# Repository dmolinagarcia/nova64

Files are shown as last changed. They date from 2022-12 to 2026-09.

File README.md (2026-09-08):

# noVa64 

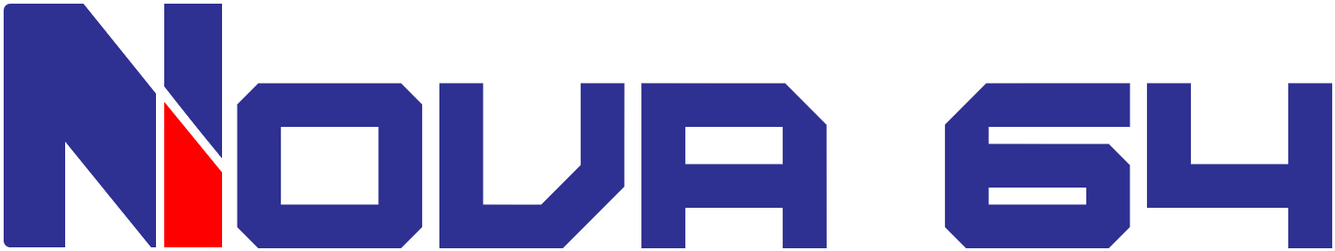
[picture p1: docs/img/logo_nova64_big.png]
noVa64 logo


**What it is noVa64?**

The noVa64 (With an uppercase V) is a new computer built around the 65816 CPU. Inspired by the age of 8-bit computers, it's envisioned as a alternate-universe succesor to the Commodore 8-bit series of computers. Instead of adquiring the Amiga, could've Commodore created a 16-bit machine around this CPU? The noVa64 is designed and built by a hobbyist (me) who will need to learn pretty much everything on the go.

**What it isn't noVa64?**

It's not a professional or commercially viable product.  It's not meant to be mass produced. It's not a recreation of any pre-existing computer, although it will be inspired by many.

**When will it be ready?**

Hopefully, at some point. That's all I can say.

## Principles

- Not here for the money. This is not meant to be a commercial product
- Hence, no restrictions on parts (Used, obsolete, questionable sources)
- Learn from scratch. No off-the-shelf solution
- Inspiration on others is encouraged though
- Give credit to all sources of information
- Everything will be open sourced, under the GNU v3 License
- Log all the steps
- No deadline. 
- Learn
- Have fun

## Requirements

### Form factor

- Computer should be a laptop, fully portable

### Power

- Single and low voltage. 5v is very obsolete. At least 3.3v, maybe even lower
- Battery powered
- USB-C Charger, allowing for fast charge if possible
- Battery pack reports to the computer. Charge status, capacity, etc
- Computer then display this

### CPU

- Based around a 65816. Real CPU, no FPGA here
- DRAM. Maximum memory at 16MB for the CPU 
- SRAM cache for the main DRAM

### Chipset

- Set of sustaining chips
- FPGA acting as MMU, handling DRAM, with potential for bigger RAM
- IO/TIMER. Could use a 6526 in FPGA maybe. TIMERs need to be driven by independent clock
- RTC. Used to keep time. Can act as TIMERS too for interrupts

### Video

- At least 640x400 (Twice a C64). 256 colors
- FPGA is allowed here
- Built in Laptop Screen
- External monitor an option (mirror, or extend if possible)
- VGA or HDMI for external monitor
- Brightness controlled via software
- Still not sure about dedicated video RAM

### Audio

- Stereo audio and built-in speakers
- FPGA is allowed here too
- External audio an option (Through audio jack, or, if possible HDMI)
- Volumen control through software

### Peripherals

- USB Support for storage, and HID
- Internal keyboard and trackpad are USB
- External ports too

### Storage

- Dual SD. One acting as internal hd, one acting as eternal storage

### Connectivity

- Is TCP/IP Possible? Wifi? Ethernet?

### Boot sequence

- Small ROM to handle booting. Then, SO from "INTERNAL" sd is loaded into meemory

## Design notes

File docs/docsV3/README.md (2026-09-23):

# docsV3 — the synthesis document, in Markdown

Same document as `docsV2`, same stylesheet, same look: only the source changed.
Each sheet is now a `.md` file under `content/`, and `index.html` turns it into
the page at load time with `md.js` (renderer) and `app.js` (shell and router).
Nothing in `docsV2` was touched — this is a parallel copy.

```
index.html          the paged edition: one sheet at a time
full.html           every sheet in one scroll, for printing
theme.js            the light/dark switch, applied before the first paint
md.js               markdown → HTML for the dialect below
hl.js               syntax highlighting for fenced code blocks — a per-language
                    scanner, not a parser, in the document's own five colours
shell.js            figure inlining and the failure state, shared by both pages
app.js              sidebar, masthead, sheet index, pager, title block, routing
full.js             the same pieces, assembled as one continuous document
manifest.json       the parts registry, and the sheet list: letter, part, area, nav
                    and index titles, figure
tools/prerender.js  assembles the printable edition ahead of time, for a PDF
                    formatter — page numbers live there, see Printing
tools/links.js      the cross-reference listing: source sheet -> linked section,
                    per sheet or whole-document, and the broken links, see Routes
tools/numbers.js    assigns the figure and table numbers across the reading order
                    and writes numbering.json — see Figure and table numbers
numbering.json      those numbers, the one derived thing this document stores
                    because a single sheet cannot work it out; committed
style.css           docsV2's stylesheet, plus the few rules these two pages add
content/*.md        the prose — one file per sheet
figures/*.svg       the diagrams, one file each
```

## Parts, areas, sheets

Three levels, and only `manifest.json` knows about any of them.

**A part** comes from the `parts` array, which is a *registry* rather than a run:
it fixes the order of the parts and their display names, and it is why a part
holding no sheets still appears in the sidebar and the index. Each sheet names
one with a `part` field.

```json
"parts": [
  { "id": "hardware", "num": "2", "name": "Hardware", "note": "" }
],
"sheets": [
  { "file": "sec_c", "letter": "C", "part": "ai", "area": "Power", … }
]
```

**An area** is still a run: consecutive sheets *within a part* carrying the same
`area` get one heading in the sidebar, one band in the sheet index, and one rule
across the page on `full.html`. A part gets the same treatment one level up — a
framed bar, and its own page in print, with its first area following on it.

**The order is: parts as the registry lists them, sheets as the array lists them
within each part.** So moving a sheet to another part is a **one-field edit** —
change its `part`, and the sidebar, the index, the numbering and the printed
page breaks all follow. Moving a sheet within its part still means moving its
row. A sheet naming a part that is not in the registry is not dropped: it lands
in a trailing "Unassigned" group that says so.

**Positions are derived, never stored.** There is no `num` field: `NovaShell.prepare`
resolves parts and areas into one reading order and numbers the sheets from it,
so inserting a sheet anywhere renumbers the rest by itself.

**So is the masthead's reference line.** `footer.referenceIndex` may contain
`{parts}`, `{areas}` and `{sheets}`, and `prepare` fills them from what it has
just resolved — the registry, the named area runs inside it, and the reading
order. It used to spell the sheet letters out, which left it a little further
from the truth after every split.

**The title block's revisions are a list.** `footer.revs` holds one entry per
area — `"POWER REV C"` — and `shell.js` sets each on a line of its own, so the
cell stays readable as the areas multiply. Under them, ruled off, `footer.version`
and `footer.date` close the block.

**The letters follow neither, and are never reissued.** A letter is a sheet's
identity — the file name (`sec_r.md`), the route (`#/sec_r`), and every
cross-reference in the prose — while its number is only its position. The two
stopped agreeing when the areas were introduced, and that is the point:
reordering the document costs a manifest edit instead of several hundred link
rewrites.

**Everything currently sits in the `ai` part**, which is where a sheet lives
until a human has read it; it moves to its real part when it has been reviewed.
Six of the seven parts are therefore empty, and that is the state of the review
rather than a hole in the design.

## Running it

The sheets are read with `fetch()`, which browsers refuse over `file://`, so
open it through a server — any server:

```
python3 -m http.server -d docs/docsV3
```

then <http://localhost:8000/>. On GitHub Pages it works as-is: the `.md` files
carry no YAML front matter, so Jekyll copies them through untouched.

## Printing

`full.html` is the same content with the sheets chained one after another —
masthead, sheet index, then the parts and their areas in order — and it is what
to send to the printer or save as PDF. It prints in sections: the masthead is
the cover and has the first page to itself, page two is left blank behind it,
the sheet index takes page three, and every part and every area opens on a fresh
page, while within an area the sheets run on rather than each claiming one. The
cover's drop — how far down the page the title block sits — is
`body.full .main{ padding-top }` in the print block, in millimetres. The print
stylesheet drops the sidebar and the navigation the way it always did. The sheet
index becomes a working table of contents, because on that page every
cross-reference is an in-page jump: ids are prefixed with their sheet
(`#sec_p-e2`, `#sec_ai_f-f-memmap`) so that E.2 in sheet E and E2 in sheet P stop
colliding, and so that two sheets may each anchor a figure of their own. The
sidebar of the paged edition links to it at the bottom of the sheet list.

### Figure and table numbers

A caption declares an identifier and never a number:

```markdown
![F.memmap.Memory structure. The SRAM hangs off the CPU's own nets.](figures/fig-4-memory-map.svg)

![T.banks.The sixteen banks and what each holds]

| Bank | Holds |
|---|---|
```

and the prose points at that identifier — `![F.memmap]`, `![T.banks]` — which
renders as `Figure 7` or `Table 3`, linked. **No number is ever written by
hand**, so inserting a figure renumbers the set and leaves every cross-reference
already correct. An identifier is `[A-Za-z0-9_-]+` and **may not contain a
dot**, which is what lets the first dot after `F.`/`T.` close it. A table with
no caption above it is not numbered and does not reach the list of tables —
most tables are a paragraph's worth of detail, not a numbered exhibit.

The numbering runs across the whole document in the reading order `prepare`
resolves, figures and tables in separate sequences. That is the one thing a
single sheet cannot work out for itself: `index.html` renders one sheet at a
time, and the number of a figure in sheet F depends on how many stand ahead of
it everywhere else. So it is worked out once, ahead of time:

```
node tools/numbers.js            assign the numbers, write numbering.json
node tools/numbers.js --check    verify it is current — exit 1 if not
```

`numbering.json` **is committed**, unlike `print.html` and `pdfs/`: GitHub Pages
serves `docs/` verbatim with no build step, so an artefact left out of the
commit is a 404 in production. Run `--check` before committing and before a PDF,
alongside `tools/links.js --broken`; it also catches a duplicate identifier, a
reference that resolves to nothing, a caption with no table under it, and a
missing SVG. Without the file the pages still render — every number shows as
`?` and every reference as `⟨F.memmap⟩` — because the markdown may well land in
a checkout before the artefact is regenerated, and a document that refused to
render would be the worse failure.

`FIGURES` and `TABLES` put the generated lists in a sheet ([Z2](content/sec_ai_z2.md)),
which is why those appendices hold no table of their own.

### Page numbers

Two things the browser cannot do: a running page number in the bottom margin,
and the page a sheet opens on beside its row in the index. Both are CSS paged
media — `@page` margin boxes and `target-counter()` — and **no browser
implements either**, so Chrome and Firefox drop those rules and print exactly
what they printed before. They need a formatter, and a formatter needs a static
file, because `full.html` assembles itself in JavaScript and WeasyPrint and
Prince do not run any.

```
node tools/prerender.js          # -> print.html, beside index.html
weasyprint print.html nova64.pdf
```

`tools/prerender.js` does not reimplement anything: it runs the real `md.js`,
`hl.js`, `shell.js` and `full.js` under Node against the real manifest and markdown,
captures what they would have written into the page, inlines the figures the way
`shell.js` does in the browser, and writes one static file that links the same
stylesheet. Change a sheet or the manifest and it follows. `print.html` is a
build artefact and is not committed.

Any formatter that implements paged media will do — `npx @vivliostyle/cli build
print.html -o nova64.pdf` is the other open one, and Prince is the best output if
its licence suits. WeasyPrint prints a column of warnings about screen-only rules
it cannot parse (`::-webkit-scrollbar`, `position:sticky`, `fill` inside the SVG
rules); all of them are screen or SVG presentation and none affects the PDF.

**Only the sheet rows carry a number.** A part or an area opens on the sheet
immediately below it, so numbering those rows would print the same number twice.
The cover and the blank verso behind it carry none either, which keeps every
printed folio equal to the page number a PDF reader shows.

## Light and dark

The button above the masthead switches themes; the choice is remembered in
`localStorage`, and until one is made the page follows the system setting. The
palette is six custom properties on `:root` — ground, ink, panel, mint, gold, and
`warn` for the warning box alone — and the light theme only redefines those, so
nothing else in the stylesheet knows a theme exists. The first five are the
document's look and every rule draws on them; the sixth is deliberately spent on
one construct, because a warning wearing the gold would be read as a milestone.

**It stops at the screen.** The light theme lives inside `@media screen`, and
the print block restates every colour itself, as it already did for docsV2's
dark ground. Printing from either theme gives the same black-on-white page.
The one thing a new colour needs is care in two places: shapes inside the
figures that carry their colour as an attribute rather than a class are listed
explicitly in both the print block and the light theme.

## Routes

`#/` is the sheet index, `#/sec_e` a sheet, `#/sec_e/e4` a sheet scrolled to one
of its items. Inside the markdown you write the target the way docsV2 wrote
filenames — `[sheet E](sec_e)`, `[F.4](sec_f#f4)`, `[Sheet index](index)` — and
the renderer turns it into the route.

`tools/links.js` lists them. It reads every sheet the way `md.js` does, resolves
each target against `manifest.json` and the items the target sheet actually
defines, and prints one line per link — source file, then the section it points
at:

```
node tools/links.js              # the listing, grouped by source sheet
node tools/links.js --reverse    # the same links, grouped by target
node tools/links.js --broken     # only the ones that resolve to nothing
node tools/links.js --csv        # source,line,text,target,anchor,item,status
node tools/links.js --summary    # links out and in per sheet, and the orphans
```

Name a sheet — as `sec_q` or as `content/sec_q.md` — and the listing narrows to
it: what it links out to, then what links in, with the item on each end. That is
what to run before moving a sheet or rewriting one of its items, since the IN
list is exactly what would have to be corrected.

```
node tools/links.js sec_q             # both directions for sheet Q
node tools/links.js sec_q --broken    # only the broken ones, either way
node tools/links.js sec_q --csv       # the same rows, as CSV
```

A link to a sheet that does not exist, or to an item id no sheet defines, is
reported as broken and the exit status is 1, so it also stands as a check.

## The dialect

A sheet file opens with its title and its aim, and everything after that is
content:

```markdown
# Vision and philosophy
> what it is · what for · under what rules

Project framework: what is being built, and what principles govern it.
```

`#` becomes the sheet heading, `>` the small uppercase aim beside it. The sheet
letter and number are not repeated here — they live in `manifest.json`.

### Blocks

| You write | You get |
|---|---|
| a plain paragraph | `p.lead` — the standing text of a sheet |
| `## Register map — base block $FF:0000` | sub-heading: bold up to the ` — `, plain after it |
| `### Hardening door B` | the same, one level down and a little tighter |
| `- A.1 — text` | a numbered item: `A.1` in bold at the head, text beside it, anchored at `#a1` |
| `1. text` | the same row, its number where the id would be, and no anchor |
| `  1. text` indented under an item | a numbered list inside the item: the written number hung in the margin, one line per entry |
| `- [ ] E0.1 — text` | the same, with a build checkbox in front |
| `!!! APPLE II MILESTONE — …` | the milestone banner — a framed band with a `■` at its head |
| `!! AVISO — …` + the lines under it | the warning box — see below |
| `\| Term \| Meaning \|` + `\|---\|---\|` | `table.simple` |
| `![F.id.Description](figures/f.svg)` | the figure, its SVG inlined so the stylesheet reaches it — captioned `Figure 7.` and anchored at `#f-id` |
| `![T.id.Description]` above a `\|`-table | the table's caption, `Table 3.`, anchored at `#t-id` |
| `LEGEND: …` after a figure | the small trace legend under the caption |
| ` ```c ` … ` ``` ` | a code listing, highlighted for that language — see below |
| ` ~~~bash ` … ` ~~~ ` | the same, for a listing that itself contains a line of backticks |
| `---` on its own line | nothing — a rule, dropped, since the sheets space themselves |
| `<!-- file: srv/dev/bin/dev -->` + a fence | a file of the kit: the listing under a caption naming it — see below |
| `INDEX` | the sheet-index table, built from `manifest.json` |
| `FIGURES` · `TABLES` | the list of figures, or of tables, built from `numbering.json` |
| `TAGS:` + `- [g] …` list | the masthead tag row (index page only) |

Checkbox states: `[ ]` pending · `[x]` done · `[~]` in progress · `[?]` optional.
The item id is free text — `A.1`, `E0.1`, `D07`, `+` — and its anchor is that id
lowercased with the dots dropped, which is what every cross-reference points at.

### The warning box

`!!!` is a milestone and `NOTE:` is an aside; neither is a warning, and the one
the sheets actually need — the step that can cost the reader money — was coming
out as the dimmest line on the page. `!!` is the third thing: a framed box on a
tinted ground with a thick rule down its left edge, in a red-amber that belongs
to it alone.

```markdown
!! AVISO — this step can cost you money.
Free-tier limits change, and a mistyped shape can leave a billable instance
running. Check the shape before you confirm it.
  A second paragraph inside the box, indented like any continuation line.
```

The `!!` line is the box's heading — bold up to the ` — `, plain after it, the
way a `##` sub-heading reads — and the lines under it are its body, **through
the next blank line**. Unindented lines run together into one paragraph; an
indented line opens another, exactly as it does under an item — with no blank
line before it, since a blank line is what closes the box. The inline pass
applies throughout, so links, `code` and chips work inside. A `!!` line on its
own, with no body under it, is a legal one-line warning.

On paper the ground goes and the left rule stays, darkened — the same treatment
the chips and the figure traces get. No mark in the document is told apart by
its colour alone, which is the rule sheet A states as A.17: the box is known by
its rule, a blocking chip by its fill against an open one's frame, and a trace
by its pattern and its weight. Colour repeats those on screen and adds nothing
the paper edition loses.

### Code listings

A fenced block, with the language after the opening fence. It may sit at the
margin or hang off an item like a `NOTE:`, and the fence's own indentation is
stripped either way, so both read the same. `~~~` opens and closes one too, and
is closed only by `~~~` — which is what a listing containing a line of backticks
needs, and the reason sheet EM0 can carry the script that extracts sheet EM0. The content is verbatim — no inline
pass, so `**` and `[link]()` inside a listing stay as typed.

`hl.js` highlights it while the page is built, not in the browser, because
`tools/prerender.js` runs the same renderer to make the printable edition:
highlighting at render time is what puts colour in the PDF. Six token classes,
because the palette has five colours and no more — comment, string, number,
keyword, type, directive — and they resolve to gold for literals, mint for
names, dimmed italic for comments, in every theme and on paper.

It knows `c`, `asm` (ca65 65816), `js`, `json`, `python`, `sh` and `make`.
**An unknown or absent language is escaped and left plain**, which is the right
answer for a register bit-layout or a vector table, and the reason to leave the
fence bare when a listing is not code.

### Files the document carries

A listing under a `<!-- file: path -->` marker is not an illustration: it is one
of the files the document *is*, and the marker is what the extractor at the top
of sheet EM0 reads to write it out. The renderer reads the same marker and draws
one distinction from it, which is what keeps the printed edition a book rather
than a program listing.

The listing gets a caption naming the file and giving its size, as lines and
bytes — checkable at the other end with `wc -lc`, which is the reason it is a
size rather than a hash. **Past `LONG` lines in `md.js`, the block also folds on
screen and prints as its caption alone**, since the document tells the reader
never to retype these files and paper is the one medium they cannot be copied
from. Below that threshold a file prints whole, so the configuration a reader
wants in front of them stays in the book while the long shell scripts do not.

Sheet EM0 is the case this exists for: eleven files, of which four are long
enough to fold, and the rest of its fenced blocks are ordinary listings that
carry no marker and are unaffected.

It is a scanner, not a parser: it recognises comments, strings, numbers and
words, and nothing about grammar. A label sharing a name with a mnemonic will be
coloured as one. That is the deliberate ceiling — a real tokeniser is not worth
carrying into the PDF build for a document whose listings are illustrations.

### Lines that attach to the block above

```markdown
- E1.2 — **Cross-review before layout.**
  TEST: clean ERC, plus a manual pin-by-pin pass of every TQFP.
- E0.6 — **Freeze the block diagram** as the schematic's reference.
  NOTE: Currently at REV B and well behind this document (→ [A.7](sec_a#a7)).
```

`TEST:` renders as the *TEST ▸* line, `NOTE:` as the dimmed aside. Both
also work under a paragraph or a `##` sub-heading.

Any other indented line attaches the same way, but as a further paragraph of the
block at full weight — one line, one paragraph — so an item that needs to run on
does so without leaving its number:

```markdown
- A1.1 — v0.2 of this documentation is the result of a very long dialogue…
  noVa64 is an amateur project. There will be lots of errors…
```

### Inline

| You write | You get |
|---|---|
| `**bold**` · `*italic*` · `` `code` `` | `<b>` · `<i>` · `<code>` |
| `[text](sec_q#q8)` | a link, rewritten to the route `#/sec_q/q8` |
| `[[open]]` | an outline chip |
| `[[!blocking]]` | a filled chip |
| `((an aside))` | an inline `.note`, for when it sits mid-sentence |
| `![F.id]` · `![T.id]` | `Figure 7` · `Table 3`, linked to it — never a number written by hand |
| raw HTML | passed through — the escape hatch, used by the figure legends for their line samples |

## Adding a sheet

Write `content/sec_s.md`, add its row to `manifest.json` (`file`, `letter`,
`part`, `area`, `nav` for the sidebar, `index` for the index table). Sidebar,
index, pager, numbering and title block follow from that; no HTML to edit.

Put its row next to the other sheets of the same area **inside its part** — the
array's order is what the reader sees within a part. There is nothing to
renumber: positions are derived from the resolved order.

A new sheet starts in the `ai` part unless it was written by a human, in which
case it goes straight to the part it belongs to.

The appendix is deliberately the **last** thing in the document and deliberately
lettered **Z**, and it is two sheets: the glossary in `content/sec_z1.md` and the
index of figures in `content/sec_z2.md`. Content sheets run A, B, C… and a new
one takes the next free letter of that run, without the appendix having to move
or any letter having to be reissued — which is also why splitting the appendix
took a suffix rather than the next free letter. Letters and file names are kept
in step — sheet R lives in `sec_r.md`, appendix sheet Z2 in `sec_z2.md` —
because every cross-reference in the prose points at the file name.

**A numeric suffix means one subject too large for one sheet**, and there are
three such runs. `Z1`/`Z2` is the appendix. `Y1`/`Y2`/`Y3` is the filesystem
stack — the VFS layer, NVFS and ext2 — which is one subject three ways rather
than three subjects, and which took a suffix for the same reason the appendix did
rather than because the alphabet had run short. `P1`/`P2`/`P3`/`P4` is the build,
one sheet per phase. Item ids inside a suffixed sheet carry the whole letter:
`Y2.15` anchors at `#y215`, and cross-references are written
`[Y2.15](sec_y2#y215)`.

**The build sheets are the one place where item ids and stage ids sit side by
side, and they are different things.** A dotted id is a discussion item and takes
the sheet's letter — `P2.11a` on sheet P2, `P4.3` on sheet P4. An undotted id is
a build stage and takes its *series* letter, which is independent of the sheet it
is printed on: the S-series on P1, the P-series on P2, the E-series on P3, the L
and F series on P4. So `P3.d` is a substep of prototype stage P3 and lives on
sheet P2, while sheet P3 holds `E0.1` through `E8.1`. Series ids never move when
a sheet is split; that is what kept the split from rewriting several hundred
references.

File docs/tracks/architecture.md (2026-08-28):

---
layout: track
track: architecture
title: "Track · Architecture"
permalink: /tracks/architecture/
redirect_from: /categories/architecture
---

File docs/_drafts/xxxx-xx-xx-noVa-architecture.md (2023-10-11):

---
categories: architecture
---

Necesito un diagrama de bloques... que hay en la fpga?

cpu fpga
        uart
        hid
                keyboard
                console in
                mouse
        console out
        storage
        video
        cache
        powermanagement
        audio
        network
        6526 or equivalent?
        rtc? rtc será externo por consumo

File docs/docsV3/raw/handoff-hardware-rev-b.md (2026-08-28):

# DANI-65816 — Hardware Handoff (REV B)

**Date:** August 2026
**Scope:** Board-level architecture, memory hierarchy, pin budget, PTE format.
**Status:** Hardware frozen at block level. Ready for pin assignment and schematic capture.

---

## 1. Purpose of this document

This handoff captures the state of the DANI-65816 hardware design after the REV B
consolidation pass. It supersedes earlier notes where they conflict — in particular,
several components present in REV A have been **removed**, and the memory hierarchy has
been substantially simplified. Section 7 lists those removals explicitly so that no
obsolete part is carried forward into schematic capture.

The machine is an original portable computer built around the Western Design Center
W65C816S, a 16-bit CPU with a 24-bit address bus. It is not compatible with, and not
derived from, any existing 65816-based system. The design goal is a self-built portable
with virtual memory, memory protection, and a preemptive multitasking OS.

Two success milestones govern the project:

- **"Hito Apple II"** — the machine boots autonomously to a prompt.
- **"Hito Amiga"** — preemptive multitasking with a windowed GUI.

---

## 2. Global constraints

These constraints are non-negotiable and have driven most of the decisions below.

| Constraint | Consequence |
|---|---|
| All parts hand-solderable (TQFP / PLCC / TSOP, ≥0.5 mm pitch) | BGA packages excluded; iCE40 in TQ144 chosen over ECP5 in BGA256 |
| Single 3.3 V I/O rail | DDR3 excluded (1.35/1.5 V); SDR SDRAM and asynchronous SRAM retained |
| Fully open toolchain | Lattice iCE40 with Yosys / nextpnr / IceStorm |
| Portable form factor | Battery, charger, fuel gauge, integrated panel |

---

## 3. Board block architecture

```
   USB-C ──┬── MCP73871 (charge + power path) ── LiPo 1S ── MAX17048 (fuel gauge)
           │        │
           │        └── TPS63020 ── 3.3 V system rail ── LDO 1.2 V (3× FPGA cores)
           │
           └── RP2040 (embedded controller)
                 ├── config SPI ──────► FPGA-A, FPGA-B, FPGA-C
                 ├── SPI ─────────────► microSD (muxed with FPGA-A)
                 ├── PIO-USB host ────► USB-A (keyboard / mouse HID)
                 ├── I2C ─────────────► MAX17048, GT911 touch
                 └── USB-CDC ─────────► debug console

   W65C816S (PLCC-44 socket) ──┐
                               ├── shared 65816 bus ──► FPGA-A
   FPGA-C (softcore, optional)─┘

   FPGA-A (iCE40HX4K TQ144) — MMU, cache controller, peripherals
       ├── shared 16-bit parallel bus ──► SRAM 2 MB + SDRAM 32 MB
       └── VRAM_SEL / IRQ VSync ────────► FPGA-B

   FPGA-B (iCE40HX4K TQ144) — video and audio
       ├── local PSRAM 8 MB (chip RAM: framebuffer + audio buffers)
       ├── RGB-TTL ──► 10.1" 1024×600 panel (ER-TFT101-1, HX8282)
       └── I2S ─────► PCM5102A DAC
```

---

## 4. Component decisions

### 4.1 CPU

- **W65C816S in a PLCC-44 socket.** Socketed rather than soldered so the part can be
  swapped or removed during bring-up.
- **PHI2 is generated by FPGA-A**, not by an external oscillator. This allows clock
  stretching on cache miss, variable clock for power saving, and exact CPU/MMU
  synchronisation.
- **Bus arbitration via BE (Bus Enable).** Driving BE low tri-states the real CPU, which
  allows the optional softcore in FPGA-C to drive the *same* physical traces. No second
  footprint and no desoldering: the real CPU can remain in its socket permanently.
- The bank address (A16–A23) is multiplexed onto the data bus during PHI2 low and is
  latched **inside FPGA-A**. No external '573 latch is required.

### 4.2 FPGAs

Three iCE40HX4K devices in TQ144 packages. All three are configured by the RP2040 over
slave SPI at power-up.

| Device | Role | Populated |
|---|---|---|
| FPGA-A | MMU, cache controller, memory arbitration, peripherals | Always |
| FPGA-B | Video and audio | Always |
| FPGA-C | Softcore 65816 | Optional, unpopulated initially |

Moving the softcore out of FPGA-A into its own device returns block RAM and routing
resources to the memory subsystem, and lets the softcore's clock be optimised
independently of MMU timing.

**Known iCE40 limitation:** block RAM is approximately 16 KB per device. This is far too
small for flat page tables and is the direct cause of the memory layout in section 5.

### 4.3 Memory (FPGA-A)

| Part | Size | Interface | Role |
|---|---|---|---|
| IS61WV102416 | 2 MB | 16-bit async, 10 ns | Cache + page tables + pinned region |
| W9825G6KH | 32 MB | SDR SDRAM, 16-bit, 3.3 V | Main memory (physical frame pool) |
| microSD | — | SPI | Boot, filesystem, swap |

Both memories **share the same 16-bit parallel data bus and low address lines.** The
SDRAM requires only 7 additional control signals (CLK, CKE, CS, RAS, CAS, DQML, DQMH)
beyond what the SRAM already needs.

**Trade-off accepted:** because the bus is shared, a cache line fill serialises —
SDRAM burst into the FPGA, then FPGA out to SRAM, rather than overlapping. Miss latency
rises accordingly, but remains in the 200–300 ns range, far better than the QSPI PSRAM
path it replaced.

### 4.4 Video and audio (FPGA-B)

- **Panel:** ER-TFT101-1, 10.1", 1024×600 IPS, HX8282 controller, FPC-50, driven
  directly by RGB-TTL from the FPGA. Timing is generated natively; there is no scaler.
- **Pixel doubling:** the internal framebuffer is 512×300 and is doubled to 1024×600 on
  output. This keeps memory bandwidth within budget.
- **Local PSRAM (APS6404L, 8 MB)** serves as chip RAM for double-buffered framebuffer
  plus audio buffers. This is the one PSRAM that survives in the design — FPGA-B needs
  local memory with its own access path and cannot share FPGA-A's bus.
- **Bus topology is Amiga-style:** FPGA-B taps the CPU bus directly. The CPU writes VRAM
  through a 64 KB aperture at bank `$FE`, gated by a VRAM_SEL signal from the MMU. There
  is no dedicated inter-FPGA link.
- **Audio:** PCM5102A I2S DAC driven by FPGA-B. Backlight brightness is PWM from FPGA-B
  into a boost converter.
- **Touch:** GT911 capacitive controller on I2C, handled by the RP2040.

### 4.5 Embedded controller (RP2040)

The RP2040 fills the role of the small management microcontroller, and additionally
provides native USB. Responsibilities:

- Power sequencing and rail control; battery management via MAX17048 over I2C.
- Configuration of all three FPGAs over slave SPI (CRESET_B / CDONE handshake).
- BIOS preload: reads the BIOS image from microSD and writes it into system RAM before
  releasing CPU reset.
- USB-CDC debug console.
- USB HID host via PIO-USB, feeding keyboard and mouse events to FPGA-A.
- Its own firmware lives in a W25Q16 SPI flash and is updated over USB (UF2).

### 4.6 Power

```
USB-C ─► MCP73871 (charge + power path) ─► VSYS ─► TPS63020 buck-boost ─► 3.3 V
                                                       ├─► LDO 1.2 V (3× FPGA cores)
                                                       ├─► TPS61023 boost 5 V (USB VBUS)
                                                       └─► PT4110 boost (backlight)
LiPo 1S 3.7 V ── MAX17048 fuel gauge (I2C: state of charge, voltage, alerts)
```

The MCP73871 power-path topology allows the machine to run from USB with a fully
depleted battery. FPGA VPP (2.5 V) is derived through BAT54 diodes.

---

## 5. SRAM partitioning

The 2 MB SRAM is divided by address range in FPGA-A gateware. It is a single physical
chip; the partitioning exists only in the memory controller's decode logic.

| Range | Size | Contents |
|---|---|---|
| `$000000–$0FFFFF` | 1 MB | Cache: 4096 lines × 256 B |
| `$100000–$17FFFF` | 512 KB | Page tables: 16 contexts × 32 KB |
| `$180000–$1FFFFF` | 512 KB | Pinned region: kernel and per-process bank `$00` |

Three consequences worth carrying forward:

1. **The pinned region is a physical address range, not cache lines marked
   non-evictable.** Accesses to bank `$00` bypass tag lookup entirely and complete in a
   single cycle with fixed latency. This is both simpler and faster than the previous
   scheme.
2. **The hardware page-table walker becomes trivial.** With tables in 10 ns SRAM, a walk
   is one add and one read: `$100000 + context×32K + VPN×4`, two 16-bit accesses,
   roughly 4 cycles. A software TLB-miss trap is unnecessary; the OS only ever
   manipulates tables, never the TLB directly.
3. **Block RAM is freed for its proper use:** the TLB, cache tags (4096 tags fit in
   about 6 KB), and FIFOs.

---

## 6. Page table entry format

```
 31                            16 15 14 13 12 11 10  9  8  7        0
┌────────────────────────────────┬──┬──┬──┬──┬──┬──┬──┬──┬──────────┐
│         FRAME[15:0]            │P │W │X │U │D │A │NC│PIN│ SW[7:0] │
└────────────────────────────────┴──┴──┴──┴──┴──┴──┴──┴──┴──────────┘
```

Page size is 2 KB, giving 8192 pages per process and a **32 KB flat page table per
process** (8192 entries × 4 bytes). Sixteen contexts therefore occupy exactly the 512 KB
table region defined in section 5.

Note that this supersedes an earlier estimate of ~16 KB per table, which assumed 2-byte
entries. The 32-bit PTE is what makes the 16-bit frame field — and the 128 MB ceiling —
possible.

**FRAME[15:0]** — physical frame number. Physical address = FRAME × 2048 + offset(11
bits) = 27 bits, giving a **128 MB physical ceiling**. Current frame map:

- `$0000–$3FFF` — SDRAM, 32 MB
- `$FF00–$FFFF` — the 512 KB pinned SRAM region (256 frames)
- Intermediate range reserved for future expansion

**Hardware-checked flags:**

| Bit | Name | Behaviour |
|---|---|---|
| P | Present | P=0 on any access → ABORT. When P=0, bits 31–16 are free for the OS to store the swap slot on SD |
| W | Writable | Write with W=0 → ABORT. Also provides copy-on-write |
| X | Executable | Fetch with X=0 → ABORT. The 65816 **VPA** signal identifies instruction fetch cycles, so the check is a simple AND |
| U | User-accessible | User-mode access with U=0 → ABORT |
| D | Dirty | Set by hardware via read-modify-write to the PTE in SRAM |
| A | Accessed | Set by hardware; OS reads and clears to select swap victims |
| NC | Non-cacheable | Frame bypasses the cache |

**Software-only bits:** PIN (do not evict — ignored by the walker) and SW[7:0], free for
the OS (age counter for replacement, COW marker, and so on).

**Privilege mode.** The 65816 has no privilege bit, but it does assert **VPB** (vector
pull) when reading an interrupt or COP vector. The MMU uses VPB to switch to supervisor
mode automatically. Returning to user mode is a write to a register in bank `$FF`, which
is itself only writable in supervisor mode — the self-protecting keystone of the
protection scheme.

**TLB entry:** `VPN(13) + ASID(4) + FRAME(16) + W, X, U, NC` ≈ 37 bits. Including the
ASID (the context number) avoids flushing the TLB on every context switch; switching
processes remains a single register write with no collateral cost. 64–128 entries in
block RAM are sufficient for a 65816 working set.

**Fault registers in bank `$FF`** required by the ABORT handler:

- `FAULT_ADDR` — faulting virtual address, 24 bits
- `FAULT_CAUSE` — ¬P / ¬W / ¬X / ¬U, plus a fetch/data bit
- `CONTEXT` — active ASID
- `MODE` — supervisor/user, writable only in supervisor mode

---

## 7. Removed from the design

These parts appeared in earlier revisions and must **not** be carried into schematic
capture.

| Removed | Reason |
|---|---|
| ECP5 FPGAs (BGA256) | Not hand-solderable; replaced by iCE40 TQ144 |
| Dedicated page-table SRAM | Needs ~35 pins; impossible in TQ144. Tables moved into the main 2 MB SRAM |
| 2× APS6404L PSRAM on FPGA-A | Superseded by SDRAM. Frees 12 pins and removes the QSPI controller — the most timing-sensitive gateware block in the design |
| W25Q128 BIOS flash | Pin budget conflict with SDRAM. Boot is SD-only; the RP2040's own flash is the silicon fallback |
| ANX6345 eDP bridge | Panel is driven directly by RGB-TTL. Deferred to a later build stage |
| VGA output and R-2R DAC | Integrated panel is the primary display |
| 8×8 keyboard matrix | Replaced by USB HID via the RP2040's PIO-USB host |
| HDMI/DVI output | Deferred; differential pairs may be routed but not populated |

---

## 8. Pin budget — FPGA-A (iCE40HX4K TQ144)

107 usable I/O. CRESET_B and CDONE are separate; the four config SPI pins are
dual-purpose and reusable after configuration.

| Group | Signals | Pins |
|---|---|---|
| 65816 bus | D/BA0-7, A0-15, PHI2, RWB, VDA, VPA, RDY, ABORTB, IRQB, NMIB, RESB, BE, E | 35 |
| SRAM 2 MB | A0-19, D0-15, OE, WE, UB, LB (CE tied low) | 40 |
| SDRAM (incremental) | CLK, CKE, CS, RAS, CAS, DQML, DQMH — data and low address shared with SRAM | 7 |
| microSD | SPI ×4 (mux select driven by RP2040) | 4 |
| I2C | SDA, SCL | 2 |
| RP2040 link | config SPI reused post-config, plus UART | 2 |
| Inter-FPGA | VRAM_SEL, IRQ VSync, handshake | 3 |
| **Total used** | | **93** |
| **Free** | | **14** |

Suggested use of spares: activity LED, debug test points. During bring-up these are
worth more than any additional peripheral.

---

## 9. Layout notes

- SRAM and SDRAM must be placed physically adjacent and close to FPGA-A. The shared bus
  runs at approximately 100 MHz toward the SDRAM and will not tolerate long stubs.
- Data and address lines should be routed as a short comb between the two memories.
- 4-layer stackup (signal / GND / 3V3 / signal).
- JTAG accessible on each FPGA, or chained.
- Populate the first board in stages: power → RP2040 → FPGA-A → CPU → memories → FPGA-B.

---

## 10. Open items

**Immediate design decisions:**

- Context switch implementation: saving and restoring full CPU state, and notifying
  FPGA-A of the active process change to swap permission tables.
- Hardware watchdog converting a hung fill into NMI or ABORT.
- SDRAM auto-refresh interleaving during cache line fills.
- Glitch-free PHI2 gating, with correct minimum pulse widths on restart.
- BE arbitration protocol: who initiates the handover, what happens to PHI2 and RDY
  during the switch, and whether FPGA-C may run at its own higher clock against the same
  MMU.

**Blocking KiCad work:**

- ER-TFT101-1 datasheet needed for backlight current and voltage, and to confirm the
  capacitive touch variant. The panel must be ordered in the capacitive variant.

**Next documents to produce:**

- Physical pin assignment for FPGA-A TQ144, ensuring the SRAM/SDRAM bus falls in
  contiguous banks and the panel interface is grouped on FPGA-B.
- Kernel ABORT handler state machine: classify via FAULT_CAUSE, decide between allocate
  frame / fetch from swap / kill process, and return via RTI.

---

## 11. Reference artifacts

| File | Contents |
|---|---|
| `placa-65816.html` | REV B block diagram, PCB silkscreen styling |
| `resumen-dani-65816.html` | Project summary |
| `conceptos-memoria-virtual.md` | Virtual memory concepts |

**Toolchain:** KiCad (EDA) · Yosys, nextpnr, IceStorm (FPGA) · pico-sdk (RP2040) ·
Calypsi C, target WDC65816 · ca65 or 64tass (assembler).

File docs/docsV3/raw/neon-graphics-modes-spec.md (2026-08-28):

# Neon GPU — Graphics Modes and Command Engine

**Project:** DANI-65816
**Subsystem:** Neon (FPGA-B)
**Document:** Modes 1 and 2, Blitter, Command Processor
**Date:** 2026-08-14
**Status:** Draft — depends on unresolved items in the Text Mode Specification

---

## 1. Scope

Specifies **Mode 1 (hires monochrome)** and **Mode 2 (multicolour)**, the drawing engine that fills their framebuffers, and the command interface through which the 65816 drives that engine.

The governing requirement is the user's: *Neon must be able to generate the framebuffer without CPU intervention.* Everything below is arranged around that. Mode 0 (text) is specified separately and is unaffected.

---

## 2. Terminology

| Term | Definition |
|---|---|
| **Blitter** | Block image transferrer — a hardware engine that fills, copies, and combines rectangular regions of memory without CPU involvement. |
| **Command list** | A sequence of drawing commands stored in memory and executed autonomously by the graphics processor. |
| **Bank (SDRAM)** | One of four independently-addressable arrays inside the SDRAM device. Accesses to different banks can be interleaved without paying row-activation delay. |
| **Row activation** | The delay incurred when SDRAM must open a new row before data in it can be accessed (~60 ns). |
| **Colour key** | A palette index designated as transparent; pixels of that value are not written during a copy. |
| **Page flip** | Displaying one framebuffer while drawing into another, then exchanging them. |
| **Barrel shifter** | Combinational logic that shifts a word by any amount in one cycle; required to place 1-bpp images at arbitrary horizontal positions. |
| **Clock enable** | A signal that gates a register's update without gating its clock, used here to derive a slower rate inside one clock domain. |

---

## 3. Clocking — Revision to Earlier Assumption

The Text Mode Specification allocated both PLLs: one at 51 MHz for pixels, one at ~100 MHz for SDRAM. **This is unnecessary and should be changed.**

Choose the SDRAM clock as exactly **twice** the pixel clock:

```
DIVR = 0, DIVF = 33, DIVQ = 2  →  12 MHz × 34 / 4 = 102.000 MHz
```

Note this is the same `DIVF` as the 51 MHz setting; only `DIVQ` changes.

The entire design then runs in **one clock domain at 102 MHz**, with the pixel stage advancing on a clock enable asserted every second cycle. `PCLK` is emitted through a DDR output register, producing a clean 51 MHz panel clock with no combinational clock path.

Three consequences, all favourable:

1. **No clock-domain crossing.** No synchroniser FIFOs between scanout and memory. This removes an entire class of intermittent, hard-to-diagnose failures.
2. **The second PLL is freed** — available for audio, or held in reserve.
3. Refresh rate is unchanged at 59.76 Hz; the Text Mode Specification requires no other amendment.

> **Risk R-1.** 102 MHz is demanding for an iCE40 HX. SDRAM controllers at 100–133 MHz on this family are documented, but timing closure is not guaranteed until synthesis. **Fallback:** run the whole design at 51 MHz single-rate, halving peak SDRAM bandwidth to 102 MB/s. Every performance figure below would halve — and would still exceed CPU-driven rendering by more than an order of magnitude. The architecture does not depend on 102 MHz; only the margins do.

---

## 4. Memory Bandwidth Budget

Neon's dedicated W9825G6KH (32 MB, 16-bit) at 102 MHz gives **204 MB/s peak**.

Overheads: row activation costs ~20 clocks per 512-word row (~4% on sequential access); auto-refresh costs ~0.2%. Sequential throughput is therefore ~185 MB/s. For a mixed workload with bank switching, budget **~150 MB/s effective**.

| Consumer | Mode 2a | Mode 1 |
|---|---|---|
| Scanout | 3.8 MB/s | 4.6 MB/s |
| Hardware cursor | 0.1 MB/s | 0.1 MB/s |
| Audio DMA | 0.7 MB/s | 0.7 MB/s |
| CPU aperture writes | 1.6 MB/s (worst case) | 1.6 MB/s |
| **Remaining for the drawing engine** | **~144 MB/s** | **~143 MB/s** |

Scanout consumes under 3% of the memory system. **Bandwidth is no longer a design constraint for Neon.** The binding constraints are FPGA logic (§11) and EBR (§10).

---

## 5. Mode 1 — Hires Monochrome

| Parameter | Value |
|---|---|
| Resolution | **1024 × 600** — native, no replication, square pixels |
| Depth | 1 bpp |
| Framebuffer | 128 B/line × 600 = **76,800 B (75 KB)** |
| Bit order | MSB = leftmost pixel |
| Colours | Two palette indices, from `MONO_FG` / `MONO_BG` registers |
| Border | None — full panel |
| Aperture | 2 pages of 64 KB (`VRAM_PAGE` required) |
| Scanout | 4.6 MB/s |

This is the GUI mode. Full panel resolution with 1:1 pixels is what makes readable text and precise window furniture possible.

**The expensive part of Mode 1 is not the framebuffer — it is arbitrary-alignment blitting.** Placing an image at any horizontal pixel position in a packed 1-bpp buffer requires shifting each source word by 0–15 bits and merging across word boundaries, with edge masks at both ends. This is the classic Amiga blitter problem. Estimated cost: **~400 LUT** for the barrel shifter and mask generator. It is not optional — a GUI that can only draw at 16-pixel horizontal boundaries is not a GUI.

---

## 6. Mode 2 — Multicolour

Two sub-modes, differing only in the replication factor and buffer size. Both are 8 bpp with a 256-entry palette.

| | **Mode 2a** | **Mode 2b** |
|---|---|---|
| Logical resolution | 320 × 200 | 512 × 300 |
| Replication | 3 × 3 | 2 × 2 |
| Displayed area | 960 × 600 | **1024 × 600 — exact** |
| Horizontal border | 32 px each side | none |
| Vertical border | none | none |
| Framebuffer | **64,000 B** | 153,600 B |
| Aperture pages | **1** | 3 |
| Scanout | 3.8 MB/s | 9.2 MB/s |
| Double-buffered total | 128 KB | 300 KB |

**Mode 2a** is the recommended default for games: it is the familiar 320×200 geometry, its framebuffer fits inside a single aperture window with 1,536 bytes to spare, and its pixels are exactly square because the panel's are.

**Mode 2b** fills the panel with no border and costs only memory and bandwidth, both of which are abundant. It is the better choice for anything where the black side bars would be objectionable.

Both are supported by identical logic; the sub-mode is a register field controlling the replication counters and the line stride. Adding 2b costs approximately nothing.

Palette: 256 entries × 18-bit RGB666, held in EBR.

---

## 7. Hardware Tile Mode — Recommended Against

The C64's VIC-II synthesised its display from a character matrix because it had no framebuffer and no bandwidth for one. Neither constraint applies here. The relevant comparison:

**Redrawing a full 320×200 tilemap with the blitter:** 20 × 13 tiles of 16×16 px = 260 tiles × 256 B = 66,560 B of opaque copy. At ~100 MB/s for read+write, this is **~1.3 ms** — under 8% of a 16.7 ms frame.

The blitter can therefore rebuild the entire tiled background **every frame**, from scratch, and still leave 92% of the frame for everything else. Pixel-smooth scrolling comes free by offsetting the destination coordinates.

| | Hardware tile engine | Blitter redraw |
|---|---|---|
| Logic cost | ~800 LUT | 0 (blitter already required) |
| Scroll | Register write | Offset in the draw loop |
| Full-screen tile change | 2,000 B of tilemap | 1.3 ms of blitting |
| Composability with drawn graphics | Poor — separate layer | Native, same buffer |
| Tile size / shape | Fixed at synthesis | Arbitrary |

**Recommendation: do not implement a hardware tile mode.** It costs ~800 LUT on a device where logic is the binding constraint, to accelerate something the blitter already does in 8% of a frame, and it fragments the rendering model into two incompatible paths.

### 7.1 The same argument applies to hardware sprites

A full 32-sprite engine was estimated at ~1,000 LUT. Blitting 32 masked 16×16 sprites costs 32 × 256 B ≈ 8 KB of masked transfer — **~0.12 ms**, or 0.7% of a frame.

Hardware sprites exist to avoid the save/restore-background problem in systems that cannot afford to redraw. With double buffering and 32 MB of SDRAM, that problem does not exist: each frame is drawn fresh into the back buffer.

**Recommendation: no general sprite engine.** Retain only the **hardware cursor**, extended from Mode 0 to the graphics modes (16×16 or 32×32, 2 bpp, ~150 LUT). A GUI pointer must track the mouse independently of the rendering loop, so this one case is genuinely worth hardware.

Combined saving: **~1,650 LUT**, roughly 21% of the device — which is what makes §11 close.

> This is a recommendation with a real trade-off, not a settled decision. What is given up: sprites that composite at scanout cost no framebuffer bandwidth and cannot be "erased" by drawing, which simplifies certain effects. What is gained: a single rendering model, and the logic budget to fit the blitter, command processor, and audio on one device.

---

## 8. Drawing Engine

### 8.1 Operations

| Operation | Description |
|---|---|
| `FILL_RECT` | Solid colour fill |
| `FILL_PATTERN` | Fill with an 8×8 pattern from the pattern register |
| `COPY_RECT` | Opaque rectangular copy, overlap-safe (direction selected automatically) |
| `COPY_KEYED` | Copy, skipping pixels equal to the colour key |
| `COPY_TILED` | Copy with the source wrapped modulo its dimensions — texture fill |
| `COPY_EXPAND` | 1-bpp source expanded to two colours — glyph and icon rendering into Mode 2 |
| `DRAW_LINE` | Bresenham, arbitrary endpoints |
| `DRAW_HLINE` / `DRAW_VLINE` | Optimised axis-aligned cases |

All operations respect a clip rectangle set by `SET_CLIP`.

> **`COPY_TILED` is the interpretation of "apply texture" carried forward from discussion.** It fills a region by repeating a source bitmap — the QuickDraw / Amiga-blitter sense of texturing. **Perspective-correct 3D texture mapping is out of scope and not implementable on this device**: it requires a per-pixel divide, and the iCE40 has neither hardware multipliers nor the logic budget for them.

### 8.2 Measured cost per full-screen operation (Mode 2a, 64,000 B)

| Operation | Traffic | Time | vs. 65816 |
|---|---|---|---|
| `FILL_RECT` | 64 KB write | **0.31 ms** | 129× |
| `COPY_RECT` | 64 KB read + 64 KB write | **~1.0 ms** | 40× |
| `COPY_KEYED` | read src + read dst + write dst | **~1.5 ms** | 27× |
| `DRAW_LINE` | ~1 px/clock | 1024 px in 10 µs | — |

The 65816 reference is ~40 ms for a full-screen rewrite through the aperture at 8 MHz.

Source and destination should be placed in **different SDRAM banks** where possible; the controller interleaves them, avoiding row-activation stalls on every alternation. The command processor does not enforce this — it is a memory-layout convention for the kernel and for asset loaders.

### 8.3 Frame budget

At 60 Hz, one frame is 16.7 ms. After scanout, cursor, audio, and CPU aperture traffic, approximately **15.5 ms** is available to the drawing engine per frame. That is roughly:

- 50 full-screen fills, or
- 15 full-screen opaque copies, or
- 10 full-screen keyed copies, or
- a full tilemap rebuild (1.3 ms) plus ~100 masked 16×16 sprites plus ~200 UI rectangles, with time left over.

---

## 9. Command Interface

Three layers, each usable independently. Layer 3 is the one that satisfies "without CPU intervention"; layers 1 and 2 exist because they are needed first during bring-up.

### 9.1 Layer 1 — Register-driven (bring-up only)

Parameters written to registers, execution triggered by a `GO` bit, completion detected by polling `BUSY`. Simple, verifiable, and requires no FIFO or command decoder. It is how the blitter gets tested in isolation. It is not intended for production use — the CPU is occupied for the duration of every operation.

### 9.2 Layer 2 — Command FIFO

The CPU writes 32-bit command words to `CMD_PORT` (a single aperture address). Neon buffers them in a 128-entry EBR FIFO and executes them in order, asynchronously.

The CPU checks `CMD_FIFO_FREE` before writing a command's worth of words. Because the CPU produces roughly 1.6 MB/s and the engine consumes commands far faster than that, the FIFO does not fill under any realistic drawing load — a full-screen fill is 5 words in and 0.31 ms of work.

This alone decouples the CPU from drawing. It is sufficient for a GUI.

### 9.3 Layer 3 — Command lists in SDRAM

The `EXEC_LIST` command redirects the command processor to fetch its instruction stream from an address in SDRAM instead of from the FIFO. The list may contain any drawing command plus flow control:

| Command | Effect |
|---|---|
| `JUMP addr` | Continue at `addr` |
| `CALL addr` / `RET` | One level of subroutine nesting |
| `WAIT_VBLANK` | Suspend until the next vertical blanking interval |
| `WAIT_LINE n` | Suspend until panel line `n` — raster-synchronised effects |
| `SWAP_BUFFERS` | Exchange front and back buffers at the next vblank |
| `SET_PALETTE i, rgb` | Palette write, may be mid-frame after `WAIT_LINE` |
| `SIGNAL n` | Raise an interrupt to the CPU with tag `n` |
| `END` | Return to FIFO execution |

**This is the mode the user asked for.** A game builds its display list once, terminates it with `SWAP_BUFFERS` and `JUMP` back to the start, and the CPU is then free: Neon renders every frame autonomously, forever, until the list is modified. The CPU's per-frame work reduces to patching coordinates inside an existing list — a handful of 16-bit stores.

The model is the ANTIC display list and the Amiga Copper, generalised to include the blitter.

**Self-modifying lists are the intended usage pattern.** Because the CPU can write into a list while Neon executes it, moving an object is a store to the parameter word of an existing `COPY_KEYED` command. A `LIST_LOCK` bit is provided so the kernel can guarantee the engine will not read a partially-updated command; the engine finishes its current command and stalls at the lock.

### 9.4 Command word format

Word 0:

```
bits 31:24  opcode
bits 23:16  flags (clip enable, colour-key enable, direction, ...)
bits 15:0   word count of following parameters
```

Parameters follow as 32-bit words, packed as two 16-bit coordinates each where applicable. `FILL_RECT` is 5 words total; `COPY_KEYED` is 7.

Fixed-length-per-opcode encoding was rejected in favour of an explicit word count so that unknown opcodes can be skipped rather than desynchronising the stream — this matters when gateware and kernel versions drift during development.

---

## 10. EBR Budget

iCE40 HX8K: 32 blocks × 512 B = 16 KB total.

| Structure | Size | Blocks |
|---|---|---|
| Text buffer (Mode 0) | 8 KB | 16 |
| Font (Mode 0) | 4 KB | 8 |
| 256-entry palette | 1 KB | 2 |
| Scanout line buffer, double | 1 KB | 2 |
| Blitter source/destination burst buffers | 1 KB | 2 |
| Command FIFO (128 × 32-bit) | 512 B | 1 |
| Cursor pattern | 512 B | 1 |
| **Total** | **16 KB** | **32** |

**Exactly full, with zero margin.** This closes only because §7 removed the sprite pattern cache and tile store.

> **Open item O-3 (revised, now urgent).** The 8 KB text buffer and 4 KB font are idle in graphics modes. Multiplexing the text buffer's 16 blocks into graphics use would provide 8 KB of slack, at the cost of address multiplexers and of destroying screen contents on a mode switch — acceptable, since returning to text mode implies a redraw anyway. **The font must not be reclaimed**: its bitstream initialisation is what allows printing before any software exists, and reusing those blocks would destroy it. Decide once the blitter's real EBR demand is known from synthesis.

---

## 11. Logic Budget

| Block | LUT (est.) |
|---|---|
| Mode 0 (text) — from prior specification | 900 |
| SDRAM controller and 4-way arbiter | 1,200 |
| Graphics scanout (Modes 1, 2a, 2b, replication) | 400 |
| Blitter — 8-bpp path | 700 |
| Blitter — 1-bpp barrel shifter and edge masking | 400 |
| Line drawing | 250 |
| Command processor (FIFO, list fetch, decode, flow control) | 800 |
| Hardware cursor, graphics modes | 150 |
| Audio (reserved) | 800 |
| **Total** | **~5,600** |

Against 7,680 LUT: **73%**, leaving ~2,000 LUT of margin.

For comparison, the configuration including a tile engine and a 32-sprite unit came to ~7,300 LUT — 95% — which is not a routable design once the audio subsystem grows. The recommendation in §7 is what converts this from marginal to comfortable.

---

## 12. CPU Access to the Framebuffer — A Real Constraint

In graphics modes the framebuffer is in SDRAM, and SDRAM reads carry row-activation latency. Neon cannot stretch PHI2 to cover it, because doing so requires a wait line to FPGA-A and the architecture has eliminated the inter-FPGA link.

**Therefore: the graphics-mode aperture is write-only.** Writes are absorbed by a 32-entry FIFO and retired to SDRAM by the arbiter; the CPU never waits. Reads return `$FF` and set `STATUS.READ_FAULT`.

This is less restrictive than it sounds. Asset flow is one-way — microSD → system RAM → aperture → VRAM — and once the command engine is drawing, the CPU has no reason to read the framebuffer at all. Where a read is genuinely needed (screen capture, debugging), a `PEEK` mechanism is provided: write an address to `PEEK_ADDR`, poll `STATUS.PEEK_READY`, read `PEEK_DATA`. It is slow and intended for diagnostics only.

Mode 0 is unaffected: its buffers are in dual-port EBR and remain fully readable with zero wait states.

> **Open item O-4 (revised).** If a signal line from FPGA-B to FPGA-A is added for interrupts, one additional line would permit PHI2 stretching and make the aperture fully readable. This is worth weighing as a pair rather than deciding the interrupt line in isolation.

---

## 13. Staging

Each stage is a usable machine. If work stops at any stage, nothing is stranded.

| Stage | Content | Acceptance |
|---|---|---|
| **N0** | Mode 0 text (prior specification) | Console at power-on, RP2040 only |
| **N1** | SDRAM controller; Mode 1 scanout; register-driven fill and copy | Bitmap displayed; blitter fills a rectangle |
| **N2** | Mode 2a/2b; palette; 8-bpp blitter; `COPY_KEYED`; double buffering | Animated multicolour scene at 60 Hz |
| **N3** | 1-bpp barrel-shift blitter; `COPY_EXPAND`; graphics cursor | GUI primitives — *Amiga milestone reachable here* |
| **N4** | Command FIFO | CPU no longer polls `BUSY` |
| **N5** | SDRAM command lists, flow control, `WAIT_LINE`, `SWAP_BUFFERS` | Autonomous frame rendering — *games target* |
| **N6** | Line drawing, `FILL_PATTERN`, `COPY_TILED` | — |

Note that **N3 delivers the primary milestone and N5 delivers the games capability.** They are separable, and N3 comes first.

---

## 14. Open Items

| ID | Item | Blocks |
|---|---|---|
| **R-1** | Confirm 102 MHz timing closure on HX8K; fallback to 51 MHz | N1 |
| **O-3** | EBR reuse of the text buffer in graphics modes | N2 |
| **O-4** | FPGA-B → FPGA-A signalling: interrupt line, and whether to add a wait line with it | Pin assignment |
| **O-7** | Ratify or reject the §7 recommendation against tile mode and sprites | N2 logic budget |
| **O-8** | SDRAM bank-allocation convention for source/destination separation | Kernel memory manager |
| **O-9** | Whether Mode 2b (512×300) is built at all, or 2a only | N2 |
| **O-10** | Command list revision/versioning between gateware and kernel | N5 |

Items O-1, O-2, O-5, O-6 from the Text Mode Specification remain open and are not repeated here.

---

## 15. Decisions Superseded by This Document

| Superseded | Replaced by |
|---|---|
| Two PLLs — 51 MHz pixel, 100 MHz SDRAM, separate clock domains | Single 102 MHz domain, pixel clock enable; second PLL freed |
| Hardware tile mode as stage N4 | Blitter tilemap redraw; hardware tile mode not implemented |
| 32-sprite hardware engine | Blitted sprites; hardware cursor retained |
| "PSRAM bandwidth ~40 MB/s is the graphics budget" | Dedicated SDRAM, ~150 MB/s effective |
| Estimated ~7,300 LUT total for Neon | ~5,600 LUT after removing tile and sprite engines |

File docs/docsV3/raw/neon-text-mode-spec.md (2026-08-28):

# Neon GPU — Text Mode Specification

**Project:** DANI-65816
**Subsystem:** Neon (FPGA-B) — Graphics Processing Unit
**Document:** Text Mode (Mode 0)
**Date:** 2026-08-14
**Status:** Draft — provisional pending panel datasheet

---

## 1. Scope

This document specifies **Mode 0 (Text)** of the Neon graphics processor, implemented in FPGA-B. It defines display geometry, pixel timing, the text buffer and font storage model, the character attribute format, the CPU-visible register map, and the resource budget.

Graphics modes (framebuffer, blitter, sprites, tiles) are **out of scope** and are specified separately. Where a decision in this document constrains those modes, it is called out explicitly.

**Design intent:** Text mode is the *first* Neon deliverable and must be operational before any other Neon subsystem exists. It is therefore specified so that it depends on **no SDRAM controller, no arbiter, no FIFO, and no inter-FPGA link**. A working console is the debugging instrument for everything that follows.

---

## 2. Terminology

Terms are defined at first use. This section is a convenience index, not a substitute.

| Term | Definition |
|---|---|
| **Neon** | The combined graphics and audio processor implemented in FPGA-B. |
| **Cell** | One character position on screen: a glyph code plus an attribute byte. |
| **Glyph** | The pixel pattern for one character code, stored in the font. |
| **EBR** | Embedded Block RAM — dedicated dual-port memory blocks inside the iCE40 FPGA, distinct from logic (LUT) resources. |
| **Aperture** | The 64 KB window in CPU bank `$FE` through which the 65816 accesses Neon. |
| **Scanout** | The process of reading display data and emitting pixels to the panel in real time. |
| **RGB-TTL** | A parallel digital video interface: separate colour bit lines plus pixel clock and sync signals, driven at logic levels (3.3 V here). |
| **Active area** | The region of the panel that displays image data, as opposed to blanking intervals. |
| **Border** | Panel active area not occupied by the text grid, filled with a solid colour. |
| **Ring buffer** | A buffer addressed modulo its size, so that advancing a start pointer rotates the visible contents without moving data. |

---

## 3. Target Hardware

| Item | Value | Confidence |
|---|---|---|
| Panel | 10.1", 1024×600 | Confirmed by user |
| Panel interface | RGB-TTL, 40-pin, 3.3 V | **Assumed — must be verified** |
| Colour depth to panel | RGB666 (18-bit) | Decided (pin-limited) |
| FPGA-B device | iCE40 **HX8K**, TQ144 | Decided |
| FPGA-B local memory | Dedicated W9825G6KH SDRAM, 16-bit | Decided — **not used in Mode 0** |
| Reference clock | 12 MHz crystal | Existing |

> **Open item O-1.** If the selected panel is eDP rather than RGB-TTL, the ANX6345 bridge and its init sequence return, and §4 pin counts change. This specification assumes RGB-TTL.

---

## 4. Display Timing

### 4.1 Pixel clock

Target: 1344 × 635 total × 60 Hz = **51.20 MHz**.

Achievable from the 12 MHz reference using one iCE40 PLL in SIMPLE mode:

```
DIVR = 0, DIVF = 33, DIVQ = 3
Fout = 12 MHz × (33+1) / ((0+1) × 2^3) = 51.000 MHz
```

Resulting refresh rate: **59.76 Hz**. This is within the tolerance of every 1024×600 panel surveyed and requires no fractional synthesis.

The second PLL is reserved for the SDRAM clock (~100 MHz) used by graphics modes. **Both PLLs are then committed; no third clock domain is available.**

### 4.2 Timing parameters — PROVISIONAL

| | Active | Front porch | Sync | Back porch | Total |
|---|---|---|---|---|---|
| Horizontal (px) | 1024 | 24 | 136 | 160 | **1344** |
| Vertical (lines) | 600 | 3 | 6 | 26 | **635** |

Sync polarity: both negative (typical for this panel class).

> **Open item O-2.** These blanking values are a plausible set consistent with the 51.2 MHz target, **not** values taken from a datasheet. Panel vendors differ substantially. They must be replaced with the figures for the selected part before schematic capture. The pixel clock and the active geometry will not change; only the porches will.

### 4.3 Panel signals

`R[5:0]`, `G[5:0]`, `B[5:0]`, `PCLK`, `HSYNC`, `VSYNC`, `DE` — 22 pins, plus backlight enable and PWM.

---

## 5. Display Geometry

### 5.1 Grid

| Parameter | Value | Derivation |
|---|---|---|
| Cell size | **8 × 16 px** | 1024 / 8 = 128 exactly |
| Columns | **128** | |
| Rows | **32** | 32 × 16 = 512 lines |
| Total cells | **4096** | = 2^12, exactly addressable in 12 bits |
| Text area | 1024 × 512 px | |
| Vertical border | **44 lines top, 44 lines bottom** | (600 − 512) / 2 |
| Horizontal border | none | |

The 8×16 cell is deliberate. It is the standard VGA text cell, which means:

- Any existing 8×16 VGA font is usable without modification.
- Glyph row lookup is a 4-bit shift, not a multiply by 15.
- **Descenders are not truncated.** A 15-line cell would clip the lower row of `g j p q y`, forcing a bespoke font.

The 4096-cell total being an exact power of two is what makes the ring-buffer scroll of §8.2 free — the address wrap is a bit mask, not a comparator.

### 5.2 Vertical centring

Text rows occupy panel active lines 44 through 555 inclusive. Lines 0–43 and 556–599 display `BORDER_COLOR`.

---

## 6. Memory Model

### 6.1 Rationale — why EBR, not SDRAM

The text buffer and font are held entirely in FPGA-B block RAM. This is the central architectural decision of Mode 0 and it buys four things:

1. **CPU reads work with zero wait states.** EBR is genuinely dual-port: port A serves scanout, port B serves the CPU aperture. A 51 MHz fabric against an 8 MHz PHI2 means every CPU access — read *or* write — completes within its bus cycle. No write FIFO, no shadow copy in system SRAM, no `VRAM_WAIT` stall line back to FPGA-A.
2. **No SDRAM controller is required.** The console is available before the most defect-prone block in Neon has been written.
3. **No arbiter is required.** Scanout and CPU never contend.
4. **Glyph fetch latency is one cycle.** Font lookup is random access with no burst locality; in SDRAM it would pay a row-activate penalty (~60 ns) per fetch for no benefit.

### 6.2 Allocation

| Structure | Size | EBR blocks | Notes |
|---|---|---|---|
| Text buffer | 8192 B | 16 | 4096 cells × 2 B |
| Font | 4096 B | 8 | 256 glyphs × 16 B |
| Palette | 288 bits | 0 | Flip-flops, not EBR |
| Line buffer | — | 0 | **Not required** (see §7) |
| **Mode 0 total** | **12 KB** | **24** | of 32 available (HX8K) |
| **Free for graphics** | **4 KB** | **8** | |

> **Open item O-3.** EBR is allocated at synthesis time, not switched per mode. The 8 KB text buffer is dead weight while a graphics mode is running, and 4 KB is a thin allowance for blitter and sprite line buffers. Two escape valves exist: reduce the font to 128 glyphs (2 KB — full ASCII plus box-drawing), or multiplex the text buffer EBR into graphics-mode structures at the cost of address muxes. **Do not decide this now.** Make the glyph count a synthesis parameter and resolve it once the blitter has been synthesised and its real EBR demand is known.

### 6.3 Aperture map (bank `$FE`)

Mode 0 fits within a single 64 KB window. The `VRAM_PAGE` register defined for graphics modes is ignored in text mode.

| Range | Size | Contents | CPU access |
|---|---|---|---|
| `$FE:0000` – `$FE:1FFF` | 8 KB | Text buffer | R/W |
| `$FE:2000` – `$FE:2FFF` | 4 KB | Font | R/W |
| `$FE:3000` – `$FE:303F` | 64 B | Palette | R/W |
| `$FE:3040` – `$FE:FEFF` | — | Unmapped (reads return `$00`) | — |
| `$FE:FF00` – `$FE:FFFF` | 256 B | Register file | see §9 |

Access to bank `$FE` remains subject to the MMU's `VRAM_SEL` protection in FPGA-A; this specification does not alter the protection model.

---

## 7. Character Generation

No line buffer is needed. Character generation is fully real-time.

Per cell, the pipeline requires one text-buffer read and one font read every 8 pixel clocks. At 51 MHz with single-cycle EBR, this is a factor of 8 of slack.

For panel active line `L` where 44 ≤ L ≤ 555:

```
text_row  = (L - 44) >> 4
glyph_row = (L - 44) & 15

cell_index = (TEXT_START + text_row * 128 + column) & 0x0FFF
cell_addr  = cell_index << 1

code       = text_buffer[cell_addr]
attribute  = text_buffer[cell_addr + 1]

glyph_bits = font[(code << 4) | glyph_row]
```

Each of the 8 bits of `glyph_bits` selects between the foreground and background palette entries, MSB first (leftmost pixel).

The pipeline is 3 stages deep (cell fetch → font fetch → shift/palette). Horizontal timing must therefore begin cell fetch 3 clocks before the first active pixel; this is absorbed in the back porch.

For lines outside the text area, and for the horizontal blanking intervals, the output is `BORDER_COLOR`.

---

## 8. Text Buffer

### 8.1 Cell format

Two bytes per cell, little-endian, naturally aligned:

```
Byte 0 (even):  code[7:0]        — glyph index into font
Byte 1 (odd):   bg[3:0] fg[3:0]  — bits 7..4 background, bits 3..0 foreground
```

Both are palette indices into the 16-entry palette.

A 65816 in 16-bit accumulator mode (`M=0`) writes a complete cell with a single `STA` instruction. Note that this is **one instruction but two bus cycles** — the 65816 data bus is 8 bits wide. The saving is in instruction overhead, not bus traffic.

Full-screen fill: 4096 cells = 8192 bytes ≈ **5 ms** at 8 MHz with an unrolled 16-bit store loop.

> **Deferred.** There is no per-character blink attribute. The classic VGA approach reallocates attribute bit 7, which would cut the background palette to 8 entries. Retaining full 16/16 colour is judged more valuable. If blink is wanted later it should be added as a global mode bit that reinterprets bit 7, not as a silent change to the format.

### 8.2 Scrolling — `TEXT_START`

The text buffer is addressed as a ring of 4096 cells. `TEXT_START` is the cell index displayed at the top-left corner.

To scroll up one line, add 128 to `TEXT_START` (modulo 4096) and clear the 128 cells of the newly exposed bottom row.

| | Bytes moved | Time @ 8 MHz |
|---|---|---|
| Naive block move | 8192 | ~5 ms |
| `TEXT_START` + clear one row | 256 | **~160 µs** |

A factor of 32. For a terminal-style console this is the difference between scrolling being a visible cost and being free.

Because the ring wraps at exactly 4096 cells, no wrap-around special case exists in software — the hardware masks the index.

---

## 9. Register File

Base `$FE:FF00`. All registers are byte-wide. Reserved bits read as zero and must be written as zero.

| Offset | Name | Access | Description |
|---|---|---|---|
| `$00` | `NEON_ID` | R | Magic value `$4E` (`'N'`) |
| `$01` | `NEON_VER` | R | Gateware version, BCD |
| `$02` | `NEON_MODE` | R/W | `0` = text. Other values reserved. |
| `$03` | `TEXT_CTRL` | R/W | b0 `DISPLAY_EN` (0 = border colour over whole screen) |
| `$04` | `TEXT_START_L` | R/W | Cell index bits [7:0] |
| `$05` | `TEXT_START_H` | R/W | Cell index bits [11:8] |
| `$06` | `CURSOR_POS_L` | R/W | Cell index bits [7:0] |
| `$07` | `CURSOR_POS_H` | R/W | Cell index bits [11:8] |
| `$08` | `CURSOR_CTRL` | R/W | see §10 |
| `$09` | `BORDER_COLOR` | R/W | b3:0 palette index |
| `$0A` | `STATUS` | R | b0 `VBLANK`, b1 `HBLANK` |
| `$0B` | `RASTER_L` | R | Current panel line [7:0] |
| `$0C` | `RASTER_H` | R | Current panel line [9:8] |
| `$0D` | `RASTER_CMP_L` | R/W | Compare line [7:0] |
| `$0E` | `RASTER_CMP_H` | R/W | Compare line [9:8] |
| `$0F` | `IRQ_EN` | R/W | b0 vblank, b1 raster compare |
| `$10` | `IRQ_STATUS` | R/W1C | Same bit assignment; write 1 to clear |

`TEXT_START` and `CURSOR_POS` are latched on write to the high byte, so the low/high pair is applied atomically. **Software must write low then high.**

---

## 10. Hardware Cursor

`CURSOR_CTRL` (`$FE:FF08`):

| Bits | Field | Values |
|---|---|---|
| 1:0 | `SHAPE` | 0 = full block, 1 = underline (rows 14–15), 2 = half block (rows 8–15), 3 = vertical bar (column 0) |
| 3:2 | `BLINK` | 0 = steady, 1 = 1 Hz, 2 = 2 Hz, 3 = reserved |
| 4 | `ENABLE` | 1 = visible |

The cursor is rendered by **swapping foreground and background palette indices** for the affected pixels of the cell at `CURSOR_POS`. It consumes no text buffer storage and requires no save/restore of the underlying cell by software — a persistent source of complexity in software-drawn consoles.

Blink is derived from the vertical sync counter.

`CURSOR_POS` is a **buffer-absolute** cell index, not a screen-relative one. It therefore scrolls with the text when `TEXT_START` advances, which is the correct behaviour for the cell the cursor is attached to. A terminal that wants the cursor to remain on the last visible row must update `CURSOR_POS` when it scrolls — one register write.

Estimated cost: ~60 LUT.

---

## 11. Palette

16 entries, 18-bit RGB666, held in flip-flops (288 FF).

Four bytes per entry at `$FE:3000 + (index × 4)`:

| Byte | Contents |
|---|---|
| 0 | `R[5:0]` in bits 5:0 |
| 1 | `G[5:0]` in bits 5:0 |
| 2 | `B[5:0]` in bits 5:0 |
| 3 | Reserved, write zero |

The four-byte stride wastes 16 bytes but makes the address arithmetic a shift. The full 18-bit value reaches the panel unmodified — 262,144 selectable colours per entry.

**Default palette** is initialised in the bitstream to the standard 16-colour CGA/EGA set, so the display is usable at reset with no software involvement.

---

## 12. Font

### 12.1 Format

256 glyphs × 16 bytes = 4096 bytes. Byte `n` of a glyph is the pixel row `n`, MSB = leftmost pixel, `1` = foreground.

Address of glyph row: `(code << 4) | row`.

### 12.2 Two-tier residency

**Default font — initialised in the bitstream.** The system can print from the instant FPGA-B configuration completes, before the RP2040 has mounted the microSD card, before the kernel exists, and before the 65816 has been released from reset. This is not a convenience; it is the only way to get boot and bring-up diagnostics onto the screen.

**Replaceable at runtime.** The kernel may overwrite any part of `$FE:2000`–`$FE:2FFF` from a font file on the microSD card. Writes go to EBR port B while scanout reads port A.

> Writing the font outside of vertical blanking may produce a single-frame artefact on the glyph row being fetched at that instant. This is harmless, but a kernel loading a full font should do so during vblank (`STATUS.VBLANK`) or accept one frame of tearing.

### 12.3 Bitstream initialisation of the text buffer

The text buffer EBR is likewise initialised at synthesis: every cell set to code `$20` (space) with attribute `$0F` (light grey on black). The screen is therefore blank and correctly coloured at power-on rather than displaying random EBR contents.

---

## 13. Resource Estimate

Provisional, pending synthesis. iCE40 HX8K provides 7680 LUT and 32 EBR.

| Block | LUT (est.) |
|---|---|
| Timing generator | 120 |
| Character generator pipeline | 200 |
| Hardware cursor | 60 |
| Palette and output stage | 150 |
| Aperture / CPU bus interface | 250 |
| Register file, IRQ logic | 120 |
| **Mode 0 total** | **~900** |

Roughly 12% of the device. The remainder is available for the SDRAM controller, blitter, sprites, and audio — the blocks whose combined estimate (~7300 LUT) was previously identified as the binding constraint on Neon. **LUT, not bandwidth, remains the limiting resource for Neon as a whole**, but Mode 0 is not where the pressure is.

---

## 14. CPU Interface Summary

| Property | Value |
|---|---|
| Location | Bank `$FE`, 64 KB aperture |
| Read access | **Supported, zero wait states** |
| Write access | Supported, zero wait states |
| Wait-state mechanism | None required |
| Inter-FPGA signalling | None required |
| Bank capture | Latched from D[7:0] during PHI2 low |

The bank byte is captured by FPGA-B from the CPU data bus during the low phase of PHI2, as the 65816 emits it there. This avoids eight dedicated bank lines and is what keeps the FPGA-B pin count inside the TQ144 budget.

> **Open item O-4.** An interrupt line from FPGA-B to the 65816 `IRQB` is required for the vblank and raster-compare interrupts of §9. This was not included in the earlier FPGA-B pin budget (~99 of ~107 usable I/O). It adds one pin. Confirm whether this line goes directly to the CPU or is routed through FPGA-A for masking; the latter reintroduces an inter-FPGA signal, which the architecture has otherwise eliminated.

---

## 15. Verification Criteria (stage N0)

Mode 0 is accepted when all of the following hold:

1. Panel syncs and displays a stable image at 59.76 Hz with no visible tearing or jitter.
2. At power-on, before any CPU activity, the screen shows a blank field in the default background colour with correct borders.
3. RP2040 (or a test harness) writing to the aperture produces correct glyphs at correct positions.
4. Reading back the text buffer through the aperture returns exactly what was written.
5. Advancing `TEXT_START` by 128 scrolls the display by exactly one row with no artefacts.
6. The hardware cursor appears at `CURSOR_POS`, in the selected shape, blinking at the selected rate.
7. A font written through the aperture takes effect on the following frame.
8. `RASTER_L/H` read back plausible values that track the display; the vblank interrupt fires once per frame.

Criteria 1–2 are achievable **before the 65816 is populated**, using the RP2040 alone. This is the intended E0 bring-up path.

---

## 16. Open Items

| ID | Item | Blocks |
|---|---|---|
| **O-1** | Confirm panel is RGB-TTL, not eDP. Obtain part number. | Schematic capture |
| **O-2** | Replace provisional blanking values with datasheet figures. | Schematic capture |
| **O-3** | Font glyph count (256 vs 128) and EBR reuse across modes. | Blitter design |
| **O-4** | IRQ line routing: FPGA-B → CPU direct, or via FPGA-A. | Pin assignment |
| **O-5** | Backlight PWM: driven by FPGA-B or RP2040? | Power design |
| **O-6** | Reset and configuration order — FPGA-B must be configured and displaying before the 65816 leaves reset. | RP2040 firmware |

---

## 17. Decisions Superseded by This Document

Recorded so that earlier notes are not applied by mistake.

| Superseded | Replaced by |
|---|---|
| APS6404L PSRAM as Neon local memory | Dedicated W9825G6KH SDRAM (and Mode 0 uses neither) |
| ANX6345 eDP bridge, ≥14" panel | 10.1" 1024×600, RGB-TTL direct drive (pending O-1) |
| 128×40 grid, 8×15 cell | 128×32 grid, 8×16 cell |
| Text buffer of 10 KB in video memory | 8 KB in EBR |
| "A 16-bit cell write is a single bus access" | One instruction, **two** bus cycles |
| Framebuffer larger than 64 KB in one aperture window | `VRAM_PAGE` register (graphics modes only) |

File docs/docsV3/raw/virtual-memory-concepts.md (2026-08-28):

# Virtual Memory Concepts — DANI-65816

Conceptual reference document. Explains how a paged virtual memory system works
at a low level and fixes the vocabulary used throughout the rest of the project
documentation.

REV A

---

## 1. The problem it solves

Without virtual memory, every program sees real physical addresses. That creates
three problems:

1. **Relocation** — the program has to know what address it will be loaded at, or
   always be loaded at the same one.
2. **Protection** — any program can read or write another process's memory, or
   the kernel's.
3. **Fragmentation** — free memory breaks into holes and nothing fits any more
   even when the total free space would be enough.

Virtual memory solves all three by introducing **a translation layer between the
address the CPU generates and the address that reaches the memory chips**. The
process lives in a fiction: it believes it has the full 16 MB to itself, starting
at zero.

---

## 2. The core idea: paging

The address space is cut into fixed-size chunks. The chunks on the virtual side
are called **pages**; those on the physical side, **frames**. Both are the same
size — in DANI-65816, **2 KB**.

Translation amounts to answering a single question:

> which physical frame holds virtual page N?

The displacement within the page is never translated: the low bits pass through
unchanged from the virtual address to the physical one. This is why the virtual
address is read as two fields, which have standard names: the high field is the
**VPN** (Virtual Page Number) and the low one the **offset**.

```
Virtual address — 24 bits (W65C816S limit)

   23                       11 10                    0
  +---------------------------+-----------------------+
  |        VPN (13 bits)      |    offset (11 bits)   |
  +---------------------------+-----------------------+
      which page                   which byte inside
```

With 13 bits of VPN there are **8,192 pages per process**. Each one needs an entry
stating which frame it maps to and with what permissions: the **page table**.

Each entry in that table is called a **PTE** (Page Table Entry). It is a word —
32 bits in this design — holding the number of the frame where the page lives
plus a handful of status and permission bits. The table is nothing more than an
array of PTEs indexed by VPN.

```
8,192 entries x 4 bytes = 16 KB of table per process
```

---

## 3. The path of a translation

Translation is performed by the **MMU** (Memory Management Unit): the hardware
block that receives the virtual address and delivers the physical one. In many
architectures it is integrated into the CPU; in DANI-65816 no such block exists
inside the 65816, so FPGA-A implements it.

If every memory access required reading the PTE from the table first, every
access would cost twice as much. The universal solution is to cache recent
translations inside the MMU itself, in a small, very fast associative memory
called the **TLB** (Translation Lookaside Buffer). In DANI-65816 this is 32-64
entries held in **EBR** (Embedded Block RAM), the iCE40's internal RAM blocks.

```
              Virtual address
              VPN 13 b + offset 11 b
                      |
                      v
                 +---------+
                 |   TLB   |   looks up ASID + VPN
                 +---------+
                   /     \
                 hit      miss
                  |         |
        frame available   the walker reads
          immediately     the PTE in SRAM (~4 cycles)
                  \        /
                   \      /
                      v
              Physical address
              FRAME 16 b + offset 11 b
```

Two new terms appear in the diagram:

- **ASID** (Address Space IDentifier) — a tag marking which process each TLB entry
  belongs to. The lookup compares ASID and VPN together, so entries belonging to
  other processes can never produce a false hit. Without ASID the whole TLB would
  have to be flushed on every process switch.
- **Walker** (page-table walker) — the logic that goes to the table in memory and
  extracts the PTE when the TLB misses. In some architectures it is a kernel
  routine; in DANI-65816 it is hardware inside FPGA-A, which is why the cost is
  only ~4 cycles.

A TLB miss is **not an error**: it merely costs one table walk.

---

## 4. When translation genuinely fails

Besides the frame number, the PTE carries **flags**: individual bits describing
the state of the page and what may be done with it. The ones that matter here are
`P` (present — the page is in physical memory), `W` (write — it may be written),
`X` (execute — it may be executed) and `U` (user — accessible from user code and
not only from the kernel). The full list is in the glossary.

The walker reads the PTE, checks those bits, and can run into two anomalous
situations:

### 4.1 Bit P = 0 — page not present

The page is not in physical memory. Either it has never been touched, or it was
evicted to storage. The MMU aborts the access and notifies the kernel, which:

1. allocates a free frame,
2. brings in the contents if required,
3. writes the PTE,
4. retries the instruction.

This is the **page fault**, the basis of demand paging. In v1 loading is eager, so
this case is deferred.

### 4.2 Incorrect permissions

A write to a page with `W=0`, execution of a page with `X=0`, a user access to a
page with `U=0`. There is no retry here: it is a program error and the kernel
terminates it.

### 4.3 Mechanism on the 65816

Both cases use the **ABORTB** pin. FPGA-A detects the problem *during* the cycle
and aborts the instruction before it modifies any state, leaving the CPU in a
position to retry cleanly. The **VPA** pin distinguishes an instruction-fetch
cycle from a data cycle, and therefore allows the `X` flag to be checked.

Fault information is exposed to the kernel through FPGA-A registers:
`FAULT_ADDR`, `FAULT_CAUSE`, `CONTEXT`, `MODE`.

---

## 5. Why FRAME is 16 bits against VPN's 13

The two fields measure different things:

| Field | Measures | Set by |
|---|---|---|
| VPN | how much memory **one process** sees | the CPU |
| FRAME | how much memory **the machine** has | the MMU design |

There is no reason for them to match, and in DANI-65816 they deliberately do not.

### 5.1 The virtual side is capped by the CPU

The 65816 emits 24-bit addresses and that is that: 16 MB. It is a limit of the
silicon, not a design decision.

```
16 MB / 2 KB           = 8,192 pages -> 13 bits
24 bits - 11 of offset = 13 bits of VPN
```

The 13 bits are not selectable: they fall out of a subtraction.

### 5.2 The physical side is not

The physical address is not emitted by the 65816: it is assembled by FPGA-A after
translation. The FPGA drives the memory bus and can address whatever it likes.
The ceiling is set by the width of the FRAME field:

```
16 bits of FRAME x 2 KB = 65,536 frames = 128 MB
```

The machine can therefore hold 128 MB of RAM even though no process ever sees
more than 16 MB. **The MMU breaks the 65816's architectural barrier at system
level without breaking it at process level.**

The 3-bit difference means up to **8 complete virtual address spaces** can be
resident simultaneously in physical memory — exactly what preemptive multitasking
with resident processes requires.

### 5.3 Why 16 and not 15

The planned pool is 48 MB = 24,576 frames, which fits in 15 bits (15 bits reach
64 MB). The sixteenth bit is free:

```
32-bit PTE
+- FRAME[15:0]                    16 bits
+- P W X U D A NC PIN + SW[7:0]   16 bits
```

The flags occupy exactly 8 + 8 = 16 bits, so the other half-word was going
unused. Rounding FRAME up to 16 costs nothing and leaves the ceiling at 128 MB in
case the SDRAM is expanded.

The split into exact halves also simplifies the walker: FRAME is the low
half-word and the flags the high one. The FPGA reads 32 bits from SRAM, takes the
lower 16 for the address bus and the upper ones for the permission logic, in
parallel and with no extra shifting or masking cycles.

### 5.4 The relationship also works in reverse

The sum of all virtual address spaces across all processes can comfortably exceed
the 128 MB of physical memory. That is not a problem: it is the second purpose of
virtual memory. With demand paging, the pages that do not fit live on the SD
card.

---

## 6. Glossary

**Virtual memory** — a layer of indirection between the addresses the CPU
generates and those that reach the RAM.

**Virtual (or logical) address** — the address the CPU emits. What the program
"believes". 24 bits in DANI-65816.

**Physical address** — the address that reaches the SRAM/SDRAM chips. 27 bits in
DANI-65816.

**Page** — a fixed-size block of the virtual space. 2 KB.

**Frame** — a block of the same size in physical memory. To translate is to pair
a page with a frame.

**VPN** (Virtual Page Number) — high bits of the virtual address; identifies the
page. 13 bits.

**Offset** — low bits; the byte within the page. Never translated. 11 bits.

**MMU** (Memory Management Unit) — the hardware that translates. In DANI-65816 it
is not in the CPU: FPGA-A implements it.

**Page table** — an array indexed by VPN holding the PTEs. One per process, 16 KB.

**PTE** (Page Table Entry) — one entry of that table. 32 bits: frame number plus
flags.

**PTE flags** — `P` present in RAM, `W` writable, `X` executable, `U` accessible
from user mode, `D` dirty (modified since it was loaded), `A` accessed (used
recently), `NC` non-cacheable, `PIN` non-evictable, `SW` bits free for the
kernel's own use.

**TLB** (Translation Lookaside Buffer) — cache of VPN-to-frame translations inside
the MMU. Avoids re-reading the table on every access.

**TLB hit / miss** — success or failure in that cache. A miss costs one table
walk; it is not an error.

**Page walk / walker** — the traversal of the page table to resolve a miss. It can
be done by hardware (the DANI-65816 case, ~4 cycles) or by software through an
exception.

**ASID** (Address Space IDentifier) — tag identifying which process each TLB entry
belongs to. Without it the whole TLB would have to be flushed on every context
switch.

**Page fault** — exception raised on access to a page with `P=0`. Recoverable.

**Demand paging** — loading pages only when they are touched, rather than all of
them up front. Deferred to post-v1.

**Swapping** — evicting rarely used pages to storage in order to free frames.

**Pinning** — marking a page as non-evictable. Required for the kernel, the
interrupt vectors and the bank $00 stack.

**Context switch** — switching process; entails pointing the MMU at a different
page table.

**Memory protection** — preventing a process from reading or writing outside its
own space. Achieved through the PTE flags, not through translation itself.

**ABORTB** — W65C816S pin that cancels the instruction in progress without side
effects. The system's fault mechanism.

**VPA / VDA** — pins indicating whether the cycle is an instruction fetch or a
data access. They make checking the `X` flag possible.

**EBR** (Embedded Block RAM) — RAM blocks inside the iCE40. Not a virtual memory
concept: it appears here because its 128 Kbit are the reason only the TLB fits
inside the FPGA while the page table lives in external SRAM.

---

## 7. Summary of figures

| Parameter | Value |
|---|---|
| Page size | 2 KB |
| Virtual address | 24 bits (16 MB per process) |
| VPN | 13 bits (8,192 pages) |
| Offset | 11 bits |
| PTE | 32 bits |
| FRAME field | 16 bits |
| Physical address | 27 bits (128 MB ceiling) |
| Page table | 16 KB per process |
| Planned physical pool | 48 MB = 24,576 frames |
| TLB entries | 32-64, in FPGA-A EBR |
| Page walk cost | ~4 cycles (10 ns SRAM) |

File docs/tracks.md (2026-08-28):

---
layout: page
title: Tracks
permalink: /tracks/
redirect_from: /categories/
menu: main
---

The diary runs on two axes. A **track** says which part of the machine an entry
is about — one per entry, and they are meant to be few enough, and separate
enough, that filing an entry is never a judgement call. A
[series]({{ '/series/' | relative_url }}) says in what order a run of entries
is read. Most entries have a track and no series.

<div class="idx" markdown="0">
  <div class="cap">BY TRACK</div>
  <table>
    {%- for t in site.data.tracks -%}
    {%- assign entries = site.categories[t.id] -%}
    <tr>
      <td class="de">{{ t.de }}</td>
      <td>
        <a href="{{ '/tracks/' | append: t.id | append: '/' | relative_url }}">{{ t.name }}</a>
        <div class="ex">{{ t.blurb }}</div>
      </td>
      <td class="fg">{{ entries | size }}</td>
    </tr>
    {%- endfor -%}
  </table>
</div>

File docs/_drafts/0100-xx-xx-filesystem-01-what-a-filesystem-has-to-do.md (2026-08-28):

---
categories: storage
tags: [filesystem]
series: filesystem
part: 1
---

## What a filesystem has to do

Notes to self on the shape of a post in a series:

- `categories:` is the track — one, always. Here, storage.
- `series:` and `part:` are what put it in reading order. Parts are ordered by
  `part`, not by date, so a part can be slotted in between two published ones
  later. Gaps are fine, duplicates are not.
- `tags:` is the fine-grained axis — fat32, allocator, sd — and is free-form.

Delete all of the above before publishing.

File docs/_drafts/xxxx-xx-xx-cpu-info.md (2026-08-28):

---
categories: cpu
---

http://forum.6502.org/viewtopic.php?f=4&t=3404

http://sbc.bcstechnology.net/65c816interrupts.html#toc:interrupt_abort

http://sbc.bcstechnology.net/page007.html

http://forum.6502.org/viewtopic.php?f=4&t=3404&start=15#p40104

http://sbc.bcstechnology.net/

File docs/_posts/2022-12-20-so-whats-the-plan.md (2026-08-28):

---
categories: general
redirect_from: /general/2022/12/20/so-whats-the-plan.html
---

## So.. what's the plan?

Awesome, another very legit question! So far, there's none, I'm afraid. I'm only gathering some random thoughts for now. The **feature creep madness** phase seems to be wearing off, as I've barely added anything new to the requirements for a few days.

I'm very much aware of the need for a plan. A complex project like this is bound to fail without one. So, let's draft one!

The first step is to call the **feature creep madness** complete. That's something I'm ready to do right now. Sure, some small new features will pop up at some point, but I'm very much satisfied with my current list.

Except for one **small** thing. As DRAM may not be fast enough to respond to the CPU within a single cycle, I will implement some sort of cache. A smaller SRAM IC, handled again by the MMU, will accomplish this. 

There's a whole new set of skills I need to learn. 

- 65816
- Verilog / VHDL
- DRAM
- Memory Cache
- Video generation
- Screen Controller
- Audio generation
- SD card / Filesystem management
- USB (Storage and HID)
- RTC
- Battery Management

Not bad! In parallel, as I progress with the above list, work on a first prototype will proceed as follows:

- Core block diagram. Extend [these random thoughts](/nova64/architecture/2022/12/16/some-random-thoughts.html) into a proper block diagram for the system core
- Prototype schematic. Will have to include CPU, FPGA, SRAM and DRAM footprints. Video will also have a place. SPI bus from the MMU should be exposed, to use it in the peripherals phase
- Preliminary boot sequence (No SD support yet)
- First run. FPGA will forward all writes to SRAM. DRAM doesn't even need to be present
- Test memory accesses, clock stretching and bus disconnect 
- Add DRAM. No cache, all writes go to DRAM
- Implement cache
- Add video by mirroring upper memory bank
- Implement video DMA

Then, time to work on the peripherals. It's very likely all of them can use a SPI bus, of which the MMU should be the master. 

- Simple serial
- Keyboard support
- Mouse support
- SD and filesystem
- USB Storage
- RTC
- Network
- Battery

OS development will be done in parallel with all the above. As I move on, more and more features will be made available. However, by the time the hardware is complete, I will need to fully focus on the software. This is still too far into the future, so I won't think too much about it. I will probably start with a simple, text-only console, running some kind of BASIC. A fully graphical OS is right now beyond my knowledge. We'll talk about it in a few years.

It seems I now have a plan.

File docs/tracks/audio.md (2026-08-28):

---
layout: track
track: audio
title: "Track · Audio"
permalink: /tracks/audio/
redirect_from: /categories/audio
---

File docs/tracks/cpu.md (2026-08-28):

---
layout: track
track: cpu
title: "Track · CPU"
permalink: /tracks/cpu/
redirect_from: /categories/cpu
---

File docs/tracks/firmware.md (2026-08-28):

---
layout: track
track: firmware
title: "Track · Firmware"
permalink: /tracks/firmware/
redirect_from: /categories/firmware
---

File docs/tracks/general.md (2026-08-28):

---
layout: track
track: general
title: "Track · General"
permalink: /tracks/general/
redirect_from: /categories/general
---

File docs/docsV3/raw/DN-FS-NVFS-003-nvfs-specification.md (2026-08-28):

# DN-FS-NVFS-003 — NVFS On-Disk Format and Behaviour Specification

**Project:** noVa64 (DANI-65816)
**Document:** Specification, Draft 3
**Status:** For review — **not frozen**
**Supersedes:** NVFS specification draft 2 (format-incompatible — see §0.2 and §25)
**Scope:** Complete on-disk format, mount/unmount procedure, crash-consistency
model, and normative behaviour of the noVa64 native file system.

---

## 0. Reader's guide

### 0.1 What this document is

This is a from-scratch redesign of NVFS. It is written to be implementable
twice — once as a host-side C99 reference library (`libnvfs`) and once as a
65816 kernel driver under Calypsi — from this document alone, with no reference
to draft 2 and no reference to any existing implementation.

Everything in §3–§19 is normative. §20–§24 are informative but binding as
acceptance criteria. §25–§26 are project management, not format.

### 0.2 THIS IS A FORMAT BREAK — read before implementing

Draft 3 is **not** compatible with draft 2, in either direction. There is no
migration path in the file system itself. The following existing assets are
affected:

| Asset | Impact |
|---|---|
| NVFS specification draft 2 | Superseded, retained only as history |
| `libnvfs` (C99 reference) | Structure layer rewritten; API surface largely survivable (§21.6) |
| `mkfs.nvfs` | Rewritten — layout is different |
| `nvfsck` | Rewritten — invariants are different, journal recovery is new |
| `nv` CLI | Front-end mostly survives; anything format-aware moves to `libnvfs` |
| 65816 read-path driver | Rewritten — extents replace whatever draft 2 used |
| 65816 assembly CRC-32 | **Reusable unchanged** (§Appendix A pins the same polynomial) |
| Conformance suite (2,350 checks) | Test *harness* reusable; expected values and many checks are format-specific and must be regenerated |
| Crash-injection harness | **Reusable and more valuable than before** — it now has a journal to attack |
| Cross-implementation agreement harness (488 checks) | Harness reusable; corpus regenerated |

Existing draft 2 volumes must be evacuated by copying files out with the old
tooling before reformatting. Draft 3 refuses to mount a draft 2 volume: the
superblock is at a different block, and the magic/version check fails cleanly.

**This cost is real and it is the main argument against draft 3.** The main
argument *for* draft 3 is §0.3.

### 0.3 What draft 3 changes, and why

Five decisions differ from draft 2. Each is justified in the section named.

1. **A metadata journal replaces write-ordering discipline.** (§13, §14)
   Draft 2 obtained crash consistency purely from write ordering, which is why
   the crash-injection harness found ordering bugs. Ordering rules are a
   correctness argument spread across every mutating operation; a journal is a
   correctness argument in one place. On a machine with no on-target `fsck`,
   bounded, idempotent, single-pass recovery is worth its cost.

2. **Fixed 2048-byte block size, equal to the MMU page size.** (§4)
   A file system block is exactly one virtual-memory page and exactly four SD
   sectors. Demand paging an executable becomes one block read. Every
   block-number-to-index conversion in the driver becomes a shift, which matters
   on a CPU with no divide and a 16-bit ALU.

3. **Extents replace indirect block trees.** (§10)
   At roughly 2–2.5 ms per block transfer at 8 MHz, an indirect block read is a
   visible cost. Extents remove it for the common case of a file laid down in
   one or a few runs.

4. **Fixed-size 64-byte directory slots replace variable-length records.** (§11)
   Variable-length records with an in-band length field are the single largest
   source of directory corruption bugs in ext2-class file systems. Fixed slots
   make insert and delete trivially reversible and trivially checkable.

5. **`i_mode` and `de_type` are bit-identical to POSIX.** (§9.2, §11.3)
   The FUSE binding and the eventual noVa64 VFS pass these through with no
   conversion table.

### 0.4 Relationship to other project documents

- **DN-FS-VFS-001** (not yet written) will define the `fsops` vtable shared by
  NVFS and ext2. §21.6 of this document proposes a provisional surface; it is
  expected to change and this specification does not depend on it.
- **DN-FS-EXT2-001** defines the ext2 interoperability layer. NVFS remains the
  native read/write file system; ext2 remains a transfer medium.
- The Helium SD block register map is **not yet frozen**. §20.4 states what this
  specification needs from it. This is on the critical path.

---

## 1. Purpose and design goals

NVFS is the native file system of noVa64. It is the volume the machine boots
from, stores its kernel and applications on, and pages from. It is designed for
one specific machine and makes no attempt at generality.

**Goals, in priority order:**

1. **Recoverable without human intervention.** After any power loss, mount must
   either succeed with a consistent volume or fail with a specific reason. It
   must never succeed with a silently corrupt volume.
2. **Implementable on a 65816.** Every hot-path index computation must be a
   shift or a mask. Steady-state RAM must fit in single-digit kilobytes.
3. **Cheap in block transfers.** Transfers dominate cost; algorithmic elegance
   that costs an extra block read is a bad trade.
4. **Verifiable.** Every metadata block carries a checksum, or is protected by
   one that does. Every structural invariant must be checkable by a host-side
   `nvfsck` in a single pass over the volume.
5. **Faithful to POSIX where it is free.** Match POSIX encodings when matching
   costs nothing, so that the FUSE binding and the VFS are thin.

**Explicit non-goals:** compression, encryption, snapshots, quotas, extended
attributes, access control lists, multi-device volumes, online resize, block
sizes other than 2048, big-endian hosts.

---

## 2. Scope

### 2.1 In scope

- The complete on-disk byte layout of an NVFS volume.
- Mount, unmount, and journal recovery procedures.
- The crash-consistency model and its normative ordering rules.
- Semantics of every file and directory operation.
- Feature-flag mechanism and acceptance policy.
- Conformance obligations for any implementation.
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

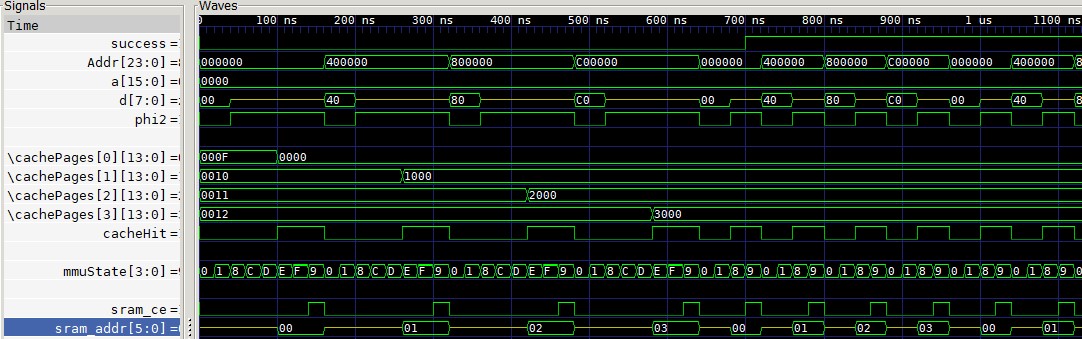
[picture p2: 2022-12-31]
docs/img/cacheMMU.jpg

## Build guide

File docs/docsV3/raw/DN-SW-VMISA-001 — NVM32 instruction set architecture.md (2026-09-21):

# DN-SW-VMISA-001 — NVM32 instruction set architecture

*noVa64 · Rev B (draft for discussion)* · 2026-09-20 · @Someone

## Revision history

| Rev | Date | Change |
| --- | --- | --- |
| A | 2026-09-17 | Initial draft. 16 registers, 16-bit code units, flagless compare-and-branch, 32-bit-clean pointers, RISC-V division conventions. |
| B | 2026-09-20 | Three corrections to Rev A (below). VM work deferred with a written reopening condition. Encoding candidates added as open, measurement-gated items. ISA freeze moved from "now" to toolchain gate T4. |
| B.1 | 2026-09-21 | "Settle now" list extended with the three noVa128 portability requirements and the emulator's `WDM` rule. |

**Corrections to Rev A**, recorded as errors rather than open questions:

1. **The PIC strategy in Rev A §1.7 was wrong.** It relied on a global pointer the ABI table never reserves, and a 16-bit PC-relative displacement cannot reach the data region from the text region in this memory map. Corrected in "Executable format": executables are linked at fixed addresses and never relocated.
2. **QBE was wrongly described as a strong second choice for the compiler.** It targets 64-bit architectures only. Corrected in DN-SW-VMCC-001; the second choice is LLVM or lcc.
3. **The freeze order was wrong.** Rev A said "ratify the ISA now". The ISA freezes at gate T4, once the compiler produces real code and the reference interpreter has produced an opcode histogram. Freezing before the first backend existed is how the change requests in DN-SW-VMCC-001 appendix A would have become permanent.

*Review cycle: reviewers, dates and decisions to be recorded here before this note leaves draft status.*

## Status and scope

**Status: deferred.** noVa64 continues with the original plan — native 65816 code compiled by Calypsi. NVM32 becomes the application development model once the OS and a minimal kernel exist; Calypsi stays the kernel compiler.

Rationale for deferring: the dependency runs one way. The VM needs a process model, page tables, a loader, a scheduler and a service table from the kernel; the kernel needs nothing from the VM. Building the VM first means guessing interfaces that do not exist yet. The headline argument for NVM32 — one binary on interpreter and softcore — also depends on FPGA-C, which is itself deferred.

**Reopening condition: the kernel executes its first user process, with page faults and syscalls working.** At that point Stage 1 (the C11 reference interpreter inside DN-SW-EMU-001) begins; it is PC-side software and competes for no hardware time.

Seven things must be settled before then, because they cost nothing now and are expensive later. The last three come from DN-HW-ARGON-001: they are what keeps the noVa64 kernel binary-compatible with noVa128.

| Decision | Owner | Why now |
| --- | --- | --- |
| Kernel services reached through a numbered service table, not `COP` signatures scattered through the code | Kernel | The VM must never call native code directly; this is also better hygiene for the kernel itself |
| Banks `$00`–`$01` reserved in the process memory map from the first loader, plus one shared read-only page for the system information block | Kernel / loader | Reclaiming that region later is a migration |
| Memory-mapped registers idempotent on read (NEON, Helium) | NEON, Helium | Required by Argon's 65816 modes; discovering it late means redesigning the command port |
| The PC emulator can host a reference interpreter, and treats `WDM` as a two-byte no-op | DN-SW-EMU-001 | Nothing to write yet; the `WDM` rule keeps the CPU probe honest |
| No cycle counting for time; the fixed frequency reference is the only clock | Kernel, drivers | Already implied by PHI2 stretching; stating it makes it binding |
| No self-modifying code in project code | Kernel, BIOS | Avoids depending on Argon's instruction-cache snooping |
| Software-visible Helium and NEON register map kept stable, versioned through the system information block if it ever changes | Helium, NEON, BIOS | The 16-bit inter-FPGA path of noVa128 must not leak into the programmer's model |

Accepted risk: the kernel ABI will be shaped around Calypsi's 16-bit `int`. The marshalling layer specified here exists for exactly that reason.

This note specifies the ISA. The interpreter is DN-SW-VMINTERP-001, the coprocessor DN-HW-VMCORE-001, the toolchain DN-SW-VMCC-001, the measurement harness DN-SW-VMBENCH-001, and the noVa128 tri-mode core DN-HW-ARGON-001.

## Programmer's model

- **16 general-purpose 32-bit registers, R0–R15.** Eight is too few for a C ABI without spills, which are expensive in the interpreter. Sixteen fits a 4-bit nibble field and costs 64 bytes of direct page in the interpreter and a small EBR register file in hardware. Thirty-two would need 5-bit fields, which breaks clean nibble decode — the single most load-bearing constraint in this encoding.
- **No hardwired zero register.** It aids RISC hardware but wastes a register in the interpreter and complicates the 16-registers-in-64-DP-bytes mapping. `MOVIZ rd,#0` covers it.
- **Register roles are ABI conventions, not hardware.** R13 = SP, R14 = LR, R15 = FP, R0–R3 = arguments and returns. Both implementations treat all 16 uniformly.
- **PC: 24-bit, byte-addressed, instructions 16-bit aligned.** Always points into the 24-bit guest virtual space.
- **Flagless.** Comparisons fold into branches (`Bcc rs,rt,disp`) or `SETcc rd,rs,rt`. There is no architectural status word. A flags register would force the interpreter to compute and store N/Z/V/C after every ALU operation — dead work most of the time — and would force flag-forwarding hazards on the core.
- **Architectural state is {R0–R15, PC} and nothing else.** A single non-architectural trap-cause latch exists, used only when halted for a fault or syscall.

That last line is the invariant the whole design rests on. It is what makes a process migratable mid-execution between interpreter and softcore, and what makes preemption cheap. Any proposal that adds architectural state — a flags register, a window pointer, an implicit accumulator — is paying against it and must say so explicitly (see "Encoding candidates pending measurement").

## Memory model

**Little-endian**, matching the 65816.

**Pointers are 32-bit values; only the low 24 bits are address, and bits \[31:24\] must be zero.** Any load, store or branch whose effective pointer has non-zero high bits raises `ADDR_FAULT`, enforced identically on both implementations.

This is the 68000 lesson applied deliberately. Classic Mac OS and AmigaOS stored flags in the high byte of pointers because the hardware ignored it; the resulting "32-bit dirty" software broke when full 32-bit addressing arrived. ARM's Top-Byte-Ignore shows tagging can be clean when defined from day one, so TBI-style semantics stay reserved behind a feature bit — but the default is check and trap.

**Guest memory map** (per-process 24-bit virtual space):

| Range | Size | Use |
| --- | --- | --- |
| `$00_0000`–`$00_FFFF` | 64 KB | Reserved host region: 65816 direct pages, 65816 stack, interpreter scratch, VM state window, trap mailbox. Guest may not touch it |
| `$01_0000`–`$01_FFFF` | 64 KB | Interpreter code and dispatch table, read-only, shared, mapped identically in every process |
| `$02_0000`–`$0F_FFFF` | \~896 KB | Guest code, read-execute |
| `$10_0000`–`$EF_FFFF` | \~14 MB | Guest data, BSS and heap, read-write |
| `$F0_0000`–`$FF_FFFF` | 1 MB | Guest stack, growing down from `$FF_FFFF`, guard page at the bottom |

The loader refuses to map guest segments over banks `$00`–`$01`, and the MMU marks them no-access for guest pointers. On the softcore those banks are never generated as guest effective addresses; the region stays reserved only so one binary's memory map is valid on both executors.

**Alignment:** 16- and 32-bit accesses require natural alignment; misalignment raises `ADDR_FAULT`. Unaligned access costs extra cycles and bank-carry handling on the 65816 and forces byte assembly in hardware.

**Faults:** unmapped page → `PAGE_FAULT`; permission or copy-on-write → `PROT_FAULT`. Both restartable, per the commit rules in DN-SW-VMINTERP-001.

## Instruction encoding

Every instruction is one, two or three 16-bit little-endian code units. **The opcode byte alone determines length**, via a 256-entry table in the interpreter or a small combinational map in hardware.

This is the Dalvik pattern, chosen because it suits both targets. On the 65816 a single 16-bit fetch yields an 8-bit opcode plus two 4-bit register fields — exactly what the dispatcher needs. In hardware the first byte gives length and format with no multi-way logic.

| Format | Layout (unit0 \[unit1\] \[unit2\]) | Example |
| --- | --- | --- |
| F1 | `op:8 \| 00:8` | `HALT`, `RET`, `NOP`, `YIELD` |
| F2 | `op:8 \| rd:4 rs:4` | two-address `ADD rd,rs`, `MOV`, `NEG` |
| F3 | `op:8 \| rd:4 rs:4` + `rt:4 z:4 :8` | three-address `ADD rd,rs,rt` |
| F4 | `op:8 \| rd:4 z:4` + `imm:16` | `MOVIZ`/`MOVIS rd,#imm16` |
| F5 | `op:8 \| rd:4 z:4` + `imm:32` | `MOVI32 rd,#imm32` |
| F6 | `op:8 \| rd:4 rs:4` + `disp:16` | load/store `[rs+disp]`, PC-relative |
| F7 | `op:8 \| rs:4 rt:4` + `disp:16` | compare-and-branch `Bcc rs,rt,disp` |

Three rules exist for the 65816 and must not be relaxed:

1. Register fields are always the two nibbles of unit0's second byte, so one load plus a mask extracts them, pre-doubled to index 4-byte DP slots.
2. Immediates and displacements are always whole 16- or 32-bit little-endian words at a unit boundary — never bitfields spanning bytes. This is why RV32I was rejected as the native format.
3. Sign extension is decided by opcode (`MOVIZ` zero-extends, `MOVIS` sign-extends), never by a mode bit, so both implementations stay branch-free on extension.

**Opcode map**, 8-bit primary opcode:

| Range | Class |
| --- | --- |
| `$00–$0F` | System and flow: NOP, HALT, YIELD, BKPT, SYSCALL, RET, CALL, CALLR, JMP, JMPR |
| `$10–$2F` | ALU register-register, two- and three-address: ADD, SUB, AND, OR, XOR, NOT, NEG, MUL, MULH, MULHU, DIV, DIVU, REM, REMU |
| `$30–$3F` | Shifts and rotates: SHL, SHR, SAR, ROL, ROR, register and immediate count |
| `$40–$5F` | ALU register-immediate: ADDI, SUBI, ANDI, ORI, XORI, MOVIZ, MOVIS, MOVI32 |
| `$60–$7F` | Loads and stores: LDB, LDBU, LDH, LDHU, LDW, STB, STH, STW, base+disp16 |
| `$80–$9F` | Compare-and-branch: BEQ, BNE, BLT, BLTU, BGE, BGEU, BRA, SETcc |
| `$A0–$AF` | Stack and frame fast paths: PUSH, POP, FP-relative load/store, ENTER, LEAVE |
| `$B0–$BF` | Block operations: MEMCPY, MEMSET |
| `$C0–$EF` | Reserved for extensions, feature-bit gated |
| `$F0–$FE` | Reserved for the privileged extension (standalone mode) |
| `$FF` | Guaranteed illegal on both implementations — canary |

Reserved and illegal opcodes trap identically as `ILLEGAL_OP`.

## Operation semantics

These are the tables both implementations must match exactly. They follow eBPF and RISC-V where those are already precise and hardware-friendly, because the goal is boring semantics that a retargeted C compiler and a small FSM both like.

- **Arithmetic** wraps modulo 2³² in two's complement; no overflow trap. `ADD`, `SUB` and `MUL` are identical for signed and unsigned in the low word.
- **MULH / MULHU:** the high 32 bits of the signed or unsigned 64-bit product.
- **Shifts:** the shift amount is **masked to 5 bits** (`count & 31`) for every shift and rotate. This settles "shift count ≥ 32" identically on both sides. `SAR` is arithmetic, replicating the sign.
- **Loads:** `LDB` and `LDH` sign-extend; `LDBU` and `LDHU` zero-extend; `LDW` is full width.
- **Compares and branches:** signed (`BLT`, `BGE`) and unsigned (`BLTU`, `BGEU`) provided explicitly; no flags consulted.

**Division and remainder** are fully defined, with no trap — deliberately branchless and bit-identical:

| Case | DIV / DIVU | REM / REMU |
| --- | --- | --- |
| divisor = 0 | `0xFFFFFFFF` | dividend, unchanged |
| signed `INT_MIN / −1` | `INT_MIN` (`0x80000000`) | `0` |

These are the RISC-V conventions, chosen because they are what both an iterative divider FSM and the C reference implement most naturally. **This diverges from eBPF, which zeroes the destination on divide-by-zero.** The divergence is deliberate and must stay recorded here so no one "fixes" it later. Because division is defined, `DIV0` is reserved and unused in the trap causes.

**Block operations are restartable.** `MEMCPY` and `MEMSET` keep progress in registers (R0 = destination, R1 = source or value, R2 = remaining count), operate one element at a time from low to high, and decrement R2. Re-executing with the current register values resumes correctly. This is what makes both the ABORTB path and the softcore fault path precise.

**Trap causes:** `ILLEGAL_OP`, `ADDR_FAULT` (misalignment or non-zero pointer high byte), `PAGE_FAULT`, `PROT_FAULT`, `BKPT`, `SYSCALL`.

**Commit point.** An instruction commits register and PC writes only at its end: compute the effective address, perform the access, and only then write the destination register and advance the PC. On the 65816 this is nearly free because ABORTB already restarts the host instruction without modifying registers. On the softcore it is the real work — the FSM must not update the register file or PC until the memory stage succeeds.

## ABI

**C ABI, "ILP32-24":** `char` 1, `short` 2, `int` 4, `long` 4, `long long` 8, pointers 4 bytes stored with 24 bits effective, `maxalign` 4, `char` signed. Deliberately divergent from Calypsi's 16-bit `int`: the VM has 32-bit registers, so a 16-bit `int` would cause constant widen and narrow churn.

| Register | Role | Saver |
| --- | --- | --- |
| R0–R3 | Arguments and returns (R0:R1 for 64-bit) | Caller |
| R4–R7 | Temporaries | Caller |
| R8–R10 | Temporaries | Callee |
| R11–R12 | Code-generator temporaries, not allocatable | Caller |
| R13 | SP, full descending, 4-byte aligned | Callee |
| R14 | LR | Callee, via `ENTER` |
| R15 | FP | Callee |

R11 and R12 are reserved because NVM32 has no memory-to-memory operations, so the code generator needs scratch of its own (DN-SW-VMCC-001). Variadic arguments always go on the stack. Structs use natural alignment, members in declaration order, size rounded to 4.

**Stack frame:** `CALL` places the return address in LR; `ENTER n` pushes LR and the old FP and reserves n bytes; `LEAVE` and `RET` reverse it. Stack arguments are pushed right to left.

**Syscall ABI:** `SYSCALL` carries an 8-bit service number in unit0's low byte, with an optional 16-bit extended number in unit1. Arguments in R0–R5, result in R0 and R1, errors as a negative R0 in errno style — never a flag. `SYSCALL` halts the VM with cause `SYSCALL`, leaving the number and arguments visible in the state window.

**Marshalling onto the native kernel.** The handler (1) validates the service number against the table; (2) validates every pointer argument — high byte zero, inside the guest data or stack regions, correct permission, and not naming the reserved host region; no address translation is needed because the guest virtual space *is* the process virtual space; (3) converts 32-bit NVM32 arguments to the widths the Calypsi kernel entry expects, then issues `COP #sig`; (4) packs the result into R0 and R1 and resumes. This marshalling layer is the single place that knows both ABIs.

**Guest code never calls 65816 machine code directly.** Only this portable trap crosses the boundary, which is what lets the same binary run on the softcore. A controlled native extension mechanism is provided as **data**, not code: a per-process service table mapping small integers to kernel handlers. Because it is a number space resolved by the host, it is implementation-independent. Any "call native address" mechanism would be fatal on the softcore and is excluded.

## Executable format (NVX)

Header: magic `"NVX1"`, ISA major and minor, a **feature-bit vector** (bit 0 base, bit 1 MUL/DIV present, bit 2 block operations, bit 3 reserved for TBI-style tagging), 24-bit entry PC, section table for `.text`, `.rodata`, `.data` and `.bss`, requested stack size.

**Fixed-address linking, no PIC.** Every process owns its whole 24-bit space, so `.text` always starts at `$02_0000` and `.data` at `$10_0000`, the same in every process. Executables are linked there and never relocated at load. This replaces the PC-relative PIC strategy in Rev A, which was unworkable: a 16-bit displacement cannot reach the data region from the text region. Position independence is deferred to a future shared-library mechanism, if one is ever needed.

A consequence worth stating: `.text` stays shareable read-only across processes and across both executors, because it is identical, not because it is relocatable.

**Feature discovery.** The loader checks the header's feature bits against the current executor and refuses or down-selects. Version 1 mandates the same feature set on both implementations, so one binary always runs on both; the mechanism exists for later divergence, not for present-day optionality.

## Encoding candidates pending measurement

Four ideas raised after Rev A. **None is adopted; all are decided by the T3 histogram** (DN-SW-VMBENCH-001), which is the reason the freeze moved to T4.

The motivation is one number: in the `ADD rd,rs,rt` handler, roughly 55 of \~70 cycles are fixed overhead — 18 dispatch, 25 nibble extraction, 12 PC advance — and only \~20 are the actual addition. Useful work is 25–30% of the cycles. Anything that amortises those 55 cycles over more work wins, which is why historically interpreted VMs (Z-machine, Dis) are CISC while JIT-oriented ones are RISC. This project is the former case.

| Candidate | Estimated gain | Risk | Notes |
| --- | --- | --- | --- |
| Fixed-form memory operands | 30–40% | Medium | The largest prize |
| Two-address forms (`ADD rd,rs`) | 15–20% | **None** | Already reserved in `$10–$2F` |
| `WITH` / RP prefix register | 5–10% | Medium | Adds architectural state |
| Register windows | 5–15% | High | Conflicts with 16 visible registers |

**Fixed-form memory operands.** What kills CISC interpreters is mode bytes: per-operand mode specifiers need a dispatch per operand. The winning shape is fixed-form CISC — the opcode still determines length, format and every field position, but the instruction does the work of three. `a[i] = b[i] + c` goes from \~270 cycles in three instructions to \~165 in one. Costs: the restart contract must be specified per opcode when an instruction has several faulting accesses, and it pushes the softcore toward microcode, against the hardwired-control preference. Note also that vbcc's intermediate code is quadruples whose operands may be memory directly, so a memory-to-memory VM maps onto it almost one to one — this candidate is *more* toolchain-friendly, not less. Rev A rejected Inferno Dis for having "general memory operands"; that reasoning holds for general operands with mode bytes and does not hold for fixed-form ones. The middle ground was never evaluated.

**`WITH` / RP.** A prefix register naming an implicit destination: `WITH r4` then `ADD.RP r5`, `SHL.RP #2`. Explicit `WITH` is much better than "last register accessed", which is unanalysable and diverges silently between implementations. With `WITH` the value is readable by working backwards, the backend generates it as a local peephole over runs sharing a destination, and RP updates only in its own instruction, so restart stays simple. Rules that must be fixed if adopted: **RP is undefined after any call and at every branch target** (caller-saved, runs never cross basic blocks). It is a prefix register in the Thumb-2 family, not an exotic idea. Decision criterion: runs of three or more instructions sharing a destination must be common enough; two-instruction runs are cancelled out by the `WITH` itself.

**Register windows.** SPARC-style sliding windows suit this machine better than silicon — sliding is just moving D in the interpreter, so non-call instructions pay nothing, and depth is free in EBR since a 32-bit-wide block needs 2 EBR whether it holds 16 registers or 256. Backing store fits in bank `$00` (\~500 frames of 64 bytes per process), and overflow can be caught by a guard page through ABORTB rather than an explicit check per `CALL`. **But SPARC has 32 visible registers and NVM32 has 16.** Splitting 16 into globals, in, local and out leaves four of each, and vbcc would spill constantly at \~100 cycles a spill. Raising the count breaks the 4-bit nibble, which is priority #1. Worth stealing regardless: SPARC's overlap trick where the caller's SP becomes the callee's FP, and keeping the return address inside the window so `CALL` need not save LR.

**Stack machine — rejected outright, not pending.** A stack VM does *less* work per dispatch, which is the wrong direction: `a + b` is one dispatch in registers and four on a stack, so \~220 cycles of overhead instead of \~55. Published comparisons of the two models on the same VM put the register form at about half the executed instructions, \~25% more bytes, and \~30% less time — and dispatch weighs far more here than on a modern host. C does not favour a stack either: real C code is dominated by local-variable access, and locals in a stack VM are accessed through indexed load-local/store-local, which is a register file reinvented at one dispatch per access. The empirical answer already exists: Google moved from a stack to registers when building Dalvik to interpret Java on constrained devices. The historical argument for stack VMs — no register allocator needed in the compiler — does not apply, because this project reuses a mature compiler. What is worth taking from stack machines is the frame idioms, which are already in the opcode map.

## Abandonment conditions and open questions

- If measured interpreter throughput is below \~100,000 VM-instructions per second on representative code, after the adopted optimizations and the Helium multiply/divide helper, reconsider either load-time pre-decode or switching the native format to RV32IM — buying a free toolchain and existing softcores at the cost of worse 65816 decode.
- If no encoding candidate clears its T3 criterion, freeze the ISA as specified here and stop revisiting the encoding.
- If FPGA-C and noVa128 are both abandoned, the one-binary argument disappears and the VM should be re-justified on its own merits (portability, isolation, development speed) or dropped.
- If a hot opcode is found to cost more than 150 interpreter cycles, add a superinstruction before changing the encoding.

Open questions:

- [ ] Does floating point get opcodes in the reserved space, or stay soft float? Blocks the T4 freeze.
- [ ] Which encoding candidates are adopted? Decided by the T3 histogram.
- [ ] Are the interpreter's instruction-boundary semantics for `MEMCPY` across banks identical to the softcore's flat 24-bit datapath, in write order and restart behaviour? This is the one instruction whose implementation differs most between targets; verify explicitly in the conformance suite.
- [ ] Instruction-cache coherence: if the softcore caches guest `.text`, the cache must be flushed on the relevant TLB and ASID events. Specify in DN-HW-VMCORE-001 before implementation.
- [ ] Does the kernel stay 65816-native, move to NVM32, or split? Argon makes all three possible; the coprocessor model does not.

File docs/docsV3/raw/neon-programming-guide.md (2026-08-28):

# Neon — Programming Guide

**Project:** DANI-65816
**Companion to:** *Neon — GPU Specification*, rev 1.0
**Date:** 2026-08-14
**Status:** Draft. Section 8 lists changes this guide forces back into the specification.

---

## 1. Purpose and Assumptions

Three worked examples — a text console, a windowed GUI, and a side-scrolling platformer — written as the software would actually be structured, not as pseudocode.

**Assumptions, all of which should be verified before this code is trusted:**

| Assumption | Status |
|---|---|
| Calypsi C, C99, large code model, 24-bit data pointers | Established for the project |
| `(volatile uint8_t *)0xFE0000` compiles to absolute-long addressing | **Unverified** — see O-13 |
| Bank `$FE` mapped and accessible to the calling code (kernel context) | Per existing protection model |
| Calypsi direct-page pseudo-register usage | **Audit outstanding** — a known project blocker |
| 65816 at 8 MHz | Established |

Code is written for clarity. The two loops that matter for performance — the console glyph store and the per-frame list patch — are marked as assembly candidates.

---

## 2. Layer 0 — Register and Aperture Access

```c
#include <stdint.h>

#define NEON_APERTURE   ((volatile uint8_t *)0xFE0000)
#define NEON_TEXT       ((volatile uint16_t *)0xFE0000)  /* mode 0 */
#define NEON_FONT       ((volatile uint8_t *)0xFE2000)   /* mode 0 */
#define NEON_PALETTE    ((volatile uint8_t *)0xFE8000)
#define NEON_REG        ((volatile uint8_t *)0xFEFF00)

/* Register offsets — see specification §17 */
enum {
    R_ID = 0x00, R_VER = 0x01, R_MODE = 0x02, R_CTRL = 0x03,
    R_STATUS = 0x04, R_BORDER = 0x05,
    R_RASTER = 0x06, R_RASTER_CMP = 0x08,
    R_IRQ_EN = 0x0A, R_IRQ_STATUS = 0x0B, R_IRQ_TAG = 0x0C,
    R_TEXT_START = 0x10, R_CURSOR_POS = 0x12, R_CURSOR_CTRL = 0x14,
    R_DISPLAY_BASE = 0x18, R_DRAW_BASE = 0x1B,
    R_MONO_FG = 0x1E, R_MONO_BG = 0x1F,
    R_VRAM_PAGE = 0x20, R_LINE_STRIDE = 0x21,
    R_CMD_PORT = 0x50, R_CMD_FIFO_FREE = 0x54, R_CMD_CTRL = 0x55,
    R_LIST_BASE = 0x56, R_LIST_PC = 0x59,
    R_PEEK_ADDR = 0x70, R_PEEK_DATA = 0x73
};

#define ST_VBLANK       0x01
#define ST_BLIT_BUSY    0x04
#define ST_CMD_BUSY     0x08
#define ST_PEEK_READY   0x10

#define MODE_TEXT       0
#define MODE_HIRES      1
#define MODE_320        2
#define MODE_512        3
```

Two access patterns recur and are worth isolating, because both depend on hardware latching behaviour:

```c
/* 16-bit registers latch on the HIGH byte write. A 16-bit store writes
   low then high, so the update is atomic with no explicit sequencing. */
static inline void neon_reg16(uint8_t off, uint16_t v) {
    *(volatile uint16_t *)(NEON_REG + off) = v;
}

/* 24-bit address registers: three byte writes, low to high.
   The register takes effect on the write to the high byte. */
static inline void neon_reg24(uint8_t off, uint32_t v) {
    NEON_REG[off]     = (uint8_t)(v);
    NEON_REG[off + 1] = (uint8_t)(v >> 8);
    NEON_REG[off + 2] = (uint8_t)(v >> 16);
}
```

Detecting Neon at all:

```c
int neon_present(void) { return NEON_REG[R_ID] == 0x4E; }
```

---

## 3. Command Encoding

### 3.1 Revision: commands take coordinates, not addresses

An earlier draft of the specification had blitter commands carry 24-bit source and destination *addresses*. In writing the game example it became clear this is the wrong interface. Computing `dst = base + y * stride + x` on the 65816 costs a shift-and-add sequence per sprite per frame — the CPU has no multiplier — and it has to happen for every object every frame, which is precisely the cost this architecture exists to eliminate.

**Commands now carry `(x, y)` in pixels.** Neon computes the address using `DRAW_BASE` and `LINE_STRIDE`. The `y × stride` multiply is one sequential multiply per command in the command processor, roughly 16 clocks at 102 MHz — about 160 ns against a command that takes tens of microseconds. It costs Neon nothing and removes real work from every frame of every program.

A second, larger consequence follows: because the destination is a coordinate pair packed into one 32-bit word, **moving an object is a single 32-bit patch to one word of a display list**. This is what makes §7 cost 140 µs per frame instead of several milliseconds.

### 3.2 Word layouts

```c
enum {
    OP_NOP = 0x00, OP_SET_CLIP = 0x01,
    OP_FILL_RECT = 0x10, OP_FILL_PATTERN = 0x11,
    OP_COPY_RECT = 0x20, OP_COPY_KEYED = 0x21,
    OP_COPY_TILED = 0x22, OP_COPY_EXPAND = 0x23,
    OP_DRAW_LINE = 0x30, OP_DRAW_HLINE = 0x31, OP_DRAW_VLINE = 0x32,
    OP_WAIT_VBLANK = 0xF0, OP_WAIT_LINE = 0xF1, OP_SWAP = 0xF2,
    OP_SET_PALETTE = 0xF3, OP_SIGNAL = 0xF8,
    OP_JUMP = 0xFC, OP_CALL = 0xFD, OP_RET = 0xFE, OP_END = 0xFF
};

#define CMD_HDR(op, flags, n)  \
    (((uint32_t)(op) << 24) | ((uint32_t)(flags) << 16) | (uint16_t)(n))

#define XY(x, y)  (((uint32_t)(uint16_t)(y) << 16) | (uint16_t)(x))
#define WH(w, h)  (((uint32_t)(uint16_t)(h) << 16) | (uint16_t)(w))
```

`FILL_RECT` — 4 words:

```
w0  header, count = 3
w1  XY(x, y)
w2  WH(w, h)
w3  colour in bits 7:0
```

`COPY_KEYED` — 6 words. `COPY_RECT` is identical with the key field ignored:

```
w0  header, count = 5
w1  XY(src_x, src_y)        <- patch offset +4
w2  XY(dst_x, dst_y)        <- patch offset +8
w3  WH(w, h)
w4  src_base, 24-bit        (the atlas or level buffer)
w5  bits 31:24 key, bits 15:0 src_stride
```

Destination base and stride come from `DRAW_BASE` and `LINE_STRIDE`. Source base and stride are explicit, because atlases and level buffers have their own geometry.

`COPY_EXPAND` — 6 words, source 1-bpp, with foreground and background colours in w5.

### 3.3 Emitting to the FIFO

`CMD_PORT` latches on the write to offset `$53`. Two 16-bit stores in ascending order produce that naturally:

```c
static void cmd_push(uint32_t w) {
    *(volatile uint16_t *)(NEON_REG + R_CMD_PORT)     = (uint16_t)w;
    *(volatile uint16_t *)(NEON_REG + R_CMD_PORT + 2) = (uint16_t)(w >> 16);
}

/* Reserve space for a whole command before emitting any of it, so the
   engine never stalls part-way through decoding one. */
static void cmd_reserve(uint8_t words) {
    while (NEON_REG[R_CMD_FIFO_FREE] < words) { }
}

void neon_fill_rect(int16_t x, int16_t y, uint16_t w, uint16_t h, uint8_t c) {
    cmd_reserve(4);
    cmd_push(CMD_HDR(OP_FILL_RECT, 0, 3));
    cmd_push(XY(x, y));
    cmd_push(WH(w, h));
    cmd_push(c);
}

void neon_copy_keyed(uint32_t src_base, uint16_t src_stride,
                     int16_t sx, int16_t sy, int16_t dx, int16_t dy,
                     uint16_t w, uint16_t h, uint8_t key) {
    cmd_reserve(6);
    cmd_push(CMD_HDR(OP_COPY_KEYED, 0x01, 5));   /* flag 0x01 = key enable */
    cmd_push(XY(sx, sy));
    cmd_push(XY(dx, dy));
    cmd_push(WH(w, h));
    cmd_push(src_base);
    cmd_push(((uint32_t)key << 24) | src_stride);
}
```

---

## 4. Example 1 — Text Console

Mode 0 needs no initialisation. Neon is already displaying when the first line of C runs. The console is a ring pointer, a cursor, and a current attribute.

```c
typedef struct {
    uint16_t cursor;   /* buffer-absolute cell index, 0..4095 */
    uint16_t top;      /* shadow of TEXT_START                */
    uint8_t  col;      /* 0..127                              */
    uint8_t  attr;     /* bg<<4 | fg                          */
} console_t;

static console_t con;

#define COLS 128
#define ROWS 32
#define CELLS (COLS * ROWS)     /* 4096, a power of two */

void con_init(uint8_t attr) {
    con.cursor = 0; con.top = 0; con.col = 0; con.attr = attr;
    for (uint16_t i = 0; i < CELLS; i++)
        NEON_TEXT[i] = ((uint16_t)attr << 8) | ' ';
    neon_reg16(R_TEXT_START, 0);
    neon_reg16(R_CURSOR_POS, 0);
    NEON_REG[R_CURSOR_CTRL] = 0x14;      /* underline, 1 Hz, enabled */
}
```

### 4.1 Scrolling is a pointer move

```c
static void con_scroll(void) {
    con.top = (con.top + COLS) & (CELLS - 1);
    neon_reg16(R_TEXT_START, con.top);

    /* Clear the row that just became the bottom line. */
    uint16_t i = (con.top + (ROWS - 1) * COLS) & (CELLS - 1);
    uint16_t fill = ((uint16_t)con.attr << 8) | ' ';
    for (uint8_t n = 0; n < COLS; n++) {
        NEON_TEXT[i] = fill;
        i = (i + 1) & (CELLS - 1);
    }
    con.cursor = (con.top + (ROWS - 1) * COLS) & (CELLS - 1);
    con.col = 0;
}
```

256 bytes written instead of 8,192 moved: **~160 µs instead of ~5 ms**. On a console that scrolls continuously during boot, this is the difference between visible lag and none.

### 4.2 Character output

```c
void con_putc(char c) {
    if (c == '\n') { con_newline(); return; }
    if (c == '\r') { con.cursor -= con.col; con.col = 0; return; }

    NEON_TEXT[con.cursor] = ((uint16_t)con.attr << 8) | (uint8_t)c;
    con.cursor = (con.cursor + 1) & (CELLS - 1);
    if (++con.col >= COLS) con_newline();
    else neon_reg16(R_CURSOR_POS, con.cursor);
}

static void con_newline(void) {
    con.cursor = (con.cursor + (COLS - con.col)) & (CELLS - 1);
    con.col = 0;
    uint16_t row = ((con.cursor - con.top) & (CELLS - 1)) / COLS;
    if (row >= ROWS) con_scroll();
    neon_reg16(R_CURSOR_POS, con.cursor);
}

void con_puts(const char *s) { while (*s) con_putc(*s++); }
```

> **Assembly candidate.** `con_putc` is called once per character during boot and once per character of every kernel message. A hand-written version storing directly with absolute-long indexed addressing avoids the pointer arithmetic Calypsi will generate around `NEON_TEXT[con.cursor]`. The C version is correct; the assembly version is perhaps 3× faster and worth writing once the direct-page convention audit is complete.

### 4.3 Loading a font

```c
void con_load_font(const uint8_t *font4k) {
    while (!(NEON_REG[R_STATUS] & ST_VBLANK)) { }   /* avoid a torn frame */
    for (uint16_t i = 0; i < 4096; i++) NEON_FONT[i] = font4k[i];
}
```

### 4.4 What the OS adds

The hardware path is identical for BIOS and kernel. The kernel wraps it:

```c
/* Kernel driver, five-function interface, reached via /dev/tty */
static int tty_init(void)  { con_init(0x0F); return 0; }
static int tty_write(const void *buf, size_t n) {
    const char *p = buf;
    for (size_t i = 0; i < n; i++) con_putc(p[i]);
    return (int)n;
}
static int tty_ioctl(int req, void *arg);   /* colour, cursor shape, font */
```

**One constraint must be designed in from the start.** The text buffer occupies EBR that graphics modes may reclaim (specification O-3). The tty driver must therefore keep its own scrollback in system memory and be able to repaint the screen from it, because switching to a graphics mode and back can destroy the buffer contents. This is normal for a virtual-console design, but it cannot be retrofitted cheaply.

---

## 5. Example 2 — Windowed GUI

Mode 1: 1024 × 600, 1 bpp, 75 KB per buffer.

### 5.1 VRAM layout

```c
#define VRAM_FB0        0x000000UL      /*  76,800 B  front buffer   */
#define VRAM_FB1        0x013000UL      /*  76,800 B  back buffer    */
#define VRAM_GLYPHS     0x026000UL      /* 1-bpp font atlas          */
#define VRAM_ICONS      0x030000UL      /* 1-bpp icon atlas          */
#define VRAM_SAVEUNDER  0x040000UL      /* scratch for occlusion     */

#define FB_STRIDE 128                   /* 1024 px / 8 px per byte   */

void gui_init(void) {
    NEON_REG[R_MODE] = MODE_HIRES;
    neon_reg24(R_DISPLAY_BASE, VRAM_FB0);
    neon_reg24(R_DRAW_BASE,    VRAM_FB0);   /* single-buffered: GUI is
                                               event-driven, not animated */
    neon_reg16(R_LINE_STRIDE,  FB_STRIDE);
    NEON_REG[R_MONO_FG] = 0x0F;
    NEON_REG[R_MONO_BG] = 0x00;
    NEON_REG[R_CTRL]    = 0x03;             /* display + backlight    */
}
```

A GUI is repaint-on-event, not redraw-per-frame, so single buffering is correct here and halves the memory. Double buffering would add tearing-free full-screen transitions; it is available if wanted and costs 75 KB.

### 5.2 Text in graphics mode

The EBR font of Mode 0 does not exist here. UI text comes from a 1-bpp glyph atlas in VRAM, drawn with `COPY_EXPAND`, with a width table in system memory so the font can be proportional.

```c
extern const uint8_t glyph_w[96];     /* widths for ' '..'~'         */
extern const uint16_t glyph_x[96];    /* x offset into the atlas     */
#define GLYPH_H 14
#define GLYPH_ATLAS_STRIDE 256

int gui_text(int16_t x, int16_t y, const char *s, uint8_t fg, uint8_t bg) {
    while (*s) {
        uint8_t g = (uint8_t)*s++ - ' ';
        if (g < 96) {
            cmd_reserve(6);
            cmd_push(CMD_HDR(OP_COPY_EXPAND, 0, 5));
            cmd_push(XY(glyph_x[g], 0));
            cmd_push(XY(x, y));
            cmd_push(WH(glyph_w[g], GLYPH_H));
            cmd_push(VRAM_GLYPHS);
            cmd_push(((uint32_t)bg << 24) | ((uint32_t)fg << 16)
                     | GLYPH_ATLAS_STRIDE);
            x += glyph_w[g];
        }
    }
    return x;
}
```

One command per glyph — six words, 24 bytes. A 40-character window title is 960 bytes through the aperture, about **600 µs of CPU**. For a title drawn on window creation this is fine. For a text editor repainting a full screen of text it is not, and such a program should build a display list once and patch it, exactly as the game in §7 does.

### 5.3 Windows

```c
typedef struct window {
    int16_t x, y;
    uint16_t w, h;
    const char *title;
    struct window *next;      /* front to back */
} window_t;

static window_t *z_top;

#define C_FACE   0
#define C_EDGE   1
#define C_TITLE  1
#define TITLE_H  18

void win_paint(const window_t *win) {
    cmd_reserve(4);
    cmd_push(CMD_HDR(OP_SET_CLIP, 0, 3));
    cmd_push(XY(win->x, win->y));
    cmd_push(XY(win->x + win->w - 1, win->y + win->h - 1));
    cmd_push(0);

    neon_fill_rect(win->x, win->y, win->w, win->h, C_FACE);
    neon_fill_rect(win->x, win->y, win->w, TITLE_H, C_TITLE);
    neon_hline(win->x, win->y, win->w, C_EDGE);
    neon_hline(win->x, win->y + win->h - 1, win->w, C_EDGE);
    neon_vline(win->x, win->y, win->h, C_EDGE);
    neon_vline(win->x + win->w - 1, win->y, win->h, C_EDGE);

    neon_copy_keyed(VRAM_ICONS, 64, 0, 0,
                    win->x + 3, win->y + 2, 16, 16, 0);
    gui_text(win->x + 24, win->y + 3, win->title, C_FACE, C_TITLE);
}
```

Roughly a dozen commands plus one per title character. **The CPU never writes a pixel.** It emits perhaps 1.2 KB of command words; the blitter does the drawing while the CPU returns to the event loop.

### 5.4 Moving a window without repainting it

```c
void win_move(window_t *win, int16_t nx, int16_t ny) {
    int16_t ox = win->x, oy = win->y;

    cmd_reserve(6);
    cmd_push(CMD_HDR(OP_COPY_RECT, 0, 5));
    cmd_push(XY(ox, oy));
    cmd_push(XY(nx, ny));
    cmd_push(WH(win->w, win->h));
    cmd_push(VRAM_FB0);            /* source is the screen itself */
    cmd_push(FB_STRIDE);

    win->x = nx; win->y = ny;
    desktop_repaint_exposed(ox, oy, win->w, win->h, win);
}
```

A 400 × 300 window at 1 bpp is 15,000 bytes; read plus write is **~0.3 ms**. Dragging at 60 Hz is comfortable.

`COPY_RECT` is overlap-safe: the engine selects the traversal direction from the sign of the displacement, so a small drag that overlaps source and destination is correct without software intervention.

### 5.5 Save-under, despite the write-only aperture

The specification forbids the CPU reading VRAM. It does **not** forbid the blitter reading VRAM. Save-under therefore works normally, as long as the saved pixels never travel through the CPU:

```c
void menu_open(int16_t x, int16_t y, uint16_t w, uint16_t h) {
    cmd_reserve(6);
    cmd_push(CMD_HDR(OP_COPY_RECT, 0, 5));
    cmd_push(XY(x, y));
    cmd_push(XY(0, 0));                 /* into the save-under buffer  */
    cmd_push(WH(w, h));
    cmd_push(VRAM_FB0);
    cmd_push(FB_STRIDE);
    /* draw the menu over the top */
}

void menu_close(int16_t x, int16_t y, uint16_t w, uint16_t h) {
    cmd_reserve(6);
    cmd_push(CMD_HDR(OP_COPY_RECT, 0, 5));
    cmd_push(XY(0, 0));
    cmd_push(XY(x, y));
    cmd_push(WH(w, h));
    cmd_push(VRAM_SAVEUNDER);
    cmd_push(w > 1024 ? w : 1024);
}
```

The only genuinely unavailable operation is the CPU *inspecting* pixels — screen capture and a colour-picker tool. Both can use `PEEK` and tolerate roughly 20 cycles per byte.

### 5.6 Mouse pointer

The hardware cursor moves independently of everything above. No repaint, no save-under, no interaction with the command stream:

```c
static inline void gui_pointer(uint16_t x, uint16_t y) {
    neon_reg16(0x60, x);
    neon_reg16(0x62, y);
}
```

This is the one case where dedicated hardware beat the blitter, and it is why the cursor survived when the sprite engine did not.

---

## 6. Example 3 — Side-Scrolling Platformer

Mode 2a: 320 × 200, 256 colours, double buffered.

### 6.1 The approach that does not work

The obvious method is a tilemap in system memory redrawn each frame, one `COPY_RECT` per tile. The blitter manages it easily — 260 tiles of 16 × 16 in about 1.3 ms.

**The CPU cannot feed it.** 260 commands × 6 words × 4 bytes = 6,240 bytes through the aperture at ~1.3 MB/s = **4.8 ms per frame**, nearly a third of the budget spent emitting commands rather than drawing. The bottleneck moves from the blitter to the command stream.

This is the trap the display list exists to avoid, and it is worth understanding before reading the alternative.

### 6.2 The approach that works: pre-rendered level, one command

SDRAM is 32 MB. Spend it.

At level load, render the whole level background once into a wide SDRAM buffer. A level 8,192 px wide by 200 high at 8 bpp is **1.64 MB** — five percent of memory. The tile-by-tile rendering happens once, during a load screen, where its cost is irrelevant.

```c
#define VRAM_FB0      0x000000UL     /*  64,000 B */
#define VRAM_FB1      0x010000UL     /*  64,000 B */
#define VRAM_LEVEL    0x020000UL     /* 8192 x 200 = 1,638,400 B */
#define VRAM_SKY      0x1C0000UL     /* 2048 x 200 parallax layer */
#define VRAM_SPRITES  0x200000UL     /* sprite atlas */
#define VRAM_LIST     0x280000UL     /* display list */

#define LEVEL_STRIDE  8192
#define SKY_STRIDE    2048
#define ATLAS_STRIDE  512
#define SCREEN_W      320
#define SCREEN_H      200
#define MAX_SPRITES   24
```

Per frame, the entire scrolling background is **one command**:

```
COPY_RECT  src = (scroll_x, 0)  in VRAM_LEVEL, stride 8192
           dst = (0, 0)         in the back buffer, stride 320
           w = 320, h = 200
```

A source stride of 8,192 windows a 320-pixel viewport out of the level. Scrolling is a change to `scroll_x` — **one 16-bit store**. Cost: ~1.0 ms of blitter time, six command words emitted once and never again.

### 6.3 Building the display list

The list is written through the aperture at load time. Each command's byte offset is retained so its parameters can be patched later.

```c
typedef uint16_t ref_t;      /* byte offset into the list */

static uint16_t list_off;    /* write cursor within the list */

static void list_word(uint32_t w) {
    *(volatile uint32_t *)(NEON_APERTURE + list_off) = w;
    list_off += 4;
}

static void list_begin(void) {
    NEON_REG[R_VRAM_PAGE] = (uint8_t)(VRAM_LIST >> 15);
    list_off = (uint16_t)(VRAM_LIST & 0x7FFF);
}
```

The whole list is well under 32 KB, so `VRAM_PAGE` is set once at build time and again once before the first patch, then never touched. This matters: if patching required a page switch it would cost a register write per sprite.

```c
static ref_t emit_copy(uint8_t op, uint8_t flags, uint32_t base,
                       uint16_t stride, uint16_t sx, uint16_t sy,
                       uint16_t dx, uint16_t dy,
                       uint16_t w, uint16_t h, uint8_t key) {
    ref_t r = list_off;
    list_word(CMD_HDR(op, flags, 5));
    list_word(XY(sx, sy));            /* r + 4  */
    list_word(XY(dx, dy));            /* r + 8  */
    list_word(WH(w, h));              /* r + 12 */
    list_word(base);
    list_word(((uint32_t)key << 24) | stride);
    return r;
}

static ref_t r_sky, r_bg;
static ref_t r_spr[MAX_SPRITES];

void build_frame_list(void) {
    list_begin();
    uint16_t start = list_off;

    list_word(CMD_HDR(OP_WAIT_VBLANK, 0, 0));
    list_word(CMD_HDR(OP_SWAP, 0, 0));

    r_sky = emit_copy(OP_COPY_RECT, 0, VRAM_SKY, SKY_STRIDE,
                      0, 0, 0, 0, SCREEN_W, SCREEN_H, 0);
    r_bg  = emit_copy(OP_COPY_KEYED, 0x01, VRAM_LEVEL, LEVEL_STRIDE,
                      0, 0, 0, 0, SCREEN_W, SCREEN_H, 0);

    for (int i = 0; i < MAX_SPRITES; i++)
        r_spr[i] = emit_copy(OP_COPY_KEYED, 0x01, VRAM_SPRITES,
                             ATLAS_STRIDE, 0, 0, 0, 400, 32, 32, 0);
        /* y = 400 parks unused sprites off-screen; the clip
           rectangle rejects them at zero cost */

    list_word(CMD_HDR(OP_SIGNAL, 0, 1));
    list_word(1);
    list_word(CMD_HDR(OP_JUMP, 0, 1));
    list_word(VRAM_LIST);

    (void)start;
}
```

Note the parking convention. An unused sprite slot is not removed from the list — removing it would mean rewriting the list every time an enemy dies. It is moved off-screen, where the clip rectangle rejects it before any memory traffic occurs. The list is structurally static for the whole level.

### 6.4 Starting it

```c
void game_start(void) {
    NEON_REG[R_MODE] = MODE_320;
    neon_reg16(R_LINE_STRIDE, SCREEN_W);
    neon_reg24(R_DISPLAY_BASE, VRAM_FB0);
    neon_reg24(R_DRAW_BASE,    VRAM_FB1);
    build_frame_list();
    neon_reg24(R_LIST_BASE, VRAM_LIST);
    NEON_REG[R_CMD_CTRL] = 0x02;          /* LIST_RUN */
}
```

**From this point Neon renders continuously with no CPU involvement.** If the game logic stopped entirely, the display would keep refreshing at 60 Hz with the last-patched contents.

### 6.5 The per-frame loop

```c
static inline void patch32(ref_t r, uint32_t v) {
    *(volatile uint32_t *)(NEON_APERTURE + (r & 0x7FFF)) = v;
}

typedef struct { int16_t x, y; uint8_t frame; uint8_t alive; } actor_t;
static actor_t actor[MAX_SPRITES];
static uint16_t scroll_x;

void game_frame(void) {
    /* 1. Wait for the frame just drawn. */
    while (!(NEON_REG[R_IRQ_STATUS] & 0x04)) { }
    NEON_REG[R_IRQ_STATUS] = 0x04;

    /* 2. Game logic — physics, collision, AI, input.
          ~99% of the frame is available here. */
    game_update();

    /* 3. Patch the list. This is the entire cost of rendering. */
    patch32(r_bg  + 4, XY(scroll_x, 0));
    patch32(r_sky + 4, XY(scroll_x >> 2, 0));      /* parallax */

    for (int i = 0; i < MAX_SPRITES; i++) {
        if (actor[i].alive) {
            patch32(r_spr[i] + 4, XY((actor[i].frame & 7) * 32,
                                     (actor[i].frame >> 3) * 32));
            patch32(r_spr[i] + 8, XY(actor[i].x - scroll_x, actor[i].y));
        } else {
            patch32(r_spr[i] + 8, XY(0, 400));     /* park off-screen */
        }
    }
}
```

> **Assembly candidate.** The patch loop runs 48 32-bit stores per frame. A hand-written version using absolute-long indexed addressing with a fixed unroll would roughly halve it. Not required — 140 µs is already under 1% of the frame — but it is the natural place to look if the budget ever tightens.

### 6.6 Synchronisation

The list ends with `SIGNAL 1` immediately before it loops back to `WAIT_VBLANK`. The CPU patches in the interval between that signal and the start of the next frame's drawing. No lock is taken, the engine never stalls, and a patch that arrives late affects the following frame rather than tearing the current one.

`CMD_CTRL.LIST_LOCK` is reserved for structural changes — adding commands, switching levels — where the list is being rewritten rather than patched.

### 6.7 Cost accounting

| Blitter, per frame | |
|---|---|
| Parallax sky | ~1.0 ms |
| Level background, keyed | ~1.4 ms |
| 24 sprites at 32 × 32 | ~0.4 ms |
| **Total** | **~2.8 ms of 15.5 ms available** |

| CPU, per frame | |
|---|---|
| 50 patch words | ~180 µs |
| **Fraction of the 16.7 ms frame** | **~1.1%** |

**Roughly 18% of the drawing budget and 1% of the CPU.** What remains is enough for a third parallax layer, a full-screen palette effect, or several times as many actors — and, more to the point, essentially the entire 65816 for game logic.

### 6.8 Level loading

The level buffer is 1.64 MB. Through the CPU aperture at ~1.3 MB/s that is roughly 1.2 seconds of fully occupied CPU. Through the service port from microSD at ~2.5 MB/s it is roughly 0.6 seconds and costs the CPU nothing.

For a load screen either is acceptable, but the service-port path is strictly better and is the argument for resolving specification item O-11 in favour of giving the service port SDRAM access.

---

## 7. Summary

| | Mechanism | Init required | CPU per frame / operation |
|---|---|---|---|
| Boot display | Bitstream-initialised EBR | none | none — no CPU yet |
| BIOS text | Direct stores to `$FE:0000` | none | ~2 µs per character |
| OS text | Same, wrapped in a driver | none | ~2 µs per character |
| GUI | Command FIFO, blitter draws | mode + bases | ~1 ms per window paint |
| Game | SDRAM display list | mode + list build | **~180 µs per frame** |

Each layer works without the one below it in this table. A failure in the command processor still leaves a working console; a failure in SDRAM still leaves a working boot display.

---

## 8. Changes This Guide Forces Back Into the Specification

| Change | Section affected |
|---|---|
| Blitter commands take `(x, y)` coordinates, not 24-bit addresses; Neon computes `base + y × stride + x` | §14.5 command format |
| `COPY_KEYED` and `COPY_RECT` are 6 words, not 7 | §14.5 |
| Destination base and stride come from `DRAW_BASE` / `LINE_STRIDE`; source base and stride are per-command | §14.5, §17 |
| Command processor requires a sequential multiplier (~16 clocks per command, ~80 LUT) | §18 logic budget |
| `LINE_STRIDE` register added at `$21`–`$22` | §17 |
| Off-screen parking of unused list entries is the supported idiom; the clip rectangle must reject fully-off-screen rectangles before any memory traffic | §12.1 |
| Command processor must sign-extend coordinates and clip negatives, so objects can be partially off the left or top edge | §12.1 |

---

## 9. New Open Items

| ID | Item | Blocks |
|---|---|---|
| **O-13** | Verify Calypsi generates absolute-long addressing for `(volatile uint8_t *)0xFE0000` without a bank-register reload per access | All Neon C code |
| **O-14** | Ratify the coordinate-based command format and budget the multiplier | N4 |
| **O-15** | Confirm the clip unit rejects off-screen rectangles before issuing memory traffic — the parking idiom depends on it | N2 |
| **O-16** | Define who owns SDRAM partitioning between framebuffers, atlases, level buffers, and lists; the constants in §5.1 and §6.2 are placeholders | N2 |
| **O-17** | Whether `COPY_EXPAND` reads its 1-bpp source with a bit-granular x offset, or glyph atlas entries must be byte-aligned | N3 |

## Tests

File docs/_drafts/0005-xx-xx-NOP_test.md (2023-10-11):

---
categories: cpu
---

Primer arranque de la CPU.

No necesito más que la CPU y la FPGA. Es un NOP test por lo que emito NOPS en el databus. Y veo avanzar la dirección.

FPGA provee clock.

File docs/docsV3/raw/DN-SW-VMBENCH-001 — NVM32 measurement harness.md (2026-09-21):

# DN-SW-VMBENCH-001 — NVM32 measurement harness

*noVa64 · Rev A (draft for discussion)* · 2026-09-20 · @Someone

## Revision history

| Rev | Date | Change |
| --- | --- | --- |
| A | 2026-09-20 | Initial draft. Metrics, pattern counters, benchmark set and the decision criteria that gate the ISA freeze at T4. |

*Review cycle: reviewers, dates and decisions to be recorded here before this note leaves draft status.*

## Purpose

Four encoding candidates are competing in DN-SW-VMISA-001 and none can be decided by argument. This harness turns each of them into a query against measured data, so the ISA freezes on evidence rather than taste.

**It needs no hardware and no compiler.** It runs entirely on the PC against the C11 reference interpreter, which is Stage 1 of the VM programme. That makes it the cheapest possible way to retire the biggest open risk in the ISA.

Sequencing: the reference interpreter produces the counters; the counters decide the candidates at gate T3; the ISA freezes at gate T4 (DN-SW-VMCC-001). This ordering is the reason the freeze moved out of Stage 0 — freezing before any measurement existed is how a permanent encoding mistake gets made.

A second job, later: once the 65816 interpreter exists, the same harness calibrates the cost model against real cycle counts and re-runs the whole history.

## Metrics

Four numbers per benchmark. Counting VM instructions alone is not enough: a `MEMCPY` and a `NOP` count the same, and the candidates under evaluation change precisely how many instructions do the same work.

| Metric | What it measures | Source |
| --- | --- | --- |
| VM instructions executed | Dynamic work | Counter in the reference interpreter |
| **Estimated 65816 cycles** | The metric that decides | Instruction counts × a per-opcode cost table |
| `.text` bytes | Code density (priority #2) and Argon's code bandwidth | Section size |
| Guest memory accesses | The softcore's bottleneck, and cache pressure | Counter in load and store handlers |

**The cost model is the core of this note.** A per-opcode table in 65816 cycles, derived from the handlers in DN-SW-VMINTERP-001. It does not need to be accurate; it needs to be **consistent**, because every use compares variants against each other. When the real interpreter exists, calibrate the table against measured cycles and re-run the stored history so old comparisons remain valid.

**Why the fourth metric exists.** On real hardware, cache misses with PHI2 stopped dominate wall-clock time, and the cycle model cannot see that. Guest memory accesses are the available proxy for cache pressure until hardware measurement is possible.

The opcode histogram is not a fifth metric but the harness's main output: it is what answers the pending ISA questions.

## Pattern counters

The part most harnesses skip. The interpreter records **patterns, not just opcodes**, so each pending ISA question is answered before anything is implemented. This is far cheaper than building four ISA variants and comparing them.

| Counter | Answers |
| --- | --- |
| Adjacent load-op and op-store pairs | Value of fixed-form memory operands |
| Instructions where `rd == rs` | Value of two-address forms |
| Runs of N instructions sharing a destination, with the histogram of N | Value of `WITH`/RP |
| Calls per thousand instructions, and mean stack depth | Value of register windows |
| Branch distance distribution | Whether disp16 is the right size |
| Immediate value distribution | Whether smaller immediate forms would pay |
| Register pressure: live values at each point | Whether 16 registers is right, and what windows would cost |

Each counter is a few lines in the reference interpreter and costs nothing at run time on the real machine, because it exists only in the PC model.

The design rule: **before proposing an encoding change, add the counter that would justify it.** A proposal without a counter is not ready to be argued about.

## Benchmark set

Three groups, each answering a different question.

**Standard** — for comparability with published numbers:

- **Dhrystone**, mandatory for comparability but notoriously unrepresentative: heavy on string handling, light on real arithmetic. Report it, never optimize for it.
- **Coremark**, designed specifically to correct Dhrystone's defects.

**Real noVa64 code** — the only group that says whether a change matters:

- **NVFS code**, the best available candidate today: already written, already has a test suite, and exercises pointer and structure handling.
- A GUI workload once one exists.

**Synthetic kernels** — each isolating one axis, to explain *why* a number moved:

- Array traversal (sequential access, loop overhead)
- Linked-list walk (pointer-intensive, cache-hostile)
- Recursion (call density, stack depth)
- Structure copy (block operations)
- Call-heavy code with shallow bodies (frame cost, the register-window question)
- Expression-heavy arithmetic (the `WITH`/RP question)

Until the compiler exists at gate T2, the synthetic kernels are written by hand in NVM32 assembly — tedious but feasible, and they are the group that matters most for encoding decisions. The real programs wait for the compiler.

## Method and discipline

This is where benchmark suites usually rot. Four rules:

1. **The benchmark set is frozen.** Changing it invalidates the whole history. Additions go in a clearly separated second set with its own baseline.
2. **Results are versioned with the code**, as CSV or JSON in the repository. Every interpreter commit produces a row. What is wanted is a trend over months, not isolated figures.
3. **A variant is measured against the baseline from the same source**, recompiled or reassembled. Never compare hand-tuned code for one variant against generic code for another.
4. **Regression is automatic.** If a change worsens a metric by more than a set threshold, the build fails. Same differential harness already used for NVFS.

**Cost-model calibration.** Until the 65816 interpreter exists, the cycle figures are estimates from the datasheet. When it exists, measure per-handler costs on real hardware, update the table, and re-run the stored history. Record the calibration date in the results so nobody compares pre- and post-calibration numbers without noticing.

**What the harness cannot see:** PHI2 stall time on cache misses. Every number here is a cycle-model number, and on hardware the real figure will be worse by an amount that depends on working-set size. State that caveat next to any throughput claim that leaves this project.

## Decision criteria

Written in advance, so the measurement decides rather than the person reading it. Each threshold is a first proposal to be ratified before the counters are run — setting them afterwards is how a benchmark becomes an argument.

| Candidate | Counter | Adopt if | Otherwise |
| --- | --- | --- | --- |
| Fixed-form memory operands | Adjacent load-op / op-store pairs | More than 20% of executed instructions participate in such a pair | Reject; the restart and microcode cost is not repaid |
| Two-address forms | Instructions with `rd == rs` | Any measurable share — the opcodes are already reserved and the cost is zero | Keep them reserved, unused |
| `WITH` / RP | Runs of ≥3 instructions sharing a destination | More than 20–25% of instructions sit in such a run | Reject; two-address forms already captured the benefit |
| Register windows | Calls per thousand instructions, mean depth | Call-dense code with shallow frames, and spill counts that windows would remove | Reject; the 16-register conflict is not worth 5–15% |
| Superinstruction for a hot opcode | Per-opcode cycle share | Any single opcode exceeds 150 interpreter cycles or a large share of total cycles | No action |

The general rule from DN-SW-VMISA-001 applies: a candidate that adds architectural state must clear a higher bar than one that does not, because {R0–R15, PC} is what makes migration and cheap preemption work.

## Abandonment conditions and open questions

- If hand-writing the synthetic kernels in NVM32 assembly proves slower than expected, cut the set to three — array traversal, linked-list walk, call-heavy — and accept narrower evidence rather than delaying gate T3.
- If the cost model cannot be calibrated to within ±25% of measured 65816 cycles, stop reporting estimated cycles as a headline number and use instruction counts plus memory accesses instead.
- If no candidate clears its criterion, freeze the ISA and retire this harness's encoding role; it continues as a regression gate only.

Open questions:

- [ ] What exactly is the benchmark set for the project as a whole? Dhrystone plus Coremark plus two real noVa64 programs is the proposal; it needs ratifying before anything is frozen.
- [ ] Are the decision thresholds above accepted as written?
- [ ] Where do results live — the interpreter's repository, or a separate one shared with the gateware work?
- [ ] Does the harness also measure the softcore through Verilator, or only the reference interpreter and the 65816?
- [ ] Who owns re-running the history after a cost-model calibration?

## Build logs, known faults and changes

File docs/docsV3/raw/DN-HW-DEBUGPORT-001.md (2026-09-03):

# DN-HW-DEBUGPORT-001 — Integrated Debug and Programming Port

**Project:** noVa64 (DANI-65816)
**Domain:** Hardware
**Status:** Decided, with open items blocking schematic capture
**Supersedes:** Tier definitions in the programming/debug section of the execution roadmap (tier numbering retained, transport revised)

---

## 1. Purpose

This note specifies the external debug and programming interface of the noVa64 machine: a chassis-mounted USB-C port backed by an on-board RP2040 acting as a CMSIS-DAP probe and USB-to-UART bridge for the RP2354B embedded controller (EC).

It defines the decision, the rejected alternatives and why they were rejected, the electrical interface, the power-domain arrangement, the firmware fork requirements, and the verification criteria. It is intended as a direct input to KiCad schematic capture.

---

## 2. Problem statement

The RP2354B EC has a single USB controller, and that controller is committed as a Full Speed **host** for the on-board USB2514B hub. A USB controller cannot operate as host and device simultaneously. Consequently the EC cannot present itself to a development PC as a programmable device.

BOOTSEL was previously removed as a recovery path because the USB-A receptacles source VBUS, and an A-to-A connection would place two 5 V supplies in opposition.

The result is that **without a second on-board device, no path exists from a development host to the EC**. The debug port is therefore not a convenience feature; it is the only bridge.

---

## 3. Options considered

| ID | Option | Outcome |
|----|---|---|
| A | Internal header, external Raspberry Pi Debug Probe | Rejected — requires opening the machine for every debug session |
| B | Chassis-mounted 3-pin connectors, external probe | Rejected — retains an external tool and a visible non-standard connector; the isolation problem is unchanged |
| C | FT2232H bridge (MPSSE SWD + UART) | **Rejected — see 3.1** |
| D | Purchased Debug Probe mounted inside the chassis | Rejected — the official probe uses micro-USB, defeating the port aesthetic; BOOTSEL sits under a snap-fit enclosure |
| E | **On-board RP2040 replicating the Debug Probe, USB-C device port** | **Selected** |

### 3.1 Why FT2232H was rejected

The FT2232H was initially attractive because it has no firmware that can be corrupted — it configures from EEPROM — which appeared to eliminate the "who programs the programmer" recursion.

It was rejected on evidence:

- SWD is not native to MPSSE. MPSSE is an SPI-like engine with separate data-in and data-out lines, whereas SWDIO is bidirectional and half-duplex. The standard workaround (OpenOCD `swd-resistor-hack.cfg`) connects TDI to SWDIO through a 220–470 Ω series resistor and TDO directly to SWDIO. This works in general, and OpenOCD ships `minimodule-swd.cfg` for FT2232H.
- The RP2350/RP2354 debug port is **SWD multidrop**, requiring the dormant-to-SWD sequence and TARGETSEL to select between cores. OpenOCD 0.12.0 release notes list SWD multidrop support for CMSIS-DAP specifically; per-driver mention implies per-driver work, and the `ftdi` driver is not named.
- Every documented working RP2350 flow found uses `interface/cmsis-dap.cfg` against the Raspberry Pi OpenOCD fork.
- A public report exists of FT2232H failing DAP init against RP2040 — which is not even multidrop — with the resistor hack correctly fitted, and no resolution in the thread.

The failure mode of being wrong is a fabricated PCB with a dead debug port and no alternative path to the EC. That is precisely the risk this port exists to eliminate, so the unproven transport was rejected in favour of the transport Raspberry Pi maintains.

### 3.2 Correction to the earlier "recursion" objection

An earlier concern held that an on-board RP2040 introduces a single point of failure, because its own firmware could be corrupted, cutting off all access to the machine.

This overstates the risk. **The RP2040 bootrom is mask ROM.** It cannot be erased, corrupted or overwritten. BOOTSEL plus USB device enumeration always works regardless of the state of the SPI flash. The recursion exists but has a hard floor, and that floor is more dependable than an FTDI part that may simply fail to enumerate a DAP.

### 3.3 Precedent

The approach is well precedented. `red-scorp/RP2040-DebugProbe` is a four-layer RP2040 board carrying all components required to function identically to the official Debug Probe, with a USB Type-C host connector, pin-compatible with the official probe and usable with the same picoprobe software. `picoLink` (MCU on Eclipse) is a second independent reimplementation.

The `debugprobe` firmware is open source. The hardware being replicated is essentially the RP2040 minimum reference design plus four series resistors and an input buffer arrangement. No proprietary content is involved.

---

## 4. Decision summary

| Item | Decision |
|---|---|
| Probe MCU | RP2040, QFN-56 |
| Probe flash | 2 MB QSPI (W25Q16-class) |
| Host connector | USB-C receptacle, device role, chassis-mounted |
| Probe power source | VBUS of the debug USB-C port |
| Target signals | SWCLK, SWDIO, UART TX, UART RX, RUN |
| Termination | 100 Ω source termination at both ends, per Raspberry Pi 3-pin Debug Connector Specification |
| TX contention mitigation | VBUS presence sensed by EC GPIO; EC holds UART TX Hi-Z when probe unpowered |
| Probe recovery | BOOTSEL button, chassis pinhole access |
| Firmware | Fork of `debugprobe`, built from source |
| QSPI tier-3 access | Test pads only, no probe connection — see 11.4 |

---

## 5. Architecture

### 5.1 Block arrangement

```
  Development host
        |
     USB 2.0 FS
        |
  [USB-C receptacle]  <-- chassis
        |  D+/D-, VBUS, CC1/CC2
        |
  [ESD array]
        |
  [RP2040 probe]  <-- 3V3_PROBE, from VBUS via LDO
        |
        |  SWCLK, SWDIO, UART TX/RX, RUN
        |  (100 R source termination both ends)
        |
  [RP2354B EC]  <-- 3V3_AON
```

The probe is electrically an island. It shares only GND with the rest of the machine, plus the five signal lines and the VBUS-sense divider.

### 5.2 Power domains

The probe is powered from the debug port's VBUS, supplied by the development host, through a local 3.3 V LDO designated **3V3_PROBE**.

This is deliberate. The scenario that justifies the port is "the machine will not start and I need to reach the EC". A probe dependent on a rail of the machine under repair cannot serve that purpose.

Resulting behaviour:

| Condition | 3V3_PROBE |
|---|---|
| Debug cable connected to host | Present |
| Debug cable connected, machine powered off | Present |
| Debug cable disconnected | Absent |
| Machine running or charging, no debug cable | Absent |

Note that the debug port's VBUS is unrelated to the PD charging port served by the CH224K. The two USB-C receptacles are independent.

RP2040 current draw is in the tens of milliamperes, well within the 500 mA a USB host guarantees before negotiation.

3V3_PROBE must **not** be tied, OR-ed or diode-coupled to 3V3_AON. Cross-domain current is bounded by the series termination described in 5.3 and the gating described in 5.4.

### 5.3 Signal interface and termination

The Raspberry Pi 3-pin Debug Connector Specification requires source termination resistors of 100 Ω at **both** ends of each link — at the host IC pins and at the target IC pins — placed very close to the IC pins so that the 200 Ω series combination only has to drive pin capacitance and the shortest possible trace capacitance. The resistors provide slew-rate limiting (benefiting signal integrity and EMC) together with short-circuit and ESD current limiting.

Although the connector and cable are eliminated by integration, **the termination is retained**. It costs four additional resistors and preserves the protective properties.

| Signal | Direction | Probe-side R | EC-side R |
|---|---|---|---|
| SWCLK | Probe → EC | 100 Ω | 100 Ω |
| SWDIO | Bidirectional | 100 Ω | 100 Ω |
| UART RX (EC input) | Probe → EC | 100 Ω | 100 Ω |
| UART TX (EC output) | EC → Probe | 100 Ω | 100 Ω |
| RUN | Probe → EC | 100 Ω | — |

All resistors 1 %, placed within a few millimetres of their respective IC pins.

The official probe routes the read side of SWDIO and of UART RX through input buffers, using separate RP2040 GPIO for drive and sense. This topology must be replicated; the buffer part and arrangement are to be taken from the published Raspberry Pi schematic (see 11.1).

### 5.4 UART TX contention and VBUS sensing

The normal operating state of the machine is **EC powered, probe unpowered**, and unlike a plug-in probe the traces are permanently connected.

The EC's UART TX idles high. With 3V3_PROBE absent, that pin drives approximately 3.3 V through 200 Ω into an RP2040 input whose supply rail is at zero. Current flows through the input clamp diode and attempts to raise 3V3_PROBE, potentially leaving the RP2040 in an indeterminate partially-powered state. At roughly 16 mA continuous this is a genuine backfeed condition, and here it is the normal case rather than an edge case.

SWCLK, SWDIO and RUN do not exhibit this problem: they are driven by the probe, and the EC only drives SWDIO during transactions that by definition occur with the probe alive.

**Mitigation.** A resistive divider from debug-port VBUS to an EC GPIO (`DBG_VBUS_SENSE`). The EC holds its UART TX pin in high-impedance input mode whenever the divider reads low, and configures it as UART TX only when a probe is detected.

This signal carries a second benefit: it informs the EC that a debugger is attached, which composes naturally with the existing `DEBUG_ENABLE` strap of the Debug Agent and permits automatic redirection of the kernel console.

Divider sized for 5 V input to a 3.3 V-tolerant GPIO with adequate noise margin; exact values to be fixed at schematic capture.

### 5.5 USB-C device port

- Receptacle wired for **device (UFP) role only**. USB 2.0 signalling; SuperSpeed pairs unused.
- **5.1 kΩ pull-downs on CC1 and CC2 to GND**, individually. Without these the port will not be recognised by a Type-C host.
- ESD protection array on D+/D− (USBLC6-2 class or equivalent). The port is externally exposed.
- VBUS is consumed only; the port never sources.

### 5.6 Probe recovery

BOOTSEL is implemented as a momentary switch pulling QSPI_SS low through 1 kΩ, sampled by the mask-ROM bootrom at reset. The 1 kΩ prevents contention with the flash chip select during normal operation.

The button is accessible through a **chassis pinhole**, in the manner of a router reset. This is one of the concrete advantages of integration over the purchased probe, whose BOOTSEL button sits under a snap-fit enclosure that must be pinched apart.

SWD test pads for the RP2040 itself are provided for probe-firmware development, where drag-and-drop UF2 cycles are inefficient compared to breakpoint debugging. These are pads, not a connector.

---

## 5.7 Net-level interconnection and domain isolation

### 5.7.1 Domain crossing inventory

Exactly **six** electrical paths cross between the probe domain (3V3_PROBE) and the machine domain (3V3_AON), plus the shared ground reference. Nothing else crosses. Any additional crossing introduced during capture is a design error and must be justified against this note.

| # | Net | Direction | Crossing type |
|---|-----|---|---|
| 1 | `DBG_SWCLK` | Probe → EC | Driven, series terminated |
| 2 | `DBG_SWDIO` | Bidirectional | Driven, series terminated |
| 3 | `DBG_UART_RX` | Probe → EC | Driven, series terminated |
| 4 | `DBG_UART_TX` | EC → Probe | Driven, series terminated, **software gated** |
| 5 | `EC_RUN_N` | Probe → EC | **Open-drain only** |
| 6 | `DBG_VBUS_SENSE` | Probe domain → EC | High-impedance divider |
| — | `GND` | — | Common reference, unsplit |

**Ground is deliberately common and must not be split.** All six signals reference GND; a split plane or ferrite between domains would create a return-path discontinuity, defeat the source termination, and worsen rather than improve isolation. "Isolation" in this note means *supply* isolation, not galvanic isolation. Single continuous ground pour under both domains.

**No supply rail crosses.** 3V3_PROBE and 3V3_AON are never tied, diode-OR-ed, or bridged by a zero-ohm option. Debug-port VBUS never reaches the machine domain except through the divider of net 6.

### 5.7.2 Pin assignment

RP2040 assignments follow the official Debug Probe map wherever a corresponding function exists, per section 6. Assignments outside that map are marked **[new]** and are chosen so that loading the stock official binary leaves them undriven and inert.

| Net | RP2040 pin | RP2354B pin | Note |
|-----|---|---|---|
| `DBG_SWCLK` | GPIO12 (out) | SWCLK (dedicated) | Official map |
| `DBG_SWDIO` | GPIO14 (drive) / GPIO13 (sense, buffered) | SWDIO (dedicated) | Official map; buffer per 11.1 |
| `DBG_UART_RX` | GPIO4 — UART1 TX | GPIO0 — UART0 TX *(proposed)* | Probe transmits into EC receiver |
| `DBG_UART_TX` | GPIO6 (direct) / GPIO5 (buffered, UART1 RX) | GPIO1 — UART0 RX *(proposed)* | Official map; see naming note below |
| `EC_RUN_N` | GPIO20 **[new]**, open-drain | RUN (dedicated) | Undriven under stock firmware |
| `DBG_VBUS_SENSE` | — | GPIO *TBD* | Divider from debug VBUS |
| Probe status LEDs | GPIO2, 7, 8, 15 | — | Official map |
| QSPI tier-3 access | *none — test pads only* | QSPI_SS, SCK, SD0–SD3 | Option (a) per 11.4; no RP2040 GPIO consumed |

SWCLK, SWDIO and RUN are dedicated pins on RP2350-family devices and are not subject to GPIO allocation. Only the UART pair and `DBG_VBUS_SENSE` consume EC GPIO budget.

**Naming convention.** Following the Raspberry Pi 3-pin Debug Connector Specification, `TX` and `RX` are named *from the target's perspective*. `DBG_UART_TX` is therefore an EC output and a probe input. The specification places the unidirectional SC (serial clock, driven into the target) on the same pin as UART RX because both travel in the same direction, so that mis-plugging a UART into a serial debug interface is safe.

### 5.7.3 Link topologies

Unidirectional probe-to-EC links (`DBG_SWCLK`, `DBG_UART_RX`):

```
   3V3_PROBE domain          |          3V3_AON domain
                             |
  RP2040                     |                    RP2354B
  GPIOnn ---[100R]-----------+-----------[100R]--- pin
            ^                |             ^
            within a few mm  |             within a few mm
            of RP2040 pin    |             of RP2354B pin
```

Bidirectional `DBG_SWDIO`:

```
  RP2040                                          RP2354B
  GPIO14 (drive) ---[100R]---+------[100R]------- SWDIO
                             |
  GPIO13 (sense) <--[buf]<---+
                    ^
                    input buffer, topology per 11.1
```

EC-to-probe `DBG_UART_TX`, the only line driven from the machine domain:

```
  RP2354B                                         RP2040
  GPIO1 ---[100R]---+------[100R]---+-----------> GPIO6 (direct)
     ^              |               |
     |              |               +--[buf]----> GPIO5 (UART1 RX)
     |
   Hi-Z unless DBG_VBUS_SENSE asserted
```

`EC_RUN_N`, open-drain:

```
  RP2040                                          RP2354B
  GPIO20 ---[100R]------------------------------- RUN
    |                                              |
  drives LOW or Hi-Z only                      internal pull-up
  never drives HIGH
```

`DBG_VBUS_SENSE`:

```
  VBUS (debug port, 5V) ---[R_top]---+--- EC GPIO
                                     |
                                  [R_bot]
                                     |
                                    GND
```

### 5.7.4 Open-drain requirement on RUN

`EC_RUN_N` **must** be driven open-drain: the probe asserts low or releases to high impedance, and never drives high. Two reasons:

1. The RP2354B RUN pin has an internal pull-up, so high impedance already means "not in reset". Driving high adds nothing.
2. Driving high would inject probe-domain current into an unpowered machine domain, which is precisely the failure mode this section exists to prevent.

This also yields a safe default: under the stock official firmware, GPIO20 is never configured, the RP2040 leaves it as an input at reset, RUN floats to its internal pull-up, and the EC runs normally.

### 5.7.5 Power-state behaviour

| State | 3V3_PROBE | 3V3_AON | Concern |
|---|---|---|---|
| S1 | Absent | Present | **Normal operating state.** EC could drive `DBG_UART_TX` into an unpowered probe — mitigated by gating (5.4) |
| S2 | Present | Present | Normal debug session. No concern |
| S3 | Present | Absent | Rescue with no battery. Probe could drive four lines into an unpowered EC |
| S4 | Absent | Absent | Machine fully unpowered. No concern |

**S1** is the state the machine spends its life in and is fully addressed by `DBG_VBUS_SENSE` gating. `DBG_SWDIO` is not a concern here: the EC only drives it during transactions, which by definition require a live probe. Its idle state is governed by the RP2354B internal pull-up, giving a current on the order of tens of microamperes through the 200 Ω series path — negligible, but the presence and value of that pull-up is to be confirmed against the datasheet.

**S3** occurs only with the battery absent or fully depleted, since 3V3_AON is an always-on rail. It is nonetheless real during early bring-up. Mitigations: RP2040 GPIOs default to inputs at reset, so all target-facing lines are high impedance until firmware configures them; `EC_RUN_N` is open-drain and cannot source; and the probe firmware shall not configure `DBG_SWCLK` or `DBG_UART_RX` as outputs until a host session is established.

### 5.7.6 Backfeed current budget

Worst case per line, driver at 3.3 V into a clamp diode across 200 Ω of series termination:

| Assumption | Current |
|---|---|
| Ignoring clamp forward drop | 16.5 mA |
| With 0.6 V clamp drop | 13.5 mA |

Aggregate for state S3 with four lines simultaneously driven: approximately 54 mA into 3V3_AON. This is not sufficient to bring up the rail against the load of the RP2354B, CH224K, BQ25896 and MAX17048, but it is sufficient to place devices in an indeterminate partially-biased condition, which is why 5.7.5 requires firmware-side high impedance rather than relying on the current limit alone.

Both figures must be checked against the RP2354B absolute maximum clamp current — see open item 11.2. If margin is inadequate, termination rises to 220 Ω or 330 Ω per side and the slew-rate consequences are re-evaluated against maximum SWD clock rate.

### 5.7.7 VBUS sense divider sizing

The divider is itself a domain crossing and must be high impedance for that reason, not merely for power economy. With the probe connected and the machine unpowered, divider current flows into the EC GPIO clamp.

Design targets:

- Total series resistance ≥ 150 kΩ, giving well under 50 µA in the worst case
- Output between 1.5 V and 3.0 V at VBUS = 5.0 V
- Output below 0.4 V at VBUS = 0 V, guaranteed by the lower leg to GND
- Optional 100 nF to GND at the GPIO for noise immunity on hot-plug

A worked candidate is 100 kΩ / 56 kΩ, yielding approximately 1.79 V at 5.0 V VBUS and 32 µA. Final values fixed at capture against the EC input threshold.

### 5.7.8 Layout constraints

- All eight signal-side 100 Ω resistors within 3 mm of their respective IC pins, per the Raspberry Pi specification requirement that the series combination drive only pin capacitance and the shortest possible trace capacitance.
- Continuous ground reference under the entire six-net crossing region. No plane split, no moat, no stitching ferrite.
- `DBG_SWCLK` and `DBG_SWDIO` routed as a loosely coupled pair, matched to within 5 mm, referenced to the same plane for their full length.
- 3V3_PROBE pour confined to the probe area, with a single clearly identifiable boundary. Visual separability of the two pours on the plot is a review criterion.
- Debug USB-C differential pair length-matched, 90 Ω differential, kept clear of the probe's own QSPI flash bus.

---

## 6. Firmware

The probe runs a **fork of `debugprobe`, built from source**. A fork is required regardless, because the following capabilities are not present in the stock binary:

- `RUN` assertion and de-assertion against the RP2354B — needed for reliable attach, and to hold the EC in reset while tier-3 test pads are accessed by external equipment
- Status LED behaviour appropriate to an integrated part
- Status reporting of `DBG_VBUS_SENSE` state, where useful

Where it costs nothing to do so, the RP2040 GPIO assignment should follow the official Debug Probe pinout. This preserves the ability to load the stock official binary as a diagnostic, allowing custom firmware to be eliminated as a suspect during bring-up.

Host-side toolchain: Raspberry Pi OpenOCD fork with `interface/cmsis-dap.cfg` and `target/rp2350.cfg`. The minimum acceptable OpenOCD revision must be recorded once verified against hardware.

---

## 7. Revised programming and debug tiers

The tier numbering of the roadmap is retained. Transports and relative priority are revised.

| Tier | Mechanism | Depends on | Can write EC flash | Status |
|---|---|---|---|---|
| 1 | SWD via integrated probe | EC core reachable, debug not OTP-locked | Yes | **Primary** |
| 2 | Bootrom UART boot on QSPI SD2/SD3, 1 Mbaud | Bootrom, OTP enable bit, RAM flash-writer stub | Not directly — downloads to SRAM only | Deprioritised |
| 3 | Direct SPI to EC flash, RUN held low | Nothing | Yes | **Diagnostic** — conditional, see 7.1.1 |

### 7.1 Effect of in-package flash on tier 3

The RP2354 datasheet states that the six dedicated QSPI pads on the RP2350 die (CSn, SCK, SD0–SD3) connect to **both** the internal flash die and the external package pins, making them behave similarly to flashless RP2350 devices.

Two consequences:

1. **There will never be an external flash chip on the RP2354B.** Any reference to a discrete W25Q16JV as the EC's boot flash is obsolete and must be removed from other project documents.
2. **Tier 3 remains electrically possible.** The flash is internal but externally addressable. With RUN held low the core is in reset and its QSPI pads are high-impedance, allowing an external master to treat the internal die as an ordinary SPI flash: JEDEC ID, erase, page program, read. This requires no bootrom, no firmware, no OTP configuration and no core execution.

#### 7.1.1 Tier 3 is a diagnostic, not a recovery path

An earlier draft of this note elevated tier 3 to primary recovery mechanism. That was written before the capabilities of tier 1 were fully characterised, and it is **withdrawn**.

Tier 1 recovers the EC when the flash is blank, when the flash is corrupt, when the machine has no power of its own, and — via the RP2350 rescue DP — when the device is resetting itself in a loop. It leaves tier 3 with very little recovery territory of its own.

What remains genuinely valuable:

1. **Bring-up diagnostic (the principal justification).** At E0, with a freshly assembled board, reading the flash JEDEC ID with RUN held low simultaneously confirms supply integrity, QFN-80 solder joints, and QSPI pad continuity — and does so without depending on probe firmware, OpenOCD, or multidrop configuration. When SWD fails to attach, this test separates "assembly fault" from "software fault" in one step. That diagnostic value is not available from any other tier.
2. **Physically damaged SWD lines.** ESD, a lifted trace, a solder bridge under the package. Low probability, and in that situation rework is already under way.
3. **Core-independent flash read or erase.** Byte-level verification, or returning the device to a fully blank state without cooperation from anything.

Tier 3 is therefore retained as a **bring-up diagnostic aid**, and its inclusion is conditional on the layout outcome described in 11.4. Recovery is the responsibility of tier 1.

### 7.2 Why tier 2 was deprioritised

Tier 2 downloads to SRAM and executes from SRAM; the bootrom does not write flash. Reflashing therefore requires transmitting a RAM-resident flash-writer stub as a real software deliverable.

It is squeezed between two stronger neighbours. SWD works against a blank flash and the RP2350 rescue DP recovers a self-resetting device; tier 3 requires no chip cooperation at all. Tier 2 only contributes in the narrow window where SWD is physically broken but the bootrom is reachable.

The pads cost nothing — SD2 and SD3 are a subset of the six brought out for tier 3 — so the hardware is retained. **The RAM flash-writer stub is removed from the critical path before E0.**

### 7.3 OTP policy

The OTP bits that disable debug must **never** be burned on this design. They are the only mechanism capable of closing tier 1 and tier 3 simultaneously.

---

## 8. Chassis requirements

- Two USB-C receptacles with dissimilar functions (PD charging input via CH224K; debug device port). They must be **visually differentiated** — icon, colour or recess — because inserting the charger into the debug port is the obvious user error.
- Pinhole aligned to the probe BOOTSEL button.
- Debug USB-C positioned for a board-edge receptacle; no internal adapter cable.

---

## 9. Bill of materials delta

| Item | Qty | Note |
|---|-----|---|
| RP2040 QFN-56 | 1 | |
| QSPI flash 2 MB | 1 | W25Q16-class, probe's own boot flash |
| Crystal 12 MHz + load caps | 1 | |
| LDO 3.3 V from VBUS | 1 | ≥150 mA, AP2112K-class |
| USB-C receptacle, 16-pin UFP | 1 | |
| CC pull-down 5.1 kΩ | 2 | |
| ESD array D+/D− | 1 | |
| Series termination 100 Ω 1 % | 9 | 4 probe-side, 4 EC-side, 1 on RUN |
| BOOTSEL switch + 1 kΩ | 1 | |
| VBUS sense divider | 2 | |
| Status LEDs + resistors | 2–5 | |
| Decoupling | — | Per RP2040 hardware design guide |

---

## 10. Verification and exit criteria

Staged, each stage independently gated.

| ID | Test | Pass criterion |
|----|---|---|
| V1 | Probe standalone enumeration, EC held in reset | Host enumerates CMSIS-DAPv2 and CDC ACM interfaces |
| V2 | OpenOCD attach to RP2354B | Valid DPIDR read; both cores examined without error |
| V3 | Flash and run a minimal binary on EC via SWD | Binary executes; observable output |
| V4 | UART console | Bidirectional traffic between EC and host terminal |
| V5 | Backfeed measurement, state S1 (probe unpowered, EC running) | 3V3_PROBE below 0.3 V; current into probe domain below stated clamp limit |
| V5b | Backfeed measurement, state S3 (probe powered, battery removed) | 3V3_AON below 0.3 V with probe idle; all target-facing probe pins verified Hi-Z before session start |
| V6 | VBUS sense and TX gating | EC TX confirmed Hi-Z with probe absent; UART functional within 100 ms of probe insertion |
| V7 | RUN control | EC held in reset and released under probe command |
| V8 | Probe BOOTSEL recovery | Host mounts `RPI-RP2`; UF2 load restores firmware |
| V9 | Tier 3 bring-up diagnostic | JEDEC ID read from EC internal flash via test pads, RUN held low, using external SPI equipment |
| V10 | XIP integrity with test-pad stubs present | EC executes from flash at maximum clock with no errors over a sustained run |

**Exit criterion for schematic capture:** V1–V8 defined and all items in section 11 closed.

---

## 11. Open items

### 11.1 Official schematic retrieval — **blocks schematic capture**
Raspberry Pi publishes the Debug Probe schematic and mechanical drawing. The input buffer topology on the SWDIO and UART RX read paths must be taken from it: part number, supply, and behaviour when the target is unpowered. Zephyr's board documentation confirms separate GPIO for direct and buffered paths but does not identify the device.

### 11.2 RP2354B clamp diode limit — **blocks schematic capture**
The calculated worst-case backfeed of approximately 16 mA per line through 200 Ω must be checked against the RP2354B absolute maximum clamp current. If insufficient margin exists, termination values increase and slew-rate implications must be re-examined.

### 11.3 Tier 2 OTP gate
The RP2350 bootrom UART boot path is believed to require an OTP enable bit rather than being active by default. If confirmed, tier 2 is not a rescue mechanism but something that must be provisioned in advance, and this must be reflected in the manufacturing flow. To be verified against the datasheet.

### 11.4 QSPI access scope — **decided, conditional on layout**

Bringing the six QSPI pads out creates six transmission-line stubs on a bus that runs XIP against the in-package flash at tens of megahertz. Unlike the previous external-flash arrangement, these stubs serve no functional purpose during normal operation and are pure parasitic load.

Options considered:

| | Arrangement | Stub length | Outcome |
|---|---|---|---|
| (a) | Test pads immediately adjacent to the package; pogo pin or clip access; no probe connection | millimetres | **Selected** |
| (b) | As (a), plus probe connection through 22–33 Ω series resistors | tens of mm | Rejected — the probe connection buys convenience for a test run twice in the project's life, at the cost of permanent stubs and six RP2040 GPIO |
| (c) | No QSPI access; tier 3 removed | none | Fallback — see abandonment condition |

**Decision: option (a)**, justified by the bring-up diagnostic case of 7.1.1 rather than by recovery. **The previously specified 8-pin `J-QSPI` header is withdrawn** — this is a test-pad footprint, not a connector, and no cable or connector shall be fitted to these nets.

**Abandonment condition.** If during layout the six pads cannot be placed immediately adjacent to the package without either (i) compromising the routing of the QSPI bus itself, or (ii) extending any stub beyond a few millimetres, then **option (c) shall be adopted without further review**. A clean XIP bus is worth more than a diagnostic that may be exercised twice in the lifetime of the project. This condition is delegated to the layout engineer and does not require reopening this note.

Consequences of adopting (c): verification items V9 and V10 are removed; the QSPI row of the pin assignment table in 5.7.2 is deleted; tier 3 disappears from section 7 and the tier table reduces to two entries.

### 11.5 DEBUG_ENABLE interaction
`DBG_VBUS_SENSE` and the Debug Agent's `DEBUG_ENABLE` strap overlap in purpose. Their relationship must be defined: whether probe presence gates Debug Agent availability, whether either can disable the other, and what the production posture is.

### 11.6 RP2354B SWDIO idle bias — **blocks schematic capture**
Section 5.7.5 assumes the RP2354B SWDIO pin carries an internal pull-up, making its idle backfeed contribution in state S1 negligible. If instead it floats, or carries a pull-down, the analysis changes and `DBG_SWDIO` may require the same gating treatment as `DBG_UART_TX`. To be confirmed against the datasheet.

### 11.7 EC UART pin allocation
`DBG_UART_RX` and `DBG_UART_TX` are proposed on GPIO0/GPIO1 (UART0 default). `DBG_VBUS_SENSE` is unallocated. Both must be reconciled against the full EC pin budget — battery I2C, SD mux, Helium SPI, regulator enables, USB host, keyboard matrix — before capture.

### 11.8 Probe MCU alternative
RP2354A would consolidate the BOM by removing the external flash. Deferred: `debugprobe` firmware support for RP2350 as *host* is unverified, and the proven path was selected deliberately in section 3. Revisit only if BOM pressure justifies the verification effort.

---

## 12. References

- Raspberry Pi 3-pin Debug Connector Specification, RP-003139-SP
- Raspberry Pi Debug Probe documentation and product brief (February 2023)
- Zephyr Project, `rpi_debug_probe` board documentation — GPIO mapping and buffer paths
- RP2350 datasheet, QSPI pad description for RP2354 variants
- OpenOCD 0.12.0 release notes — SWD multidrop support
- OpenOCD `minimodule-swd.cfg`, `swd-resistor-hack.cfg` — FTDI SWD reference (rejected path)
- `red-scorp/RP2040-DebugProbe` — integration precedent
- `raspberrypi/debugprobe` — firmware source

---

## 13. Revision history

| Rev | Date | Change |
|-----|---|---|
| 001 | 2026-09-03 | Initial issue |
| 001a | 2026-09-03 | Added §5.7 net-level interconnection and domain isolation; open-drain requirement on RUN; power-state matrix S1–S4; open items 11.6–11.7. Tier 3 reframed from recovery mechanism to bring-up diagnostic (§7.1.1); 11.4 closed on option (a) with an explicit abandonment condition |

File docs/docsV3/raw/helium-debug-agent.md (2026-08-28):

# Helium Debug Agent — Register Map & Console Protocol

**Project:** noVa64
**Subsystem:** FPGA-A ("Helium") debug agent + RP2040 serial monitor
**Document status:** Design specification, pre-schematic
**Date:** 2026-08-14

---

## 1. Purpose and scope

This document specifies the **Debug Agent**, a hardware block inside Helium
(FPGA-A) that performs memory and bus accesses on behalf of an external
controller, and the **serial console** running on the RP2040 that drives it.

The goal is to have, from the earliest bring-up stage, a way to:

- read and write any location in physical memory (SRAM and SDRAM),
- read and write through the MMU translation path once it exists,
- generate real bus cycles visible to other devices on the CPU bus,
- halt, single-step and trace the W65C816S,
- do all of the above from a terminal over USB-CDC or a physical UART.

This is instrumentation, not a product feature. It exists to make the board
debuggable. It is expected to remain in the design permanently, gated off
rather than removed.

### 1.1 Terminology used in this document

Terms are defined at first use. A term is never used before it is defined.

- **Helium** — FPGA-A. Owns the MMU, the cache controller, the SRAM and SDRAM
  controllers, the bus arbiter, and the system peripherals.
- **Debug Agent (DA)** — the block specified here. A hardware requester inside
  Helium that issues memory and bus transactions on command.
- **Console** — firmware on the RP2040 that presents a text monitor to the user
  and translates typed commands into Debug Agent register operations.
- **Physical address** — a 27-bit address that identifies a location in the
  system's physical memory map, with no address translation applied.
- **Virtual address** — a 24-bit address as seen by a process, which must be
  translated by the MMU (using the process's ASID and page tables) before it
  identifies a physical location.
- **ASID** — Address Space Identifier. A small integer that names which
  process's translation context the MMU should use.
- **Internal access** — a transaction that is satisfied entirely inside Helium
  (SRAM, SDRAM, or Helium's own registers). No signal appears on the CPU bus.
- **External cycle** — a transaction in which Helium drives the CPU bus pins
  (address, data, control) so that devices outside Helium observe a bus cycle
  indistinguishable from one issued by the W65C816S.
- **PHI2 stall** — the existing mechanism by which Helium freezes the CPU clock
  to steal bus time. The W65C816S is fully static; holding PHI2 is safe and is
  already used for bounded-time cache fills.
- **BE** — Bus Enable, an input to the W65C816S. When low, the CPU tristates its
  address, data and RWB drivers, releasing the bus.

---

## 2. Architectural decisions

### 2.1 The RP2040 is not a bus master

**Decision:** the RP2040 never drives the system bus. It sends commands to the
Debug Agent, which performs the access.

**Rationale:**

1. **Pin budget.** Direct mastering would require ~24 address lines, 16 data
   lines and control — well beyond what remains after the RP2040's committed
   functions (FPGA configuration SPI, microSD, PIO-USB HID, ANX6345 I²C, power
   sequencing, resets).
2. **Reuse.** Helium already contains the SRAM controller, the SDRAM controller
   with refresh, the cache controller, and the arbiter. A second, independent
   path to memory would duplicate all of it and would be a second source of
   truth about memory state.
3. **Coherence.** An external master bypassing the cache controller can read
   stale data whenever a dirty line is resident in the SRAM cache. As a
   requester inside Helium, the Debug Agent goes through the same path as
   everyone else and is coherent by construction.

**Consequence:** the Debug Agent is architecturally a peer of the CPU port and
the FPGA-B port in the existing arbiter. It is not a special case.

### 2.2 Helium owns BE

**Decision:** the `BE` pin of the W65C816S is driven by Helium, not by an RP2040
GPIO.

**Rationale:** taking the bus requires two things to happen in a defined order:
the CPU must release its drivers, and Helium must begin driving. If `BE` is
controlled across the SPI link, that ordering becomes a race across a clock
domain crossing with millisecond-scale latency. With `BE` under Helium's
control, the handoff is a synchronous state transition.

**Schematic impact — must be resolved before capture:**

- `BE` routes from Helium to the CPU socket.
- Helium's CPU-side address and data pins must be bidirectional (`inout`), not
  input-only. This affects I/O bank planning and the pin assignment sheet.

### 2.3 The Debug Agent register file is SPI-only

**Decision:** the Debug Agent's registers are reachable only over the RP2040
link. They are **not** exposed in bank `$FF` or anywhere else in the CPU's
address space.

**Rationale:** the Debug Agent is unconditionally privileged — it can write bank
`$FF`, bypass permission checks, and halt the CPU. Exposing it to software would
make the entire protection model depend on kernel correctness. Keeping the
control path physically separate means no amount of software failure can reach
it, and the console remains usable precisely when software has failed, which is
when it is needed.

### 2.4 Two orthogonal access axes

Every Debug Agent memory transaction is characterised by two independent
choices.

**Address space:**

| Mode | Address | Path | Available from |
|---|---|---|---|
| Physical | 27-bit, raw | Straight to cache/memory controllers | E1 |
| Virtual | 24-bit + ASID | Through MMU translation, page-table walk | E4 |

Physical mode is what is needed while the MMU is itself under test. Virtual mode
exists to inspect what the kernel believes it is looking at.

**Transaction scope:**

| Mode | Reaches | Visible to FPGA-B / external devices |
|---|---|---|
| Internal | SRAM, SDRAM, Helium registers | No |
| External cycle | Everything the CPU can reach | Yes |

External cycles are required to touch anything decoded outside Helium — notably
the VRAM aperture at bank `$FE`, which FPGA-B services by watching the CPU bus
directly.

---

## 3. Physical interface

### 3.1 Link

SPI, RP2040 as controller, Helium as peripheral. Mode 0 (CPOL=0, CPHA=0). Target
clock 16 MHz initially; the limit is the synchroniser depth on Helium's side, not
the link.

The Debug Agent uses a **dedicated chip select**, separate from the one used for
FPGA configuration. Sharing the configuration SPI bus data lines is acceptable;
sharing the chip select is not, because the configuration path must remain
functional when the Debug Agent is in an unknown state.

| Signal | Direction | Notes |
|---|---|---|
| `DBG_SCK` | RP2040 → Helium | Shared with config SPI |
| `DBG_MOSI` | RP2040 → Helium | Shared with config SPI |
| `DBG_MISO` | Helium → RP2040 | Shared with config SPI |
| `DBG_CSN` | RP2040 → Helium | **Dedicated**, active low |
| `DBG_IRQN` | Helium → RP2040 | Optional; asserts on trace trigger or CPU halt |
| `DEBUG_ENABLE` | Strap/jumper | See §9 |

### 3.2 Frame format

Every transaction begins with a one-byte header:

```
bit 7    : 0 = write, 1 = read
bits 6:0 : register address (0x00 – 0x7F)
```

Followed by one or more data bytes. For registers wider than 8 bits, bytes are
transferred **least-significant first**.

`DBG_CSN` must be deasserted between frames. A frame is committed on the rising
edge of `DBG_CSN`; a truncated frame is discarded and sets `ERR_FRAME`.

### 3.3 Burst frames

Two registers support unbounded burst transfer while `DBG_CSN` remains asserted:
`DBG_FIFO` (§4.9) and `TRC_FIFO` (§7.3). This exists so that dumping a kilobyte
of memory or a full trace buffer does not cost one frame per byte.

---

## 4. Register map

All registers reset to zero unless stated. Reserved bits read as zero and must
be written as zero.

### 4.0 Summary

| Addr | Name | Access | Width | Purpose |
|---|---|---|---|---|
| 0x00 | `DBG_ID` | RO | 16 | Magic + version |
| 0x01 | `DBG_CTRL` | RW | 8 | Mode flags |
| 0x02 | `DBG_STATUS` | RO | 8 | Busy / ready / error |
| 0x03 | `DBG_ERR` | RO/W1C | 8 | Error code, write-1-to-clear |
| 0x04 | `DBG_ADDR` | RW | 32 | Address (27 physical / 24 virtual) |
| 0x08 | `DBG_DATA` | RW | 16 | Data port |
| 0x0A | `DBG_WIDTH` | RW | 8 | Access width / byte enables |
| 0x0B | `DBG_ASID` | RW | 16 | ASID for virtual-mode access |
| 0x0C | `DBG_CMD` | WO | 8 | Command trigger |
| 0x0D | `DBG_COUNT` | RW | 16 | Burst length in elements |
| 0x10 | `CPU_CTRL` | RW | 8 | Reset / halt / step |
| 0x11 | `CPU_STATUS` | RO | 8 | CPU state |
| 0x12 | `CPU_CYCLES` | RO | 32 | Free-running bus cycle counter |
| 0x18 | `TRC_CTRL` | RW | 8 | Trace enable / mode |
| 0x19 | `TRC_STATUS` | RO | 8 | Trace state, fill level |
| 0x1A | `TRC_TRIG_ADDR` | RW | 32 | Trigger address |
| 0x1E | `TRC_TRIG_MASK` | RW | 32 | Trigger don't-care mask |
| 0x1F | `TRC_FIFO` | RO | burst | Trace record readout |
| 0x20 | `DBG_FIFO` | RW | burst | Bulk data port |
| 0x30 | `TLB_INDEX` | RW | 16 | TLB entry selector |
| 0x31 | `TLB_ENTRY` | RO | 64 | TLB entry readout |
| 0x38 | `MMU_MIRROR` | RO | 8 | Read-only view of MMU status |

### 4.1 `DBG_ID` (0x00, RO, 16-bit)

Reads `0x6516`. Byte 0 is `0x16`, byte 1 is `0x65`.

Purpose: the console reads this first. A correct value proves the SPI link,
Helium's configuration, and the clock are all working, before anything else is
attempted. A read of `0x0000` or `0xFFFF` means the bitstream did not load.

Bits 15:8 of a second read (register 0x00 read twice in one frame) return the
gateware build revision. Bump it on every synthesis.

### 4.2 `DBG_CTRL` (0x01, RW, 8-bit)

| Bit | Name | Meaning |
|---|---|---|
| 0 | `ENABLE` | Master enable for the Debug Agent |
| 1 | `VIRT` | 0 = physical address space, 1 = virtual |
| 2 | `EXTCYC` | 0 = internal access, 1 = generate external bus cycle |
| 3 | `AUTOINC` | Advance `DBG_ADDR` by the access width after each access |
| 4 | `NOCACHE` | Bypass the SRAM cache (see §6 — hazardous) |
| 5 | `STALL` | 0 = cycle-steal when possible, 1 = always stall PHI2 |
| 7:6 | reserved | |

`ENABLE` gates all command execution. It is cleared by reset and by
`DEBUG_ENABLE` being deasserted.

### 4.3 `DBG_STATUS` (0x02, RO, 8-bit)

| Bit | Name | Meaning |
|---|---|---|
| 0 | `BUSY` | A command is in progress |
| 1 | `DONE` | Last command completed successfully |
| 2 | `ERROR` | Last command failed; see `DBG_ERR` |
| 3 | `FIFO_EMPTY` | Data FIFO empty |
| 4 | `FIFO_FULL` | Data FIFO full |
| 5 | `CPU_HALTED` | CPU is currently halted |
| 6 | `TRC_TRIGD` | Trace trigger has fired |
| 7 | `DBG_READY` | Agent idle and accepting commands |

The console polls `BUSY`. It must never assume a command completes within the
SPI frame that issued it: an SDRAM access with a page miss and an intervening
refresh can take considerably longer than a single-cycle SRAM hit.

### 4.4 `DBG_ERR` (0x03, RO / write-1-to-clear, 8-bit)

| Bit | Name | Cause |
|---|---|---|
| 0 | `ERR_TIMEOUT` | Watchdog expired; memory did not respond |
| 1 | `ERR_UNMAPPED` | Virtual mode: no valid PTE for the address |
| 2 | `ERR_PERM` | Virtual mode: PTE permissions forbid the access |
| 3 | `ERR_ARB` | Arbiter denied the request past its deadline |
| 4 | `ERR_CMD` | Unrecognised or illegal command encoding |
| 5 | `ERR_STATE` | Command requires a state the agent is not in |
| 6 | `ERR_FRAME` | Malformed or truncated SPI frame |
| 7 | `ERR_ALIGN` | Address not aligned for the requested width |

The agent latches the **first** error and refuses further commands until
`DBG_ERR` is cleared. This prevents a scripted burst from silently producing a
page of garbage after the first failure.

### 4.5 `DBG_ADDR` (0x04, RW, 32-bit)

Physical mode: bits 26:0 are the physical address; bits 31:27 must be zero.

Virtual mode: bits 23:0 are the virtual address; bits 31:24 must be zero. The
ASID comes from `DBG_ASID`.

With `AUTOINC` set, the register advances by the access width after each
completed access. It does not advance on error.

### 4.6 `DBG_DATA` (0x08, RW, 16-bit)

Write data source for `CMD_WRITE`; read data destination for `CMD_READ`. For
8-bit accesses only the byte selected by `DBG_WIDTH` is meaningful.

### 4.7 `DBG_WIDTH` (0x0A, RW, 8-bit)

| Value | Meaning |
|---|---|
| 0x01 | 8-bit access, low byte |
| 0x02 | 8-bit access, high byte |
| 0x03 | 16-bit access |

The system SRAM (IS61WV102416) is a ×16 device with separate upper and lower
byte enables. Byte-granular writes require the correct `UB#`/`LB#` assertion.
Getting this wrong produces a very specific and very confusing failure — byte
writes appear to work but corrupt the adjacent byte — and it is worth testing
explicitly in the E1 memory test rather than discovering it later through a
kernel bug.

### 4.8 `DBG_CMD` (0x0C, WO, 8-bit)

Writing this register triggers execution. The write is rejected with `ERR_STATE`
if `BUSY` is set.

| Code | Name | Action |
|---|---|---|
| 0x00 | `CMD_NOP` | No operation; clears `DONE` |
| 0x01 | `CMD_READ` | Read one element into `DBG_DATA` |
| 0x02 | `CMD_WRITE` | Write `DBG_DATA` to memory |
| 0x03 | `CMD_READ_BURST` | Read `DBG_COUNT` elements into the FIFO |
| 0x04 | `CMD_WRITE_BURST` | Write `DBG_COUNT` elements from the FIFO |
| 0x05 | `CMD_FILL` | Write `DBG_DATA` to `DBG_COUNT` consecutive elements |
| 0x10 | `CMD_CACHE_FLUSH` | Flush the entire SRAM cache to SDRAM |
| 0x11 | `CMD_CACHE_INVAL` | Invalidate the cache without writeback |
| 0x12 | `CMD_CACHE_FLUSH_LINE` | Flush the line containing `DBG_ADDR` |
| 0x20 | `CMD_TLB_PROBE` | Translate `DBG_ADDR`; result in `TLB_ENTRY` |
| 0x21 | `CMD_TLB_FLUSH` | Invalidate the entire TLB |
| 0x22 | `CMD_PTWALK` | Full page-table walk, bypassing the TLB |
| 0x30 | `CMD_ABORT` | Cancel the in-flight command |

`CMD_CACHE_INVAL` discards dirty data. It is destructive and is provided only
for recovering a wedged cache during gateware bring-up.

`CMD_PTWALK` differs from `CMD_TLB_PROBE` in that it always reads the page table
from memory. Comparing the two is the direct way to detect a stale TLB entry,
which is the failure mode the `CTX_SET_PTBASE` / `CTX_SET_ASID` ordering
invariant exists to prevent.

### 4.9 `DBG_FIFO` (0x20, RW, burst)

A 512-byte FIFO between the SPI link and the memory path. Read frames drain it;
write frames fill it. Depth is chosen so that a burst can stay ahead of a 16 MHz
SPI link without stalling on SDRAM page misses.

The console must respect `FIFO_FULL` on writes and `FIFO_EMPTY` on reads. The
agent does not stretch the SPI clock.

---

## 5. Access state machine

```
IDLE
 │  write DBG_CMD
 ▼
DECODE ──────── illegal ──────► ERROR
 │
 ├─ VIRT ─► TRANSLATE ─ fault ─► ERROR
 │              │
 │◄─────────────┘
 ▼
ARBITRATE ──── deadline ──────► ERROR
 │  grant
 ▼
 ├─ EXTCYC=0 ─► MEM_ACCESS ─┐
 │                          │
 └─ EXTCYC=1 ─► BUS_TAKE    │
                 │          │
                 ▼          │
              BUS_CYCLE     │
                 │          │
                 ▼          │
              BUS_RELEASE ──┤
                            ▼
                        COMPLETE ──► IDLE
```

**BUS_TAKE / BUS_RELEASE** is the only sequence that touches the CPU. It is:

1. Request the bus from the arbiter.
2. Assert PHI2 stall; wait for the current CPU cycle to reach a clean boundary.
3. Assert `BE` low. Wait the CPU's tristate turnaround time (a fixed number of
   Helium clocks, derived from the W65C816S datasheet at 3.3 V).
4. Drive address, data and control. Run the cycle.
5. Release the drivers, wait turnaround, deassert `BE`.
6. Release PHI2. Release the arbiter.

Step 6 must satisfy the minimum PHI2 pulse width on restart. The existing
glitch-free PHI2 gating logic is reused unchanged; the Debug Agent is simply
another client of it.

---

## 6. Coherence rules

**Rule 1 — the Debug Agent goes through the cache controller.**

A physical read of an SDRAM address whose line is dirty in the SRAM cache must
return the cached value, not the SDRAM value. The Debug Agent therefore issues
its accesses to the cache controller, exactly as the CPU port does.

This is not negotiable. A debug tool that reports memory contents which differ
from what the CPU sees is worse than no debug tool, because it produces
confident wrong answers during exactly the sessions where the engineer has least
ability to detect them.

**Rule 2 — `NOCACHE` is for gateware bring-up only.**

`DBG_CTRL.NOCACHE` routes the access directly to the SDRAM controller. Its only
legitimate use is validating the cache controller itself: write through the
cache, flush, read with `NOCACHE`, compare. The console prints a warning banner
whenever `NOCACHE` is set.

**Rule 3 — external cycles are coherent by construction.**

An external cycle is decoded by exactly the same logic as a CPU cycle. If the
address falls in cacheable space, it goes through the cache. If it falls in the
`$FE` VRAM aperture or bank `$FF`, it does not. No special-casing.

**Rule 4 — writes to page tables require a TLB flush.**

The Debug Agent will happily write a PTE and leave the TLB holding the old
translation. It does not auto-invalidate. The console's `pt write` command
issues `CMD_TLB_FLUSH` afterwards; direct register users must do so themselves.

---

## 7. CPU control and trace

### 7.1 `CPU_CTRL` (0x10, RW, 8-bit)

| Bit | Name | Meaning |
|---|---|---|
| 0 | `RESET` | Hold the W65C816S in reset |
| 1 | `HALT` | Request halt at the next clean bus-cycle boundary |
| 2 | `STEP` | Advance exactly one bus cycle (self-clearing) |
| 3 | `STEP_INSN` | Advance to the next opcode fetch (`VPA & VDA`) |
| 4 | `IRQ_MASK` | Hold IRQB deasserted while halted |
| 5 | `NMI_MASK` | Hold NMIB deasserted while halted |

Halting is implemented as an indefinite PHI2 stall. The W65C816S is fully static
and can be held in this state indefinitely.

Interrupt masking while halted matters: a system timer that keeps running while
the CPU is stopped will present a large backlog of pending interrupts on
resume, which looks like a kernel bug and is not.

### 7.2 What cannot be read

**The Debug Agent cannot read the W65C816S's internal registers.** The part has
no scan chain, no debug port, and no mechanism for external register readout.
A, X, Y, S, DP, DBR, PBR and P are not observable from outside.

Two workarounds, in order of preference:

1. **Inferred from trace.** A halt at an instruction boundary plus a trace
   buffer containing the preceding cycles lets the console reconstruct PC and,
   with disassembly, much of the register state. This is passive and always
   available.
2. **Debug stub.** A short routine in bank `$00` that pushes all registers to a
   known location and spins. The Debug Agent forces entry by driving an
   instruction onto the data bus during a fetch cycle, or the kernel enters it
   from a breakpoint trap. This is intrusive and perturbs the state being
   inspected, but is the only way to get authoritative register values.

The console exposes option 1 as `reg` and option 2 as `reg -f` (force). The
distinction must be visible to the user; silently perturbing state during
inspection is unacceptable in a debugger.

### 7.3 Trace buffer

A ring buffer in EBR capturing, per bus cycle: address (24), data (8), `RWB`,
`VPA`, `VDA`, `VPB`, `MLB`, `E`, and a cycle-counter delta. Approximately 48
bits per record.

Depth is a synthesis parameter. 1024 records is a reasonable starting point and
costs about six EBR blocks on the iCE40HX4K — cheap relative to its value.

`TRC_CTRL` (0x18):

| Bit | Name | Meaning |
|---|---|---|
| 0 | `TRC_EN` | Capture enable |
| 1 | `TRC_ARM` | Arm the trigger |
| 2 | `TRC_ONESHOT` | Stop capture when the buffer fills |
| 4:3 | `TRC_POS` | Trigger position: 00 = start, 01 = centre, 10 = end |
| 5 | `TRC_HALT_ON_TRIG` | Halt the CPU when the trigger fires |
| 6 | `TRC_FILTER_OPFETCH` | Capture only opcode fetches |

Trigger condition: `(address & ~TRC_TRIG_MASK) == (TRC_TRIG_ADDR & ~TRC_TRIG_MASK)`,
optionally qualified by `RWB` and by `VPA`/`VDA` encoded in the upper bits of
`TRC_TRIG_ADDR`.

This is a logic analyser for the price of one EBR block and a comparator. Build
it at E3. Retrofitting it after the first difficult kernel bug is the wrong
order.

---

## 8. Watchdog and failure containment

Every memory transaction is covered by a timeout counter. On expiry the agent:

1. Abandons the transaction,
2. Releases the bus and PHI2 (or leaves the CPU halted if it was already),
3. Sets `ERR_TIMEOUT`,
4. Returns to `IDLE`.

The timeout must be generous enough to cover a worst-case SDRAM access with an
intervening auto-refresh, and short enough that a human notices it as a delay
rather than a hang. 100 µs at the Helium core clock is the starting value.

**The agent must never be able to hang the console.** If it does, the engineer
loses the only view into a board that is, by hypothesis, already misbehaving.
This constraint takes precedence over transaction completion in every case.

A separate consideration: the existing system watchdog that converts hung cache
fills into NMI or ABORT must be **suppressed while the CPU is halted by the
Debug Agent**, or every debug session will end in a spurious abort.

---

## 9. Enable gating

The Debug Agent bypasses every protection mechanism in the system. It requires a
gate.

`DEBUG_ENABLE` is a Helium input. When deasserted, the Debug Agent:

- forces `DBG_CTRL.ENABLE` to zero and ignores writes to it,
- rejects all commands with `ERR_STATE`,
- continues to answer reads of `DBG_ID` and `DBG_STATUS` (so the console can
  report *why* it is not working, rather than appearing broken).

For the development boards, a pull-up and a jumper to ground. The point is not
security against an attacker with physical access — that is unachievable and not
a goal — but to make the privileged path an explicit, visible, deliberate state
of the board.

---

## 10. Console protocol

### 10.1 Transports

Two, both always active:

- **USB-CDC** over the RP2040's native USB.
- **Physical UART** on a 3-pin header, 115200 8N1, 3.3 V.

The physical UART is not redundant. At E0 there is no way to distinguish a
firmware fault from a USB stack fault, and the UART removes that ambiguity for
the cost of three pins. It also survives the RP2040 USB peripheral being
reconfigured for PIO-USB HID work.

Output is mirrored to both. Input is accepted from either, first-come.

### 10.2 Command grammar

Numbers are hexadecimal by default; a `#` prefix denotes decimal. Addresses may
carry a space qualifier: `p:` for physical (default), `v:` for virtual.

**Memory**

```
md  <addr> [len]              dump memory (default 256 bytes)
mw  <addr> <val> [val ...]    write values
mf  <addr> <len> <val>        fill
mc  <addr1> <addr2> <len>     compare two regions
ms  <addr> <len> <pattern>    search
mt  <addr> <len> [test]       memory test: march-c, addr-in-addr, walking-1
```

**Mode**

```
mode                          show current mode flags
mode phys | virt              select address space
mode int | ext                select internal / external cycle
mode asid <n>                 set ASID for virtual accesses
mode width 8 | 16             set access width
mode nocache on | off         cache bypass (prints a warning)
```

**CPU**

```
halt                          halt at next cycle boundary
run                           resume
step [n]                      single bus cycle
stepi [n]                     single instruction
reset [hold]                  pulse or hold CPU reset
reg                           registers inferred from trace
reg -f                        registers via forced debug stub (intrusive)
dis <addr> [n]                disassemble
```

**Trace**

```
trace arm [addr] [mask]       arm trigger
trace on | off
trace pos start|centre|end
trace dump [n]                dump records, disassembled
trace filter opfetch on|off
```

**MMU**

```
tlb dump                      all TLB entries
tlb probe <vaddr>             translate via TLB
tlb flush
pt walk <vaddr>               full table walk, showing each level
pt dump <asid>                summary of mapped ranges
cache flush | inval
cache stats                   hit/miss counters
```

**Storage and files**

```
ld <file> <addr>              load from microSD into memory
sv <addr> <len> <file>        save memory to microSD
boot <file>                   load, set reset vector, release CPU
```

**System**

```
id                            gateware ID and build revision
status                        full status register decode
err                           last error, decoded; clears it
help [cmd]
```

### 10.3 Console behaviour requirements

- **Every error is reported with its decoded cause.** Never a bare failure.
- **Long operations show progress.** A 32 MB SDRAM march test takes minutes; a
  silent console during that time is indistinguishable from a hang.
- **Ctrl-C aborts** the in-flight operation via `CMD_ABORT`.
- **`md` output is annotated** with the region name (SRAM cache, SDRAM, VRAM
  aperture, bank `$FF`) derived from the physical memory map.
- **The prompt shows the mode.** `p16>` for physical/16-bit, `v8:0042>` for
  virtual/8-bit/ASID 0x42. Mode errors are the most common source of confusing
  results, and making the mode ambient removes most of them.

---

## 11. Bring-up staging

| Stage | Debug Agent capability | Validates |
|---|---|---|
| **E0** | RP2040 only: LED, UART, USB-CDC, microSD, bitstream load | Power rails, RP2040 firmware, SD stack |
| **E1** | `DBG_ID` readable; physical SRAM peek/poke; `mt` | SPI link, Helium clock, SRAM controller, byte enables |
| **E2** | Physical SDRAM peek/poke; cache flush/inval; `cache stats` | SDRAM controller, refresh, cache controller, coherence |
| **E3** | CPU out of reset; halt/step/run; trace | PHI2 gating, `BE` handoff, arbiter, bus timing |
| **E4** | Virtual mode; TLB and page-table inspection | MMU, walker, ASID handling, table ordering invariant |
| **E5+** | External cycles to `$FE` and FPGA-B | Inter-FPGA bus visibility, VRAM aperture |

E1 is the stage that pays for the whole design. Being able to march-test SRAM
before any CPU exists converts the hardest class of bring-up bug — intermittent
memory faults appearing as random software misbehaviour — into a direct,
reproducible measurement.

---

## 12. Open items

Blocking schematic capture:

1. **`BE` routing** — confirm Helium drives it; allocate the pin.
2. **Bidirectional CPU-side pins on Helium** — confirm `inout` on address and
   data; check I/O bank and pin-count impact on the TQ144 assignment sheet.
3. **`DBG_CSN` pin allocation** on both RP2040 and Helium.
4. **`DEBUG_ENABLE` strap** — pin, pull, jumper footprint.
5. **Physical UART header** — 3-pin, placement, silkscreen.
6. **`DBG_IRQN`** — decide whether to spend the pin, or poll only.

Blocking gateware:

7. **ASID width** — `DBG_ASID` is specified as 16-bit; narrow it once the MMU
   decision lands. Carried over as a dependency from the MMU work.
8. **Turnaround timing for `BE`** — derive the exact clock count from the
   W65C816S datasheet at 3.3 V and the intended PHI2 frequency.
9. **Clock domain crossing** — the SPI domain and the Helium core domain are
   asynchronous. Specify the synchroniser and the command-handshake protocol
   formally; this is where subtle intermittent failures will otherwise live.
10. **Trace buffer depth** — pick a number against the remaining EBR budget
    after the cache tags are allocated.
11. **Arbiter priority** — where the Debug Agent sits relative to the CPU port,
    the FPGA-B port, and SDRAM refresh. Refresh must remain highest.

Deferred, not ruled out:

12. Breakpoint comparators (address match forcing halt) — a natural extension of
    the trace trigger, deferred to keep E3 small.
13. Watchpoints on data value as well as address.
14. GDB remote serial protocol stub on the RP2040, so a host debugger can drive
    the agent. Attractive, but only worth doing once the command set is stable.

---

## 13. Summary of decisions

| Decision | Rationale |
|---|---|
| RP2040 is not a bus master | Pin budget; reuse of Helium's memory path; coherence |
| Debug Agent is an arbiter peer | No duplicated memory path, no second source of truth |
| Helium drives `BE` | Bus handoff must be a synchronous transition, not a cross-domain race |
| Registers are SPI-only, not CPU-visible | Privileged path must not depend on software correctness |
| Accesses go through the cache controller | A debug tool that disagrees with the CPU is worse than none |
| Per-transaction watchdog | The console must never hang |
| `DEBUG_ENABLE` gate from day one | Make the privileged state explicit and visible |
| Physical UART alongside USB-CDC | Removes firmware/USB ambiguity at E0 for three pins |
| Trace buffer built at E3, not later | Logic analyser for one EBR block; retrofitting is the wrong order |

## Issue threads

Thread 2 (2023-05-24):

BL702 UART+JTAG

dmolinagarcia, 2023-05-24:
Explore the options to use the BL702 onboard the TANG NANO 1k as a dual UART+JTAG. Compare the TANG schematich agaings the dual uart schematic on sipeed github.

Try to reflash the BL702 on board the Tang Nano. I think the boot button is not available though.

It will be on the outer board (ciama2k prototipe). Give it a try there.

dmolinagarcia, 2023-05-24:
The boot button is not on the board. Also, the pull up resistor isn't there either. The pulldown is there, but not the pull up. Everything is soooo tiny....

dmolinagarcia, 2023-10-10:
On the CIAMA2k project, I've managed to reflash the BL702 and have a suitable hardware for a debugger.

But... After this time, this doesn't seem like the best approach. A UART inside the northbridge is the preferred option now.

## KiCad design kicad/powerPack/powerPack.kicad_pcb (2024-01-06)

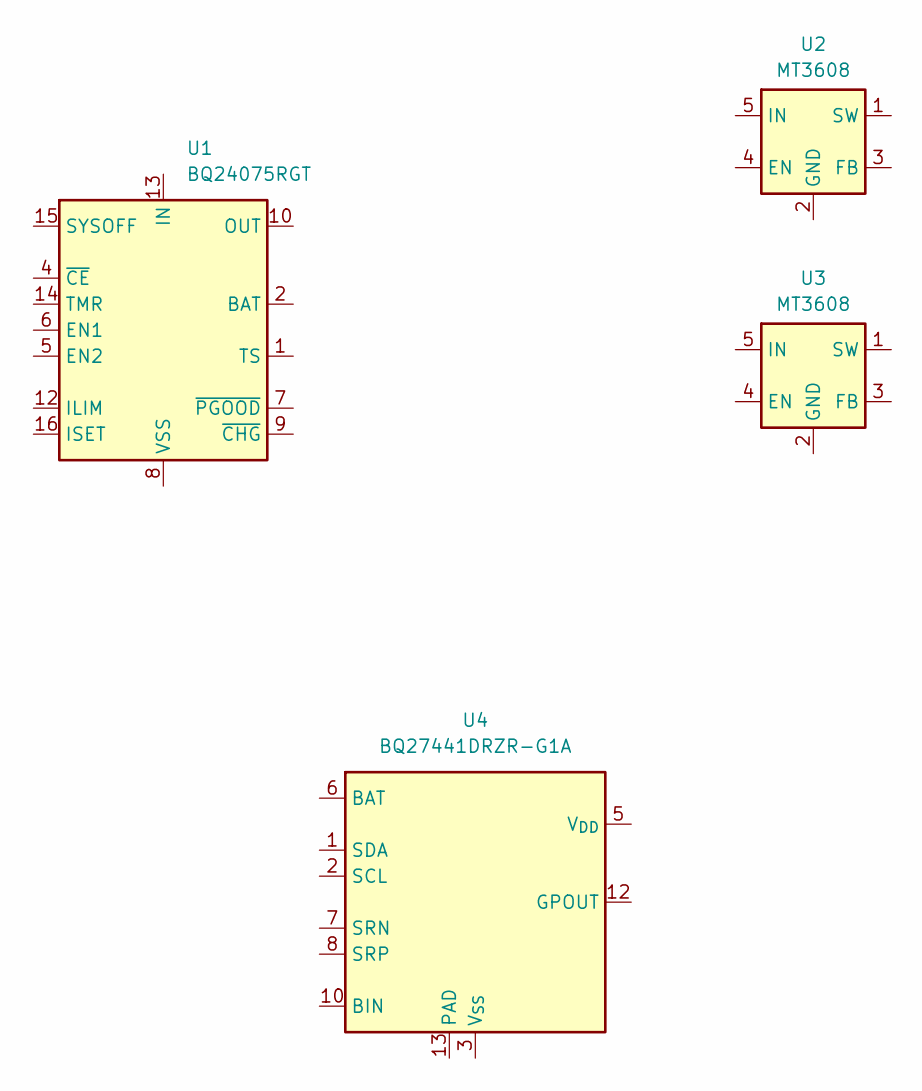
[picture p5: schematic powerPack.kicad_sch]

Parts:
U1: BQ24075RGT; VQFN-16-1EP_3x3mm_P0.5mm_EP1.6x1.6mm
U2, U3: MT3608; SOT-23-6
U4: BQ27441DRZR-G1A; Texas_S-PDSO-N12

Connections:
unnamed: U1.2 (BAT), U1.3 (BAT)
unnamed: U1.10 (OUT), U1.11 (OUT)
unnamed: U1.8 (VSS), U1.17 (VSS)

Board: 2 copper layers, 4 parts (0 on the bottom side), 3 nets, no tracks yet.

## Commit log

2023-01-05 Power Draft
2023-01-06 Drafting the battery
2023-02-05 Let's start with C Code!
    [boot.obj, demo.obj]
2023-02-20 C testing
    [demo.obj]
2026-08-16 docsV3 - Power Path REV.C
2026-08-17 Dark/Light switch
2026-08-18 Colorlight i9 Prototype
2026-08-22 Print style
2026-08-24 Adjusting the printed version
2026-09-09 Spartan 6 - 3 prototype sheets
2026-09-20 Style changes. Black and white for printing.
2026-09-24 Printing fixes
2026-09-24 Some tweaks on SD card and P1 prototype.
2026-09-26 Renumber D112–D115 and Q184–Q186 to D127–D130 and Q190–Q192
    #13 takes D112–D126 and Q184–Q188 for the C library, and #15 takes
    Q189, so this PR's decisions and questions move to the next free
    numbers:
    D112 → D127 D113 → D128 D114 → D129 D115 → D130
    Q184 → Q190 Q185 → Q191 Q186 → Q192
    They change wherever they appear: the entries in sheet Q, the links to
    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
